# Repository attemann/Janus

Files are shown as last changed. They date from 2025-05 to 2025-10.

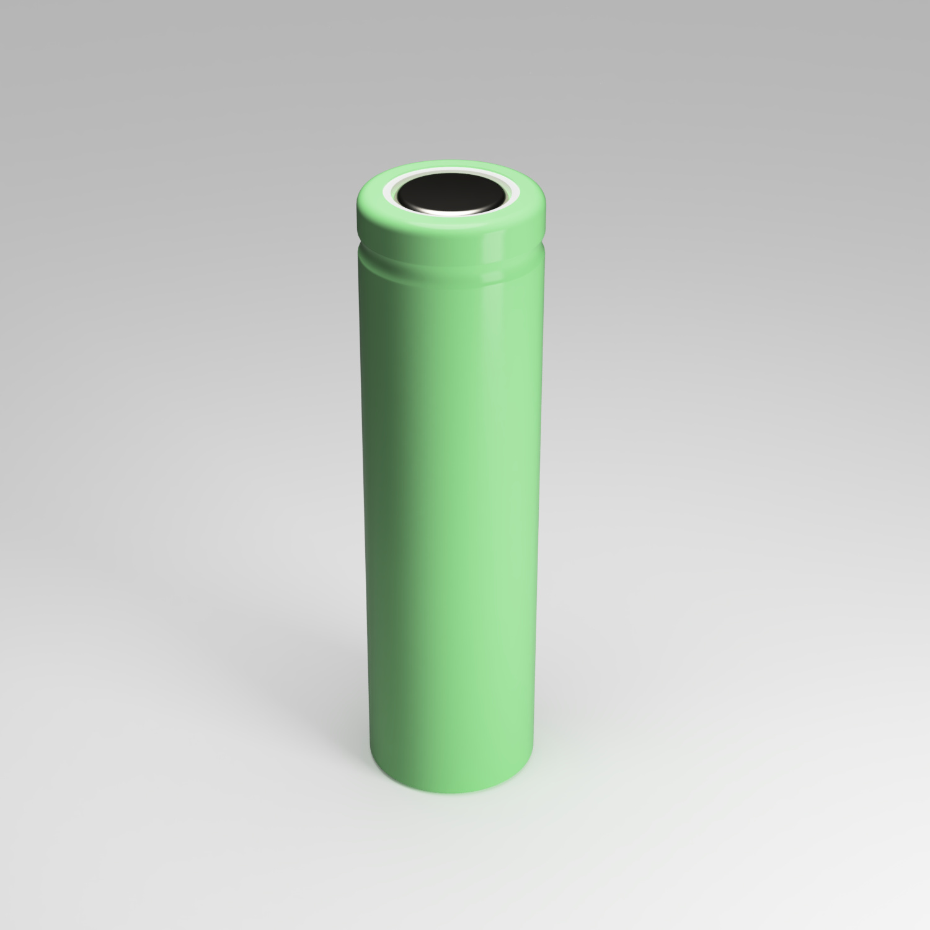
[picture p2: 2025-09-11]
Hardware/18650/Li Ion 18650 cell.jpg

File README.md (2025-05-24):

# RTKF3F – RTK-Based F3F Glider Training System

**Author:** Jan Olav Endrerud  
**Email:** joe2817@gmail.com  
**Version:** 15 May 2025

---

## Overview

RTKF3F is a high-precision, low-latency training system for F3F radio-controlled gliders using RTK GNSS technology. It detects base crossings automatically and provides real-time feedback without needing manned base stations.

---

## Features

- **RTK precision (≤10 cm)** for consistent flight detection
- **<20 ms latency** between event and audio feedback
- Fully **offline system** (no internet needed)
- Detailed **post-flight analysis** from logged events
- Compact airborne unit with GNSS and 868 MHz radio
- LCD and button interface on base station
- Designed for use on slopes with configurable A/B base orientation

---

## System Components

### Base Station (BS)

- UM980 RTK GNSS (base mode)
- ESP32-S3 microcontroller
- 2× RFM69HCW radios (TX: RTCM, RX: events)
- 2-line I2C LCD display
- Beeper for feedback
- 4-button user interface
- USB or battery powered (10+ hrs)

### Glider Unit (GU)

- UM980 RTK GNSS (rover mode)
- Seeed Studio XIAO ESP32-C6
- RFM69HCW radio (868 MHz)
- Beeper for status indication
- Max size: 40 × 20 mm (excluding antennas)
- Powered from RC battery

---

## Flight Operation

1. **Setup**
   - Place BS and perform GNSS survey-in
   - Select slope angle and A-base side
   - Set pilot location (PLOC)

2. **Flight**
   - Glider launches and crosses into task zone
   - GU detects base crossings and sends event to BS
   - BS triggers beeps and logs events

3. **Post-flight**
   - Use logs for analysis and performance improvement

---

## GU ↔ BS Communication

| Direction | Message | Description |
|---:|---|---|
| BS → GU | `MSG_FLIGHTSETTINGS` | Pilot offset, base side, slope angle |
| BS → GU | `MSG_RTCM` | RTCM3 corrections (1 Hz) |
| GU → BS | `EVT_*` Events | A/B base and safety line crossings |
| GU → BS | `EVT_ACK` | Acknowledgement of received settings |

**Event Codes:**
- `EVT_CROSS_A_IN`, `EVT_CROSS_B_OUT`, `EVT_AIRBORNE`, `EVT_LANDED`, etc.

---

## Wiring Overview

### Glider Unit (ESP32-C6)

| Pin | Function |
|---:|---|
| GPIO17  | UART TX → GNSS RX |
| GPIO18  | UART RX ← GNSS TX |
| GPIO10–12 | SPI (SCK, MOSI, MISO) |
| GPIO9 | SPI CS |
| GPIO8 | RFM69 DIO0 (IRQ) |

### Base Station (ESP32-S3)

| Pin | Function |
|---:|---|
| GPIO4/5 | UART to GNSS |
| GPIO6–9 | SPI & DIO0 for RFM RX/TX |
| GPIO18/19 | I2C LCD |
| GPIO20–23 | Buttons |

---

## Configuration Summary

### UM980 (Base)
```text
CFG-RTK-MODE = BASE
CFG-SURVEYIN-ENABLE = TRUE
CFG-SURVEYIN-MIN-DURATION = 120
CFG-SURVEYIN-POS-ACCURACY = 2.0
CFG-MSG UART2 RTCM3 1005/1074/1084/1094/1124 = 1Hz
```

### UM980 (Rover)
```text
CFG-RTK-MODE = ROVER
CFG-PORT UART2 = RTCM_INPUT
CFG-RATE = 25
CFG-MSG UART1 NAV-RELPOSNED = 25Hz
CFG-DYNMODEL = AIRBORNE 2g
```

---

## Development Roadmap

- [ ] Support for Jeti Ex-bus / F3FTool
- [ ] Safety line definition and events
- [ ] Optional voice/audio module

---

## License

MIT License

Copyright (c) 2025 Jan Olav Endrerud

Permission is hereby granted, free of charge, to any person obtaining a copy
of this software and associated documentation files (the “Software”), to deal
in the Software without restriction, including without limitation the rights
to use, copy, modify, merge, publish, distribute, sublicense, and/or sell
copies of the Software, and to permit persons to whom the Software is
furnished to do so, subject to the following conditions:

The above copyright notice and this permission notice shall be included in all
copies or substantial portions of the Software.

THE SOFTWARE IS PROVIDED “AS IS”, WITHOUT WARRANTY OF ANY KIND, EXPRESS OR
IMPLIED, INCLUDING BUT NOT LIMITED TO THE WARRANTIES OF MERCHANTABILITY,
FITNESS FOR A PARTICULAR PURPOSE AND NONINFRINGEMENT. IN NO EVENT SHALL THE
AUTHORS OR COPYRIGHT HOLDERS BE LIABLE FOR ANY CLAIM, DAMAGES OR OTHER
LIABILITY, WHETHER IN AN ACTION OF CONTRACT, TORT OR OTHERWISE, ARISING FROM,
OUT OF OR IN CONNECTION WITH THE SOFTWARE OR THE USE OR OTHER DEALINGS IN THE
SOFTWARE.
---

## Contact

Feel free to reach out with ideas or improvements:  
📧 joe2817@gmail.com

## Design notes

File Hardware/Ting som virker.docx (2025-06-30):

Slå av melding

UNLOG COM1 GPGGA

Slå på melding

gpgga COM1 1

Sette i RTK base modus

MODE BASE TIME 60

→ Mål i 60 sekunder, og bruk snittet av posisjonene som baseposisjon.

Du kan endre 60 til opp til 3600 sekunder for høyere nøyaktighet.

(Se også MODE BASE TIME 60 5 for å legge til et posisjonstoleransekrav.)

ESP32-S3-Devkit1-C sender

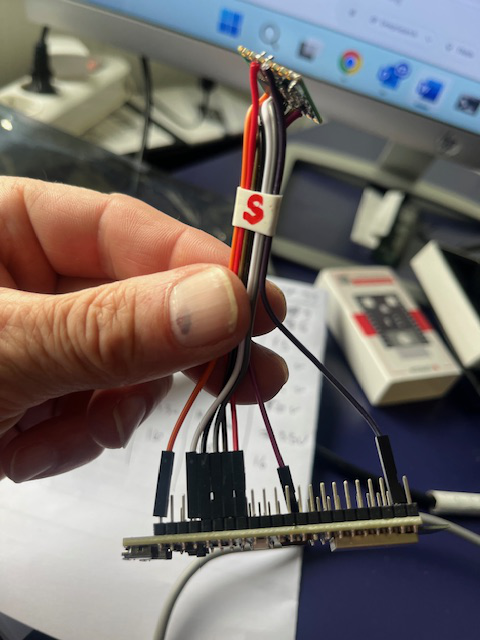
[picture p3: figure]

ESP32-S3-Devkit1-C mottager

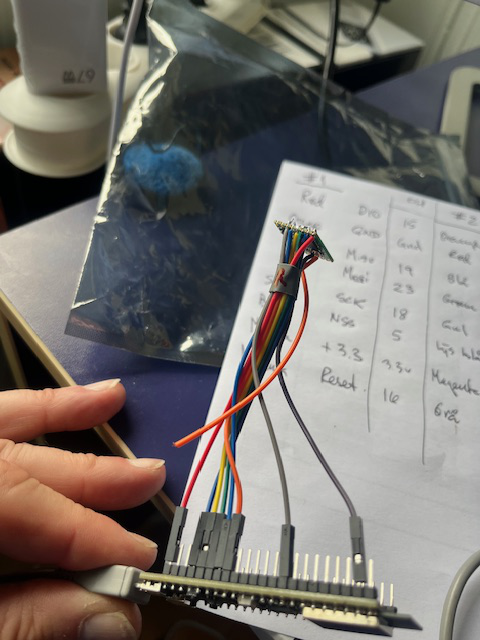
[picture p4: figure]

#include <RFM69.h>

#include <SPI.h>

#define NODE_ID 2 // This is the Gateway ID (receiver)

#define NETWORK_ID 100

#define FREQUENCY RF69_868MHZ

#define RFM69_CS 10

#define RFM69_IRQ 9

#define RFM69_RST -1

RFM69 radio(RFM69_CS, RFM69_IRQ, true);

void

setup() {

Serial.begin(115200);

delay(10);

SPI.begin(12, 13, 11, 10); // Explicit SPI pins, matching sender

if (RFM69_RST != -1) {

pinMode(RFM69_RST, OUTPUT);

digitalWrite(RFM69_RST, LOW);

delay(10);

digitalWrite(RFM69_RST, HIGH);

delay(10);

}

Serial.println("Starting RFM69 receiver...");

if (!radio.initialize(FREQUENCY, NODE_ID, NETWORK_ID)) {

Serial.println("Radio initialization failed!");

while (1);

}

radio.setHighPower();

radio.encrypt(NULL); // No encryption, matching sender

Serial.println("RFM69 initialized");

}

void loop() {

if (radio.receiveDone()) { // Check if data is received

if (radio.DATALEN > 0) {

Serial.print("Received from Node ");

Serial.print(radio.SENDERID);

Serial.print(": [");

for (byte i = 0; i < radio.DATALEN; i++) {

Serial.print((char)radio.DATA[i]);

}

Serial.print("], RSSI: ");

Serial.println(radio.RSSI);

// Acknowledge receipt (optional, but useful for reliability)

if (radio.ACKRequested()) {

radio.sendACK();

Serial.println("ACK sent");

}

// Blink LED to indicate reception

digitalWrite(RGB_BUILTIN, HIGH);

delay(200);

digitalWrite(RGB_BUILTIN, LOW);

}

}

}

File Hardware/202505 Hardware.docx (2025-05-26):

## 20×40 mm target with minimal BOM and full support for:

- Native USB
- RFM69HCW (SPI)
- UM980 GNSS (UART)
- Optional buzzer
- Power from USB or 5–8V

## ESP32-C6FH4 Hardware Design Overview

📌 Core Specs (C6FH4)

- QFN-48, 5×5 mm
- Native USB-CDC (no external USB-UART needed)
- 4 MB flash integrated
- Runs at 3.3
- No shielding required if Wi-Fi/BLE is unused
- 12 MHz crystal recommended

## Required Components and Connections

1. Power Supply

You want to support:

- USB (5V)
- External 5–8V

Recommended:

- MP2338 buck converter (efficient, 5–24 V → 3.3 V)
- OR AP2112K or XC6220 (LDO, 5–6 V → 3.3 V)

🔌 Connect 3.3 V output to:

- VDD3P3_CPU
- VDD3P3_RTC
- Decouple with 10 µF + 0.1 µF caps

2. USB Interface (native USB-CDC)

Pins:

- GPIO19 → USB D−
- GPIO20 → USB D+

Passives:

- 22 Ω series resistors on D+ and D− (optional if short traces)
- Optional ESD protection (e.g., USBLC6-2SC6)

Connector:

- USB-C (with CC resistors) or micro-USB

3. Crystal

- 12 MHz crystal (e.g., ECS-120-20-4X)
- Load caps: 2 × 18–22 pF
- Use close layout with ground guard

4. RFM69HCW

Interface: SPI

Pins (example):

- MOSI → GPIO6
- MISO → GPIO5
- SCK → GPIO4
- NSS → GPIO7
- DIO0 → GPIO8 (interrupt)

Use 0.1 µF decoupling cap close to VCC pin.

5. UM980 GNSS Module

Interface: UART

Pins (example):

- TXD → GPIO1
- RXD → GPIO2

Baud rate: 115200 (typical)

Level shifting not needed — both run at 3.3 V

6. Miniature Beeper

Use GPIO + NPN transistor to drive buzzer:

- GPIO10 → 1kΩ → base of 2N3904
- Emitter → GND
- Collector → Negative side of buzzer

Positive side → 3.3V

Buzzer: 5×5×1.8 mm passive piezo (e.g., CPT-5018C)

7. Boot/Reset Logic (Optional)

- GPIO9 → BOOT (pull LOW to enter flash mode)
- EN → reset (pull LOW to reset chip)

You can use RTS/DTR from USB-to-PC to control these via a transistor auto-reset circuit (or omit if using USB-native flashing only).

8. Programming

No USB-to-UART chip needed. Flash directly using:

esptool.py --chip esp32c6 --port COMx write_flash 0x0 firmware.bin

🧠 Flash Memory for Settings

Use ESP32 NVS (Non-Volatile Storage) API:

- Stores key-value data in internal flash
- Reliable across reboots and power loss
- Available in Arduino and ESP-IDF

✅ Pin Usage Summary (example)

Purpose ESP32-C6 Pin

USB D− GPIO19

USB D+ GPIO20

RFM69 NSS GPIO7

RFM69 DIO0 GPIO8

SPI MOSI GPIO6

SPI MISO GPIO5

SPI SCK GPIO4

UM980 RX GPIO1

UM980 TX GPIO2

Buzzer GPIO10

BOOT (option) GPIO9

EN (reset) EN pin

🧩 1. USB-C Connection Diagram (Native USB for ESP32-C6)

✅ Objective:

- Use USB-C connector to connect ESP32-C6FH4’s native USB-CDC interface
- Add CC pull-down resistors so hosts detect it as a USB device
- Add optional ESD protection

📌 USB-C Pinout (for USB 2.0 only)

You only need USB 2.0 D+/D−, GND, and VBUS:

USB-C Receptacle (Front View, PCB side)

┌───────────────┐

| A1 ─ GND | B1 ─ GND

| A2 ─ TX1+ | B2 ─ TX2+

| A3 ─ TX1− | B3 ─ TX2−

| A4 ─ VBUS | B4 ─ VBUS

| A5 ─ CC1 * | B5 ─ CC2 *

| A6 ─ D+ →───┐| B6 ─ D+ →──┐

| A7 ─ D− →───┘| B7 ─ D− →──┘

| A8 ─ SBU1 | B8 ─ SBU2

| A9 ─ VBUS | B9 ─ VBUS

| A10─ RX2− | B10─ RX1−

| A11─ RX2+ | B11─ RX1+

| A12─ GND | B12─ GND

└───────────────┘

🔧 Schematic Snippet

VBUS ──────> 5V input to MP2338

D+ (A6, B6) ──────> GPIO20 (ESP32-C6)

D− (A7, B7) ──────> GPIO19 (ESP32-C6)

CC1 ───┬── 5.1kΩ ──> GND

└── Optional ESD diode (e.g., USBLC6)

CC2 ───┬── 5.1kΩ ──> GND

└── (same)

GND ───────────────> GND

⚠️ Notes:

- Use one 5.1 kΩ pull-down on each CC pin (CC1, CC2) to signal to the host that your device is a USB peripheral.
- Do not connect TX/RX or SBU — those are for USB 3.0 or alternate modes.
- Add 22 Ω resistors in series on D+ and D− (optional, if trace is <1" and well-matched).
- Optional: Add TVS diode array (e.g. ESD protection: USBLC6-2SC6 or PESD5V0S1UL).

⚡ 2. Power Tree with MP2338 (5–8 V input)

✅ Requirements:

- Input: 5–8 V from USB or external
- Output: 3.3 V to power ESP32-C6, RFM69, UM980, and buzzer

📌 MP2338 Setup (Simplified)

Pin | Connect to
VIN | 5–8 V input (VBUS or ext)
EN | Tie to VIN (via 10k pull-up or direct)
SW | 3.3V output node (to inductor)
FB | Feedback from VOUT (voltage divider)
GND | Ground plane
BST | Bootstrap cap (0.1 µF) between SW and BST

🔧 Schematic Snippet

plaintext

CopyEdit

VIN (USB or ext) ─────┐

[CIN] 10µF

VIN (MP2338)

EN ← VIN

+--------+

| MP2338 |

+--------+

SW ────┬───→ Inductor 2.2 µH →────┐

[D1] Schottky diode |

| [COUT] 10µF

GND |

VOUT (3.3 V)

↓

┌───────────────────────────────┐

│ Powers: ESP32, RFM69, UM980 │

└───────────────────────────────┘

FB → voltage divider: 3.3V = VREF × (1 + R1/R2)

Use: R1 = 100k, R2 = 100k (to get ~3.3V)

CIN: 10–22 µF
COUT: 10–22 µF
Inductor: 2.2–4.7 µH
D1: 1A Schottky (e.g., SS14)

🧠 Optional Enhancements

- Add reverse-polarity protection on VIN (Schottky or PFET)
- Add a simple PTC fuse on VBUS
- Use a buck-boost if needing 3.3 V from <5 V sources occasionally

✅ Combined Summary

- USB-C with 5.1 k CC resistors and D+/D− → ESP32-C6
- MP2338 drops 5–8 V input to clean 3.3 V for all components
- Minimal parts, <20×40 mm layout achievable
- Fully USB flashable with no buttons, no UART chi

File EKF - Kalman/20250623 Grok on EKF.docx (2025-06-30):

In F3F RC model aircraft gliding, turn A and B must be detected with high precision. Distance between A and B base is 100 meters. RTK base will be positioned > 100 meters from pilot and bases. Gliders are performing high-G turns at each base (15-20G), flying in 100-200 km/h. I want to use RTK in RELPOSNED mode, rover unit in glider, fixed RTK base close to pilot. Using UM980 RTK GPSes. Goal is at least decimenter precision, best centimeter level. Turn detection will be position relative to RTK base. MIcrocontroller in glider will be ESP32. 868 MHz radio will report turn detection back to pilot.

- I want an overview ofsuitable algorithms to integrate 6 axis IMU with GNSS data to improve precision
- suitable IMUs

To achieve high-precision turn detection (decimeter to centimeter level) for F3F RC model aircraft gliding with high-G turns (15-20G) at speeds of 100-200 km/h, integrating a 6-axis IMU with GNSS data (specifically using the UM980 RTK GPS in RELPOSNED mode) and an ESP32 microcontroller is a feasible approach. The goal is to detect turns at bases A and B, 100 meters apart, with the RTK base stationed >100 meters from the pilot and bases, and report detections via an 868 MHz radio. Below is an overview of suitable algorithms for IMU-GNSS integration and recommended IMUs for high-G environments.

1. Algorithms for Integrating 6-Axis IMU with GNSS Data

To achieve decimeter to centimeter-level precision for turn detection, you need robust sensor fusion algorithms that combine high-rate IMU data (accelerometers and gyroscopes) with GNSS position data from the UM980 RTK GPS. The high-G turns and high speeds demand algorithms that can handle dynamic motion, mitigate IMU drift, and leverage RTK’s centimeter-level accuracy. Below are suitable algorithms, focusing on their applicability to your F3F gliding scenario:

a. Extended Kalman Filter (EKF) - Tightly Coupled Integration

Description: The EKF is widely used for IMU-GNSS integration, particularly in tightly coupled systems where raw GNSS measurements (pseudoranges, carrier phases) are fused with IMU data to estimate position, velocity, and attitude. It accounts for non-linear dynamics and sensor noise, making it suitable for high-G, high-speed environments like F3F gliding.

Advantages:

- Provides centimeter-level accuracy when RTK corrections are available, leveraging the UM980’s multi-constellation (GPS, GLONASS, Galileo, BeiDou) and dual-frequency (L1/L2) capabilities.
- Mitigates IMU drift by continuously updating with GNSS data, critical for sustained high-G maneuvers.
- Handles GNSS outages (e.g., brief signal loss during turns) by relying on IMU dead-reckoning.
- Supports RELPOSNED mode by incorporating relative positioning data directly into the state estimation.

Implementation:

- State vector typically includes position, velocity, orientation (quaternion), and sensor biases (accelerometer and gyroscope).
- IMU data (sampled at 100-1000 Hz) predicts the state, while GNSS data (1-20 Hz from UM980) corrects it.
- Use a 42+ state EKF (as in high-end INS systems) to model complex error sources like IMU biases, scale factors, and GNSS multipath.
- The ESP32’s processing power (dual-core, up to 240 MHz) can handle a simplified EKF for real-time computation, though optimization (e.g., fixed-point arithmetic) may be needed.

Challenges:

- Computational complexity may strain the ESP32, requiring efficient code or precomputed matrices.
- Requires precise time synchronization between IMU (high-rate) and GNSS (lower-rate, up to 20 Hz for UM980) to avoid latency errors.

Suitability: Ideal for F3F due to its robustness in dynamic environments and ability to leverage RTK’s high precision. Use open-source libraries like RTKLIB for RTK processing and fuse with IMU data via custom EKF code.

b. Loosely Coupled Kalman Filter

Description: In a loosely coupled approach, the GNSS receiver (UM980) computes a position solution independently, which is then fused with IMU data using a Kalman filter to refine position and velocity estimates.

Advantages:

- Simpler to implement on the ESP32 due to lower computational demands.
- Works well when RTK corrections are consistently available, providing centimeter-level accuracy.
- Easier to integrate with the UM980’s NMEA output (e.g., GGA, RMC messages).

Challenges:

- Less robust during GNSS outages or multipath errors (common in dynamic turns near terrain).
- Does not fully exploit raw GNSS measurements, potentially██

Implementation:

- Use UM980’s RELPOSNED output (relative position in NED frame) to provide high-precision position data.
- IMU data corrects short-term GNSS errors and smooths position estimates during high-G turns.
- Suitable for real-time turn detection by comparing position against known base coordinates (A and B).

Challenges (continued):

- May struggle with high-G dynamics if GNSS signal quality degrades, as it relies on processed GNSS solutions rather than raw measurements.

Suitability: Viable for F3F if RTK corrections are reliable, but less robust than tightly coupled EKF in challenging GNSS conditions. Simpler to implement on resource-constrained platforms like the ESP32.

c. Attitude-Estimation-Free GNSS/IMU Integration

Description: A novel approach that avoids explicit attitude estimation, using constraints based on accelerometer magnitude and gyroscope angular changes to fuse IMU and GNSS data.

Advantages:

- Reduces computational load by eliminating 3D attitude from the state vector, suitable for the ESP32’s limited processing power.
- Robust to IMU mounting misalignments, which is beneficial for RC gliders where precise IMU alignment may be challenging.
- Improves accuracy in GNSS-challenged environments (e.g., multipath during low-altitude turns) by relying on IMU constraints.

Implementation:

- Uses accelerometer data to constrain position updates based on acceleration magnitude.
- Gyroscope data constrains velocity vector angles, aiding turn detection.
- Can be implemented with a simpler filter (e.g., modified EKF or particle filter) to reduce ESP32 computational load.
- Integrates UM980’s RELPOSNED output for relative positioning to bases A and B.

Challenges:

- Less mature than EKF, with fewer off-the-shelf implementations.
- May require custom tuning for high-G environments to ensure stability.
- Suitability: Promising for F3F due to its computational efficiency and robustness to GNSS errors, but requires custom algorithm development and validation for high-G dynamics.

d. Deep Learning-Based Sensor Fusion

Description: Uses neural networks (e.g., LSTM, ConvNet) to learn complex relationships between raw IMU measurements and GNSS data, reducing drift and improving position estimates.

Advantages:

- Can implicitly correct IMU errors (bias, noise) without explicit modeling, improving accuracy in high-G turns.
- Adapts to complex motion patterns in F3F gliding through training on relevant datasets.

Challenges:

- Requires significant computational resources, likely infeasible for real-time processing on the ESP32.
- Needs extensive training data (e.g., high-precision IMU or GNSS ground truth), which may be hard to collect for F3F-specific maneuvers.
- Not yet widely validated for high-G, high-speed scenarios like F3F.

Suitability: Less practical for real-time use on the ESP32 due to computational constraints, but could be used offline for post-processing or training a simpler model for deployment.

Recommended Algorithm

Tightly Coupled EKF: This is the most suitable for F3F gliding due to its ability to leverage the UM980’s raw RTK measurements (centimeter-level accuracy) and handle high-G dynamics with IMU dead-reckoning. It balances precision and robustness, though it requires careful implementation to fit within the ESP32’s capabilities. Use RTKLIB for RTK processing and a custom EKF for fusion, with time synchronization ensured via GPS clock signals.

Implementation Notes:

- Sample IMU at 100-1000 Hz to capture high-G turn dynamics (15-20G, rapid angular changes).
- Use UM980’s 20 Hz output for frequent corrections.
- Implement turn detection by comparing RELPOSNED coordinates against known base positions (A and B, 100 m apart) with a threshold (e.g., 10 cm radius around base).
- Transmit turn detection events via 868 MHz radio using a lightweight protocol (e.g., simple binary messages).

2. Suitable IMUs for High-G Turns

For F3F gliding, the IMU must withstand high-G forces (15-20G), provide high sampling rates (100-1000 Hz) for dynamic motion, and have low noise and drift to minimize errors during short GNSS outages. It should also be lightweight, compact, and compatible with the ESP32’s interfaces (e.g., SPI, I2C). Below are recommended 6-axis IMUs (3-axis accelerometer + 3-axis gyroscope) suitable for this application:

a. Bosch BMI160

Specifications:

- Accelerometer Range: ±16g (sufficient for 15-20G turns).
- Gyroscope Range: ±2000°/s (handles high angular rates in turns).
- Sampling Rate: Up to 1600 Hz, suitable for capturing rapid dynamics.
- Noise Density: ~0.004 m/s²/√Hz (accelerometer), ~0.007°/s/√Hz (gyroscope).
- Interface: I2C/SPI, compatible with ESP32.
- Size/Weight: 3x3x0.83 mm, ~0.5g, ideal for lightweight RC gliders.
- Power: Low power (~0.9 mA in high-performance mode).

Advantages:

- Cost-effective and widely available.
- Robust for high-G environments, used in UAVs and automotive applications.
- Small size and low power suit RC glider constraints.

Challenges:

- Tactical-grade performance but may exhibit drift over long periods without GNSS correction.
- Requires calibration for bias and scale factor errors.

Suitability: Excellent for F3F due to its high-G tolerance, compact size, and ESP32 compatibility. Pair with EKF for drift correction.

b. Inertial Sense μINS

Specifications:

- Accelerometer Range: ±16g (extendable to ±40g in some configurations).
- Gyroscope Range: ±2000°/s.
- Sampling Rate: Up to 1000 Hz.
- Noise Density: Tactical-grade, comparable to high-end MEMS (specific values depend on model)
- Interface: UART/SPI, ESP32-compatible.
- Size/Weight: ~17x17x7 mm, ~2g, slightly heavier but compact.

Power: ~50 mA (higher than BMI160 but manageable).

Advantages:

- Tactical-grade performance with low noise and drift, ideal for high-G turns.
- Integrated GNSS option (can be used as backup or for testing).
- Proven in UAV and robotics applications.

Challenges:

- Higher cost than BMI160 (~$100-$200 vs. ~$10).
- Slightly larger and heavier, though still suitable for RC gliders.
- Suitability: High-performance choice for F3F, especially if budget allows, due to its robustness and precision in dynamic environments.

c. Analog Devices ADIS16488A

Specifications:

- Accelerometer Range: ±18g (suitable for 15-20G).
- Gyroscope Range: ±450°/s (may need configuration for extreme turn rates).
- Sampling Rate: Up to 2460 Hz, excellent for high-G dynamics.
- Noise Density: ~0.0045 m/s²/√Hz (accelerometer), ~0.005°/s/√Hz (gyroscope).
- Interface: SPI, compatible with ESP32.
- Size/Weight: ~47x47x14 mm, ~16g, heavier and larger than others.
- Power: ~200 mA, higher consumption.

Advantages:

- High precision and low noise, designed for aerospace applications.
- Robust in high-vibration, high-G environments.

Challenges:

- Significantly more expensive (~$1000+).
- Larger size and weight may be less ideal for small RC gliders.
- Higher power draw requires careful power management.

Suitability: Overkill for most F3F applications due to cost and size, but viable if maximum precision is needed and budget/space allow.

Recommended IMU

Bosch BMI160: Best balance of performance, cost, size, and power for F3F gliding. Its ±16g accelerometer and ±2000°/s gyroscope handle high-G turns, and its low cost (~$10) and small size (3x3 mm) make it ideal for RC gliders. The high sampling rate (up to 1600 Hz) ensures accurate capture of turn dynamics, and I2C/SPI interfaces integrate easily with the ESP32. Use with a tightly coupled EKF to achieve centimeter-level turn detection accuracy.

Additional Considerations

- Time Synchronization: Ensure precise synchronization between IMU and UM980 GNSS data using the GPS clock (PPS signal) to align high-rate IMU (100-1000 Hz) with GNSS (20 Hz). The ESP32 can use GPIO pins to capture PPS for sub-millisecond accuracy. Turn Detection Logic: Implement a simple algorithm on the ESP32 to detect when the glider’s RELPOSNED position (from UM980) falls within a predefined radius (e.g., 10 cm) of base A or B coordinates. Trigger an 868 MHz radio message (e.g., “TURN_A” or “TURN_B”) upon detection.
- Power Management: Use a lightweight LiPo battery (e.g., 3.7V, 500mAh) to power the ESP32, BMI160, UM980, and 868 MHz radio. Optimize firmware to minimize power draw (e.g., low-power modes for ESP32 when not processing).
- Calibration: Pre-flight calibration of IMU biases and scale factors is critical to minimize drift during high-G turns. Use ground-based GNSS data for initial alignment.
- RTK Corrections: Ensure the RTK base (>100 m from pilot and bases) provides reliable corrections via 868 MHz radio or another link. UM980’s multi-constellation support enhances robustness in dynamic environments.
- Software: Use RTKLIB for RTK processing (run on a ground station or precompute corrections) and program the ESP32 in C/C++ (e.g., Arduino or ESP-IDF framework) for EKF and turn detection logic. Libraries like TinyEKF can simplify EKF implementation.

Summary

- Algorithm: A tightly coupled EKF is recommended for integrating 6-axis IMU and UM980 RTK GNSS data, offering centimeter-level precision and robustness for high-G turns. It leverages raw GNSS measurements and corrects IMU drift effectively
- IMU: The Bosch BMI160 is the best choice due to its high-G tolerance (±16g), high sampling rate (up to 1600 Hz), low cost, and compact size, making it ideal for RC gliders and ESP32 integration.

System Overview:

- UM980 rover in the glider provides RELPOSNED data (centimeter-level) at 20 Hz.
- BMI160 samples at 100-1000 Hz, feeding high-rate motion data to the EKF.
- ESP32 runs the EKF, detects turns by comparing position to base coordinates, and transmits results via 868 MHz radio.
- RTK base provides corrections, ensuring high precision even at >100 m distance.

This setup achieves the desired decimeter to centimeter-level precision for turn detection in F3F gliding, handling the challenges of high-G turns and high speeds effectively. For implementation, start with the BMI160 and RTKLIB, and prototype the EKF on the ESP32 using open-source libraries, ensuring thorough testing in simulated high-G conditions.

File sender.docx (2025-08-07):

BASE_SURVEYING: Survey complete. Enabling RTCM...

GPS: Sending command: unlog

$command,unlog,response: OK*21

GPS: Sending command: rtcm1033 com2 10.0

$command,rtcm1033 com2 10.0,response: OK*1B

Sending �+�?

GPS: Sending command: rtcm1006 com2 10.0

$command,rtcm1006 com2 10.0,response: OK*1D

Sending �+�?

GPS: Sending command: rtcm1074 com2 1.0

$command,rtcm1074 com2 1.0,response: OK*28

Sending �+�?

GPS: Sending command: rtcm1124 com2 1.0

$command,rtcm1124 com2 1.0,response: OK*2C

Sending �+�?

GPS: Sending command: rtcm1084 com2 1.0

�>��$x��X���

�6^�Q��rC X�� ��� _բ���'�'��1$A�#n�� ��x��0��ɺ�"��G��

��x<�����w�b��?�'��|dc������݅�Q#R�#P��,��@Q��F@X�A H0 �EWN��©�%�$'�%�ě�Ku�m<�)���[GwP�y;>qT�����wx�q-��AH~׵~އ�Fj����{����Xv�A�?�g"��x9��W�a����N�8?��������0�uUWUU7UUU@<�Q���>���RH������$command,rtcm1084 com2 1.0,response: OK*27

Sending �+�?

GPS: Sending command: rtcm1094 com2 1.0

$command,rtcm1094 com2 1.0,response: OK*26

Sending �+�?

# Name | Freq | State | Sent | Description

1: rtcm1033 | 10.00 Hz | ENABLED | 0 | Antenna + Firmware

2: rtcm1006 | 10.00 Hz | ENABLED | 0 | Stat. Ref (with height)

3: rtcm1074 | 1.00 Hz | ENABLED | 0 | GPS MSM4

4: rtcm1124 | 1.00 Hz | ENABLED | 0 | BeiDou MSM4

5: rtcm1084 | 1.00 Hz | ENABLED | 0 | GLONASS MSM4

6: rtcm1094 | 1.00 Hz | ENABLED | 0 | Galileo MSM4

GPS: Sending command: saveconfig

$command,saveconfig,response: OK*55

BASE_SURVEYING: RTCM config done, entering OPERATING mode.

111 bytes RTCM1074

Sending fragmented RTCM message

RTCM_Fragmenter: Sending 111 bytes in fragments

RTCM_Fragmenter: Total fragments = 2

RTCM_Fragmenter: Sending fragment 1 of 2

0A 00 02 D3 00 69 43 20 00 58 E9 2B 62 00 20 20

A2 02 80 80 00 00 00 20 20 00 00 5F D6 8A 8E 92

98 9E A0 96 60 C4 D0 55 07 93 C4 61 8E A7 CC 3F

F9 05 85 E2 8C 3E DE 6B C0 DF CA 81 68

RTCM_Fragmenter: Sending fragment 2 of 2

0A 01 02 0D 77 1B 18 BD 4F 45 F0 FF 7F C3 FD 80

5E 3F 01 79 4F F7 98 23 DE 6F 0F CA 5B C2 CF C3

F5 DB DF D7 7A DB B9 BB BB BB BB 00 13 C8 CC AD

48 D4 32 D2 B8 06 1A C6

74 bytes RTCM1084

Sending fragmented RTCM message

RTCM_Fragmenter: Sending 74 bytes in fragments

RTCM_Fragmenter: Total fragments = 2

RTCM_Fragmenter: Sending fragment 1 of 2

0A 00 02 D3 00 44 43 C0 00 89 15 80 22 00 20 01

02 05 00 00 00 00 00 20 80 00 00 7D 22 24 A5 A1

A9 D2 CE 47 BC E1 99 C0 37 A9 2F 56 20 83 5F BF

1E 19 A4 C0 00 01 EA 4C 2F A9 32 A0 83

RTCM_Fragmenter: Sending fragment 2 of 2

0A 01 02 7F 7F 7D 9F 61 77 76 04 8C CA E4 70 80

F2 E4 49

129 bytes RTCM1094

Sending fragmented RTCM message

RTCM_Fragmenter: Sending 129 bytes in fragments

RTCM_Fragmenter: Total fragments = 3

RTCM_Fragmenter: Sending fragment 1 of 3

0A 00 03 D3 00 7B 44 60 00 58 E9 2B 62 00 20 0E

40 04 00 28 00 00 00 20 01 00 00 7F FE B6 A6 AE

AA B8 9A AB 00 45 E4 26 30 0E DF 10 3E AF 5D 54

A1 7F C2 FC EF 86 DE 31 F9 D3 EE BF 7C

RTCM_Fragmenter: Sending fragment 2 of 3

0A 01 03 EE EE E5 29 0A 04 FF F8 FF 61 EA F3 8F

AB CF 60 5F CC C0 00 01 EF 81 67 BE 12 3F E7 5E

FF 9B 1B F7 CD D7 DF 25 41 4A 29 85 2A 23 FF F6

97 FF E1 F7 76 17 57 75 57 57 40 00 42

RTCM_Fragmenter: Sending fragment 3 of 3

0A 02 03 DC 2B 46 E4 B0 40 D4 D1 48 F8 9A B9 30

187 bytes RTCM1124

Sending fragmented RTCM message

RTCM_Fragmenter: Sending 187 bytes in fragments

RTCM_Fragmenter: Total fragments = 4

RTCM_Fragmenter: Sending fragment 1 of 4

0A 00 04 D3 00 B5 46 40 00 58 E8 50 A0 00 20 00

96 04 08 48 30 00 00 20 82 00 01 45 57 4E C4 EE

C2 A9 C1 25 AA 24 27 AB 25 A6 C4 BB 24 AA 4A F6

1C 65 12 3C F2 29 1E 40 2E 9A 9D 08 B0

RTCM_Fragmenter: Sending fragment 2 of 4

0A 01 04 48 E0 6A 3D 94 75 F8 E9 70 39 20 5A 81

FE 43 9E 87 4A EE 79 A2 33 40 A8 9D 41 4F A2 29

0A 7C 94 82 28 9D E3 FE FC 00 00 10 00 00 78 23

D3 E0 94 20 7B 36 61 EC DC 07 B2 60 03

RTCM_Fragmenter: Sending fragment 3 of 4

0A 02 04 97 80 0E 40 40 7F A8 01 FF 98 07 FE 77

DC D5 9E 88 92 7A 23 38 09 D4 08 27 56 60 9D 76

85 3C E8 14 F9 78 53 DD B6 01 75 75 77 57 55 37

57 55 75 40 00 00 3C D3 51 B6 FB B2 3E

RTCM_Fragmenter: Sending fragment 4 of 4

0A 03 04 FD 0E D4 FC 52 48 E4 F1 B7 10 54 70 A4

27 bytes RTCM1006

Sending full RTCM message

D3 00 15 3E E0 00 03 87 24 78 C1 10 81 58 F1 BC

AE 0C E8 36 5E 9E 00 00 51 00 C1

74 bytes RTCM1033

Sending fragmented RTCM message

RTCM_Fragmenter: Sending 74 bytes in fragments

RTCM_Fragmenter: Total fragments = 2

RTCM_Fragmenter: Sending fragment 1 of 2

0A 00 02 D3 00 44 40 90 00 0E 41 44 56 4E 55 4C

4C 41 4E 54 45 4E 4E 41 FF 05 61 30 30 30 31 0D

55 4E 49 43 4F 52 45 20 55 4D 39 38 30 0B 31 33

35 30 34 2D 32 38 30 35 31 10 66 66 33

RTCM_Fragmenter: Sending fragment 2 of 2

0A 01 02 62 34 38 39 39 33 30 34 35 37 65 63 65

62 94 E3

120 bytes RTCM1074

Sending fragmented RTCM message

RTCM_Fragmenter: Sending 120 bytes in fragments

RTCM_Fragmenter: Total fragments = 3

RTCM_Fragmenter: Sending fragment 1 of 3

0A 00 03 D3 00 72 43 20 00 58 E9 3B 02 00 20 60

A2 02 80 80 00 00 00 20 20 00 00 57 F5 A4 22 A3

A4 A6 27 A8 25 E6 26 04 4F 06 50 59 34 46 18 65

82 23 FE 31 F8 74 86 87 6D 1D A6 12 CC

RTCM_Fragmenter: Sending fragment 2 of 3

0A 01 03 A7 7D 9D 07 FF 97 97 34 9C 00 00 01 1F

D6 83 1F BA 0C 7E 47 A1 E3 1E 87 B8 86 11 4E 18

4C 6F F6 61 00 3F C6 79 79 1B E5 E9 80 65 CD DD

DD DE 58 00 39 3C 6C CA D4 6C BF 25 0B

RTCM_Fragmenter: Sending fragment 3 of 3

0A 02 03 80 4A 12 56

74 bytes RTCM1084

Sending fragmented RTCM message

RTCM_Fragmenter: Sending 74 bytes in fragments

RTCM_Fragmenter: Total fragments = 2

RTCM_Fragmenter: Sending fragment 1 of 2

0A 00 02 D3 00 44 43 C0 00 89 15 8F C2 00 20 01

02 05 00 00 00 00 00 20 80 00 00 7D 22 24 A5 A1

A9 92 C6 4D BB EA C3 D2 86 44 00 8B D6 7E 32 04

5E AC 34 C0 00 00 11 01 B0 44 0B 1E 7E

RTCM_Fragmenter: Sending fragment 2 of 2

0A 01 02 72 84 07 FB 61 77 76 04 8C C8 E4 50 80

45 C1 25

120 bytes RTCM1074

Sending fragmented RTCM message

RTCM_Fragmenter: Sending 120 bytes in fragments

RTCM_Fragmenter: Total fragments = 3

RTCM_Fragmenter: Sending fragment 1 of 3

0A 00 03 D3 00 72 43 20 00 58 E9 4A A2 00 20 60

A2 02 80 80 00 00 00 20 20 00 00 57 F5 A4 22 A3

A4 A6 27 A8 25 E5 E6 04 53 06 D0 59 2C 46 17 F3

D5 F3 0F DC 0F C7 F8 52 A0 B4 20 5A 01

RTCM_Fragmenter: Sending fragment 2 of 3

0A 01 03 34 81 EF E3 0D 80 63 06 5C 00 00 1F 98

58 FD C0 DF F7 02 78 14 B6 00 53 0A 00 58 54 01

68 80 07 AA 5F 18 21 F8 05 A5 E0 1B 50 65 CD DD

DD DE 58 00 39 3C 8B CA CC 6D 41 25 0B

RTCM_Fragmenter: Sending fragment 3 of 3

0A 02 03 80 BB 06 1F

74 bytes RTCM1084

Sending fragmented RTCM message

RTCM_Fragmenter: Sending 74 bytes in fragments

RTCM_Fragmenter: Total fragments = 2

RTCM_Fragmenter: Sending fragment 1 of 2

0A 00 02 D3 00 44 43 C0 00 89 15 9F 62 00 20 01

02 05 00 00 00 00 00 20 80 00 00 7D 22 24 A5 A1

A9 52 C6 51 BB 73 F4 E4 E7 DE FB C1 D8 79 2C 4A

1F 3F 3E 40 00 01 F7 C1 0F DF 04 A0 79

RTCM_Fragmenter: Sending fragment 2 of 2

0A 01 02 8B F8 93 83 61 77 76 04 8C C8 E4 51 00

92 EA EA

129 bytes RTCM1094

Sending fragmented RTCM message

RTCM_Fragmenter: Sending 129 bytes in fragments

RTCM_Fragmenter: Total fragments = 3

RTCM_Fragmenter: Sending fragment 1 of 3

0A 00 03 D3 00 7B 44 60 00 58 E9 4A A2 00 20 0E

40 04 00 28 00 00 00 20 01 00 00 7F FE B6 A6 AE

AA B8 9A AB 01 45 64 2E 2E 0D 5F 10 51 79 02 E8

25 E8 0B C5 F8 3B EF 96 5A 30 AF 70 CF

RTCM_Fragmenter: Sending fragment 2 of 3

0A 01 03 01 93 05 02 C9 B7 08 AA 10 CE 17 8E C0

5E 3A C1 79 F4 40 00 01 F8 35 5F E0 E3 01 68 D0

05 A0 E6 0C F2 30 33 B3 81 40 78 05 03 5A 08 AB

C8 22 B6 77 76 17 57 77 57 57 40 00 42

RTCM_Fragmenter: Sending fragment 3 of 3

0A 02 03 D4 2B C6 EC B0 3E D4 D1 48 F8 EF 22 E0

187 bytes RTCM1124

Sending fragmented RTCM message

RTCM_Fragmenter: Sending 187 bytes in fragments

RTCM_Fragmenter: Total fragments = 4

RTCM_Fragmenter: Sending fragment 1 of 4

0A 00 04 D3 00 B5 46 40 00 58 E8 6F E0 00 20 00

96 04 08 48 30 00 00 20 82 00 01 45 57 4E C4 EE

C2 A9 C1 25 AA 24 27 AB 25 A6 C4 DB 44 AC 4A 76

9C 5D 0A 3B F2 49 39 9D 50 5B 80 94 02

RTCM_Fragmenter: Sending fragment 2 of 4

0A 01 04 38 84 4B C2 61 7F 86 FC 9F 9A DF 1D 7D

10 39 C3 F3 93 0A 46 64 40 C4 DE 6E CC F3 B9 70

F4 EF E9 61 D2 58 19 D1 94 00 00 10 00 00 01 1C

84 04 76 5F 84 C4 DE 13 21 78 4B 59 F9

RTCM_Fragmenter: Sending fragment 3 of 4

0A 02 04 B3 37 E6 AE 7F 44 26 FD 11 B7 F4 46 68

14 75 61 90 F4 06 44 BD E6 F2 A7 9B CA FE 6F 60

FA 75 3D E9 DB 67 A7 62 96 01 75 75 77 57 57 57

77 57 75 60 00 00 3C C3 71 B8 FB 92 3C

RTCM_Fragmenter: Sending fragment 4 of 4

0A 03 04 F5 0E D4 FC 32 48 E4 F1 37 08 C8 BD 23

120 bytes RTCM1074

Sending fragmented RTCM message

RTCM_Fragmenter: Sending 120 bytes in fragments

RTCM_Fragmenter: Total fragments = 3

RTCM_Fragmenter: Sending fragment 1 of 3

0A 00 03 D3 00 72 43 20 00 58 E9 5A 42 00 20 60

A2 02 80 80 00 00 00 20 20 00 00 57 F5 A4 22 A3

A4 A6 27 A8 25 E5 A6 04 57 07 D0 59 24 44 16 82

EB C2 29 86 33 1B A6 1E 3C 4B 3A A2 F5

RTCM_Fragmenter: Sending fragment 2 of 3

0A 01 03 C5 86 48 3E 28 69 44 D8 3C 00 00 1E 11

27 F8 63 73 E1 8E 6F 87 9E 3E 1E A4 7A A1 3F EA

8A E0 19 0E C1 F0 F7 86 93 D2 1A 53 80 65 D5 DD

DD DE 58 00 39 3C 6C C8 D4 6C C1 25 0B

RTCM_Fragmenter: Sending fragment 3 of 3

0A 02 03 00 12 8D 50

74 bytes RTCM1084

Sending fragmented RTCM message

RTCM_Fragmenter: Sending 74 bytes in fragments

RTCM_Fragmenter: Total fragments = 2

RTCM_Fragmenter: Sending fragment 1 of 2

0A 00 02 D3 00 44 43 C0 00 89 15 AF 02 00 20 01

02 05 00 00 00 00 00 20 80 00 00 7D 22 24 A5 A1

A9 12 BE 57 BA 7D 2D F7 58 7A 1C F8 3E 74 4E 90

5F D2 BF C0 00 00 1E 8A 28 7A 29 DE 74

RTCM_Fragmenter: Sending fragment 2 of 2

0A 01 02 C8 FD 20 39 61 77 76 04 8C C8 E4 51 00

39 00 2B

129 bytes RTCM1094

Sending fragmented RTCM message

RTCM_Fragmenter: Sending 129 bytes in fragments

RTCM_Fragmenter: Total fragments = 3

RTCM_Fragmenter: Sending fragment 1 of 3

0A 00 03 D3 00 7B 44 60 00 58 E9 5A 42 00 20 0E

40 04 00 28 00 00 00 20 01 00 00 7F FE B6 A6 AE

AA B8 9A AB 02 45 44 2E 2E 0C DF 10 66 DE 3D B2

B8 1D 30 35 1C 9E 38 58 0A 80 10 17 78

RTCM_Fragmenter: Sending fragment 2 of 3

0A 01 03 7E E6 04 F1 09 93 6D 06 D9 8D ED E2 67

B7 8B BE 07 42 F8 1D 44 1C 97 70 72 6B 40 2A 13

80 A5 FB F7 8A EF DE 17 A1 3B F8 84 F1 51 ED 09

37 B4 2B 57 76 F7 57 77 57 77 40 00 42

RTCM_Fragmenter: Sending fragment 3 of 3

0A 02 03 DC 2B C6 EC B0 3E CC D1 48 F8 A9 FB 32

187 bytes RTCM1124

Sending fragmented RTCM message

RTCM_Fragmenter: Sending 187 bytes in fragments

RTCM_Fragmenter: Total fragments = 4

RTCM_Fragmenter: Sending fragment 1 of 4

0A 00 04 D3 00 B5 46 40 00 58 E8 7F 80 00 20 00

96 04 08 48 30 00 00 20 82 00 01 45 57 4E C4 EE

C2 A9 C1 25 AA 24 27 AB 25 A6 C4 FB 54 AE 49 F6

DC 55 06 3B F2 49 41 4B E1 3A 02 55 3B

RTCM_Fragmenter: Sending fragment 2 of 4

0A 01 04 31 76 3B C4 DB 84 77 06 7F 4B FE 7F 82

9A C4 D9 09 BF 18 3D C5 6F 87 47 58 0E C6 FD 16

CA 2B 13 D7 27 3E 14 BB 34 00 00 10 00 00 7D 99

03 F6 69 0F 89 B3 3E 26 D1 F8 9A 1D F4

RTCM_Fragmenter: Sending fragment 3 of 4

0A 02 04 C5 7F D2 F9 40 A6 DB 02 9C 64 0A 71 A8

30 5B 9F 15 B4 7C 57 CD F5 8B 87 D6 2F FF 58 EA

05 12 AC 14 50 68 51 3A 56 01 75 75 77 57 57 57

77 57 75 60 00 00 3C C3 71 B9 03 92 3C

RTCM_Fragmenter: Sending fragment 4 of 4

0A 03 04 F5 0E D4 FC 52 48 E4 F1 35 10 6D 85 71

120 bytes RTCM1074

Sending fragmented RTCM message

RTCM_Fragmenter: Sending 120 bytes in fragments

RTCM_Fragmenter: Total fragments = 3

RTCM_Fragmenter: Sending fragment 1 of 3

0A 00 03 D3 00 72 43 20 00 58 E9 69 E2 00 20 60

A2 02 80 80 00 00 00 20 20 00 00 57 F5 A4 22 A3

A4 A6 27 A8 25 E5 65 FC 59 08 50 39 1C 44 16 11

B0 11 4C 30 6C 6F 7F EA 1F E3 04 ED 8A

RTCM_Fragmenter: Sending fragment 2 of 3

0A 01 03 59 8A A6 19 54 52 40 AA 3C 00 00 00 8A

46 83 07 36 0C 1D 47 FA 97 FF EA 7F 04 EB D6 13

B5 E8 2A 8A E0 CA 47 05 23 82 14 92 B0 65 D5 DD

DD DE 58 00 37 3C 6C C8 D4 6B C1 25 0B

RTCM_Fragmenter: Sending fragment 3 of 3

0A 02 03 00 D2 47 DF

74 bytes RTCM1084

Sending fragmented RTCM message

RTCM_Fragmenter: Sending 74 bytes in fragments

RTCM_Fragmenter: Total fragments = 2

RTCM_Fragmenter: Sending fragment 1 of 2

0A 00 02 D3 00 44 43 C0 00 89 15 BE A2 00 20 01

02 05 00 00 00 00 00 20 80 00 00 7D 22 24 A5 A1

A8 D2 BE 5B B9 06 6D 09 D8 15 60 2E E8 6F 90 D7

40 66 B6 40 00 00 05 5C D8 15 75 C0 70

RTCM_Fragmenter: Sending fragment 2 of 2

0A 01 02 32 81 AE 39 61 77 76 04 8C 48 E4 71 00

45 5C C2

129 bytes RTCM1094

Sending fragmented RTCM message

RTCM_Fragmenter: Sending 129 bytes in fragments

RTCM_Fragmenter: Total fragments = 3

RTCM_Fragmenter: Sending fragment 1 of 3

0A 00 03 D3 00 7B 44 60 00 58 E9 69 E2 00 20 0E

40 04 00 28 00 00 00 20 01 00 00 7F FE B6 A6 AE

AA B8 9A AB 02 C5 04 36 2E 0C 5F 10 68 43 A0 7D

BA 52 F4 A1 81 06 01 27 BA EB 70 D6 22

RTCM_Fragmenter: Sending fragment 2 of 3

0A 01 03 3C 39 84 E0 09 71 11 64 22 4C 04 39 E0

10 E8 1E 94 B6 FA 53 1C 00 FE 90 04 05 3E EB A9

7B AC 4D E2 27 57 88 89 C1 37 B4 04 E0 42 11 68

A8 45 A9 37 76 F7 57 77 57 77 60 00 42

RTCM_Fragmenter: Sending fragment 3 of 3

0A 02 03 DC 2B C6 EC B0 3E CC D1 48 F8 EC D2 57

187 bytes RTCM1124

Sending fragmented RTCM message

RTCM_Fragmenter: Sending 187 bytes in fragments

RTCM_Fragmenter: Total fragments = 4

RTCM_Fragmenter: Sending fragment 1 of 4

0A 00 04 D3 00 B5 46 40 00 58 E8 8F 20 00 20 00

96 04 08 48 30 00 00 20 82 00 01 45 57 4E C4 EE

C2 A9 C1 25 AA 24 27 AB 25 A6 C5 1B 64 B0 49 77

1C 55 02 3B 72 49 50 FA 82 1C 64 0D 74

RTCM_Fragmenter: Sending fragment 2 of 4

0A 01 04 29 E8 2D C7 5F 89 7B 10 86 FD 4D E2 38

26 EF F1 DF EF 26 3A 26 B0 49 D0 41 A0 9A C0 BE

BF 69 7E 50 FC 2E 0F A4 D4 00 00 10 00 00 7A 15

97 E8 5B 2F 8E B5 1E 3A E0 78 EA 4F EF

RTCM_Fragmenter: Sending fragment 3 of 4

0A 02 04 DB A7 BF 4F 3E 09 DE 78 28 77 E0 A1 C8

4C 54 40 9A CC 02 6C 30 04 2A A8 10 A8 A0 42 DD

7F B1 01 FE CA C7 FB 1F D6 01 75 75 77 77 57 57

77 57 75 60 00 00 3C C3 71 B9 03 92 3C

RTCM_Fragmenter: Sending fragment 4 of 4

0A 03 04 F5 0E D2 FC 52 48 E4 F1 37 08 D5 6C 1E

120 bytes RTCM1074

Sending fragmented RTCM message

RTCM_Fragmenter: Sending 120 bytes in fragments

RTCM_Fragmenter: Total fragments = 3

RTCM_Fragmenter: Sending fragment 1 of 3

0A 00 03 D3 00 72 43 20 00 58 E9 79 82 00 20 60

A2 02 80 80 00 00 00 20 20 00 00 57 F5 A4 22 A3

A4 A6 27 A8 25 E5 45 FC 5D 08 D0 39 14 44 15 E0

CC E0 79 DA BF C3 79 B6 33 7B 7F 3A 3E

RTCM_Fragmenter: Sending fragment 2 of 3

0A 01 03 F2 8F 0B F4 90 3B 54 7C 64 00 00 1F 03

B5 FD AC 5D F6 B1 10 6D A4 01 B6 BA 7F 38 3D FC

E8 B8 3C 1E 5F A4 15 83 B4 B4 0E D8 38 65 D5 DD

DD DE 58 00 37 3C 6D 48 D4 6C C1 25 0B

RTCM_Fragmenter: Sending fragment 3 of 3

0A 02 03 00 CC B4 65

74 bytes RTCM1084

Sending fragmented RTCM message

RTCM_Fragmenter: Sending 74 bytes in fragments

RTCM_Fragmenter: Total fragments = 2

RTCM_Fragmenter: Sending fragment 1 of 2

0A 00 02 D3 00 44 43 C0 00 89 15 CE 42 00 20 01

02 05 00 00 00 00 00 20 80 00 00 7D 22 24 A5 A1

A8 92 BE 61 B8 0F B4 1C 6B B0 D3 65 DE 6B 03 1E

C0 FB 21 40 00 01 EC 39 A7 B0 E4 DE 6B

RTCM_Fragmenter: Sending fragment 2 of 2

0A 01 02 C7 06 3D 67 81 97 96 04 8C 48 E4 71 00

D1 27 7B

129 bytes RTCM1094

Sending fragmented RTCM message

RTCM_Fragmenter: Sending 129 bytes in fragments

RTCM_Fragmenter: Total fragments = 3

RTCM_Fragmenter: Sending fragment 1 of 3

0A 00 03 D3 00 7B 44 60 00 58 E9 79 82 00 20 0E

40 04 00 28 00 00 00 20 01 00 00 7F FE B6 A6 AE

AA B8 9A AB 03 44 C4 3E 2C 0B 5F 10 79 A9 63 49

1C 89 39 11 65 73 CA 00 6B 64 D1 C8 CC

RTCM_Fragmenter: Sending fragment 2 of 3

0A 01 03 11 8D 64 D0 09 51 75 C4 EB 10 1A 95 40

6A 55 BF 22 56 7C 89 79 E5 6B 27 95 B7 41 AD 98

06 B4 06 0C C7 68 33 0C 61 33 A8 04 D0 09 F5 C9

EF D7 2E 17 77 17 57 77 57 77 60 00 42

RTCM_Fragmenter: Sending fragment 3 of 3

0A 02 03 DC 2B 46 EC B0 3E D4 D1 48 F8 AF FE 74

129 bytes RTCM1094

Sending fragmented RTCM message

RTCM_Fragmenter: Sending 129 bytes in fragments

RTCM_Fragmenter: Total fragments = 3

RTCM_Fragmenter: Sending fragment 1 of 3

0A 00 03 D3 00 7B 44 60 00 58 E9 89 22 00 20 0E

40 04 00 28 00 00 00 20 01 00 00 7F FE B6 A6 AE

AA B8 9A AB 04 44 84 3E 2C 0A DF 10 87 0F 5E 15

1E BF FD 81 89 E6 12 E4 1B F8 32 F7 76

RTCM_Fragmenter: Sending fragment 2 of 3

0A 01 03 3E E1 C4 C1 09 32 9A 26 33 DB F0 F4 C7

C3 D4 BF B0 1A FE C0 B4 09 DC F8 27 80 20 6F E2

01 BD 21 F7 6B 9F DD 9E 61 2F D6 04 C0 C6 1A 2D

18 68 BB 37 77 17 77 77 57 77 60 00 42

RTCM_Fragmenter: Sending fragment 3 of 3

0A 02 03 DC 2B 46 EC B0 3E D4 D1 48 F8 F3 83 41

187 bytes RTCM1124

Sending fragmented RTCM message

RTCM_Fragmenter: Sending 187 bytes in fragments

RTCM_Fragmenter: Total fragments = 4

RTCM_Fragmenter: Sending fragment 1 of 4

0A 00 04 D3 00 B5 46 40 00 58 E8 AE 60 00 20 00

96 04 08 48 30 00 00 20 82 00 01 45 57 4E C4 EE

C2 A9 C1 25 AA 24 27 AB 25 A6 C5 5B 84 B2 48 77

9C 44 FC 3A F2 69 68 57 B3 E4 67 9A C6

RTCM_Fragmenter: Sending fragment 2 of 4

0A 01 04 1B 8C 10 CC 8D 93 C3 25 2E 60 9C A8 A3

42 06 29 0C 5E C2 49 E9 83 CF 86 16 2C 45 38 13

09 E9 93 4E 26 22 05 78 2C 00 00 01 E6 5B 83 0E

CC 0C 3F B7 99 01 BE 64 08 79 8F 11 E6

RTCM_Fragmenter: Sending fragment 3 of 4

0A 02 04 10 77 98 25 00 D0 CA 83 44 3A 0D 10 87

84 6F 9F A6 1D 7E 99 7D E1 7B BF 85 F0 DE 17 ED

84 F0 42 13 C7 38 4F 14 56 0F 75 77 77 77 77 57

77 57 75 60 00 00 3C C3 71 B9 03 92 3C

RTCM_Fragmenter: Sending fragment 4 of 4

0A 03 04 F5 0E D4 FC 51 C8 E4 F1 B5 08 01 E3 28

120 bytes RTCM1074

Sending fragmented RTCM message

RTCM_Fragmenter: Sending 120 bytes in fragments

RTCM_Fragmenter: Total fragments = 3

RTCM_Fragmenter: Sending fragment 1 of 3

0A 00 03 D3 00 72 43 20 00 58 E9 98 C2 00 20 60

A2 02 80 80 00 00 00 20 20 00 00 57 F5 A4 22 A3

A4 A6 27 A8 25 E4 C5 F4 63 0A 50 19 04 42 14 FF

27 FE F0 2F 98 6C C9 4F 42 AE 83 D8 88

RTCM_Fragmenter: Sending fragment 2 of 3

0A 01 03 2F 17 E7 2B 32 0D C8 1F 9C 00 00 1F F7

79 82 FA 50 0B E9 00 53 F2 C1 4F F2 03 D6 6C 0F

61 08 5F 8C E1 59 11 80 DB A1 00 00 00 66 56 5E

5E 66 00 00 37 3C 6C C8 CC 6C C1 25 2B

RTCM_Fragmenter: Sending fragment 3 of 3

0A 02 03 00 B9 A6 40

74 bytes RTCM1084

Sending fragmented RTCM message

RTCM_Fragmenter: Sending 74 bytes in fragments

RTCM_Fragmenter: Total fragments = 2

RTCM_Fragmenter: Sending fragment 1 of 2

0A 00 02 D3 00 44 43 C0 00 89 15 ED 82 00 20 01

02 05 00 00 00 00 00 20 80 00 00 7D 22 24 A5 A1

A8 32 B6 6B B6 E2 59 C1 BB E8 27 D4 96 62 6F AF

DE 25 61 40 00 01 FA 0F 5F E8 3F 1E 63

RTCM_Fragmenter: Sending fragment 2 of 2

0A 01 02 55 7F 5F 79 81 97 98 04 8C 48 E4 71 00

8E FC 3B

129 bytes RTCM1094

Sending fragmented RTCM message

RTCM_Fragmenter: Sending 129 bytes in fragments

RTCM_Fragmenter: Total fragments = 3

RTCM_Fragmenter: Sending fragment 1 of 3

0A 00 03 D3 00 7B 44 60 00 58 E9 98 C2 00 20 0E

40 04 00 28 00 00 00 20 01 00 00 7F FE B6 A6 AE

AA B8 9A AB 04 C4 44 46 2C 0A 5F 10 90 75 80 E1

60 F7 81 F6 6E 5E DB D1 CC A3 94 3E 20

RTCM_Fragmenter: Sending fragment 2 of 3

0A 01 03 9C 36 C4 B2 C9 15 FE 89 FC A4 07 58 08

1D 61 C0 3E 09 80 F8 05 EE 53 47 B9 5B BF 32 7A

FC C7 9F E2 13 57 88 3D 61 2C 3C 04 B2 49 FE 91

E7 FA 4F 97 77 17 77 77 57 77 60 00 42

RTCM_Fragmenter: Sending fragment 3 of 3

0A 02 03 DC 2B 46 EC B0 3E D4 D1 48 F8 78 64 DB

187 bytes RTCM1124

Sending fragmented RTCM message

RTCM_Fragmenter: Sending 187 bytes in fragments

RTCM_Fragmenter: Total fragments = 4

RTCM_Fragmenter: Sending fragment 1 of 4

0A 00 04 D3 00 B5 46 40 00 58 E8 BE 00 00 20 00

96 04 08 48 30 00 00 20 82 00 01 45 57 4E C4 EE

C2 A9 C1 25 AA 24 27 AB 25 A6 C5 7B 9C B4 47 F7

DC 44 F8 3A 72 69 78 06 4C C2 39 5C 7F

RTCM_Fragmenter: Sending fragment 2 of 4

0A 01 04 14 FE 00 CF 33 99 0B 2F BE 12 8C 0C 38

D1 F1 48 E2 9D D0 5C 4B 10 92 9F 01 0E 1B 7B BF

BF 2C 7D D1 FB 26 00 62 34 00 00 1E 57 6B FF 8B

5D FE 32 4F 9E 48 DE 79 2C 79 E3 8F E1

RTCM_Fragmenter: Sending fragment 3 of 4

0A 02 04 2F 37 84 9E 7E 34 B2 F8 D3 C1 E3 4F 0F

A0 91 41 2C 4D 04 B2 41 F0 2D AF C0 B4 3F 03 0C

7F 91 0B FE 4A B7 F9 21 D6 0F 75 77 77 77 77 57

77 57 75 60 00 00 3C C3 91 B9 03 92 BC

RTCM_Fragmenter: Sending fragment 4 of 4

0A 03 04 F5 0E D4 FC 51 C8 E4 F1 B5 08 DB F6 76

114 bytes RTCM1074

Sending fragmented RTCM message

RTCM_Fragmenter: Sending 114 bytes in fragments

RTCM_Fragmenter: Total fragments = 2

RTCM_Fragmenter: Sending fragment 1 of 2

0A 00 02 D3 00 6C 43 20 00 58 E9 A8 62 00 20 60

A2 02 80 80 00 00 00 20 20 00 00 57 F5 24 22 A3

A4 A6 27 A8 25 E4 85 F4 67 0B 50 18 FC 42 14 0E

38 CE 3B DA 27 C1 F7 1C 3E 48 FE 2A 7C

RTCM_Fragmenter: Sending fragment 2 of 2

0A 01 02 D2 1C 5E 06 9B F7 2A 00 00 0F 38 E6 7E

D1 94 FB 46 0B E3 9A 9F 8E 7F FF 14 10 FC 53 80

38 B3 50 1A 22 BF B8 AE 0C CA CB CB CC C0 00 DC

F1 B3 23 31 B5 04 94 80 56 01 84

74 bytes RTCM1084

Sending fragmented RTCM message

RTCM_Fragmenter: Sending 74 bytes in fragments

RTCM_Fragmenter: Total fragments = 2

RTCM_Fragmenter: Sending fragment 1 of 2

0A 00 02 D3 00 44 43 C0 00 89 15 FD 22 00 20 01

02 05 00 00 00 00 00 20 80 00 00 7D 22 24 A5 A1

A7 F2 B6 6F B5 EB B8 D4 79 84 0B 0C 50 5E 51 F9

5E BB 31 40 00 01 E1 08 B7 84 24 00 5F

RTCM_Fragmenter: Sending fragment 2 of 2

0A 01 02 54 83 F2 5F 81 97 98 04 8C 48 E4 71 00

10 67 15

129 bytes RTCM1094

Sending fragmented RTCM message

RTCM_Fragmenter: Sending 129 bytes in fragments

RTCM_Fragmenter: Total fragments = 3

RTCM_Fragmenter: Sending fragment 1 of 3

0A 00 03 D3 00 7B 44 60 00 58 E9 A8 62 00 20 0E

40 04 00 28 00 00 00 20 01 00 00 7F FE B6 A6 AE

AA B8 9A AB 05 44 04 46 2A 09 5F 10 A1 DB F3 AE

23 2F 86 6E 12 DC 24 C8 7D 60 F5 B8 CB

RTCM_Fragmenter: Sending fragment 2 of 3

0A 01 03 31 8C 44 A5 88 FA E2 EF C5 72 1D BF 00

76 F9 E0 CC 14 83 30 A2 12 CF 38 4B 49 41 F5 6E

07 D3 4A 0C BF 10 32 EA 21 28 D6 84 A4 DB E2 F8

7F 8B E8 97 77 17 77 77 57 77 60 00 42

RTCM_Fragmenter: Sending fragment 3 of 3

0A 02 03 DC 2B C8 EC B0 3E D4 D1 48 F8 93 6B ED

187 bytes RTCM1124

Sending fragmented RTCM message

RTCM_Fragmenter: Sending 187 bytes in fragments

RTCM_Fragmenter: Total fragments = 4

RTCM_Fragmenter: Sending fragment 1 of 4

0A 00 04 D3 00 B5 46 40 00 58 E8 CD A0 00 20 00

96 04 08 48 30 00 00 20 82 00 01 45 57 4E C4 EE

C2 A9 C1 25 AA 24 27 AB 25 A6 C5 9B AC B6 47 77

FC 3C F4 3A 72 69 8F B4 ED A4 FB 24 B8

RTCM_Fragmenter: Sending fragment 2 of 4

0A 01 04 0D EF F1 D1 E5 9E 67 3A 81 C4 B3 70 5E

62 BC 6A 78 E0 DE 75 AC B3 55 E7 EC 4F F2 7F 6D

F4 70 68 57 D0 31 FB 4C 6C 00 00 1E C8 91 7C 08

0F F0 24 FF A3 A9 3E 8E AE FA 39 9C 1C

RTCM_Fragmenter: Sending fragment 3 of 4

0A 02 04 51 78 71 26 9F 98 E5 FE 64 9D F9 92 47

BC C4 BE B2 D9 7A CC 59 FE E5 8F FB 95 7F EE 8C

FA 32 D7 E8 D1 47 A3 3C 36 11 75 77 77 77 77 57

77 57 75 60 00 00 3A C3 71 B8 FB 92 3C

RTCM_Fragmenter: Sending fragment 4 of 4

0A 03 04 F5 0E D2 FC 51 C8 E4 F1 35 08 5B 3F 25

120 bytes RTCM1074

Sending fragmented RTCM message

RTCM_Fragmenter: Sending 120 bytes in fragments

RTCM_Fragmenter: Total fragments = 3

RTCM_Fragmenter: Sending fragment 1 of 3

0A 00 03 D3 00 72 43 20 00 58 E9 B8 02 00 20 60

A2 02 80 80 00 00 00 20 20 00 00 57 F5 A4 22 A3

A4 A6 27 A8 25 E4 45 EC 6B 0B D0 18 FC 42 13 9D

3F 1D 8F 84 CB 17 40 E9 71 E3 78 7E 31

RTCM_Fragmenter: Sending fragment 2 of 3

0A 01 03 78 E0 DA E2 11 E0 A3 C6 50 75 07 00 EC

6D F8 4D 39 E1 34 30 3A 8A 40 EA 55 F8 7B 9B E1

F4 EF 83 56 FF 0F F1 7E 08 9D 00 00 03 E6 56 5E

5E 66 00 00 37 3C 8D 48 CC 6C C1 25 2B

RTCM_Fragmenter: Sending fragment 3 of 3

0A 02 03 00 43 FE CD

74 bytes RTCM1084

Sending fragmented RTCM message

RTCM_Fragmenter: Sending 74 bytes in fragments

RTCM_Fragmenter: Total fragments = 2

RTCM_Fragmenter: Sending fragment 1 of 2

0A 00 02 D3 00 44 43 C0 00 89 16 0C C2 00 20 01

02 05 00 00 00 00 00 20 80 00 00 7D 22 24 A5 A1

A7 B2 AE 75 B5 75 1D E7 44 20 10 44 5E 5A 7C 43

5F 51 74 40 00 00 08 0B 50 20 2E 5E 5B

RTCM_Fragmenter: Sending fragment 2 of 2

0A 01 02 7C 78 86 8F 81 99 98 04 8C 48 E4 71 00

CA 6D F7

136 bytes RTCM1094

Sending fragmented RTCM message

RTCM_Fragmenter: Sending 136 bytes in fragments

RTCM_Fragmenter: Total fragments = 3

RTCM_Fragmenter: Sending fragment 1 of 3

0A 00 03 D3 00 82 44 60 00 58 E9 B8 02 00 20 0E

40 04 00 28 00 00 00 20 01 01 00 6D BE D9 6D 4D

5D 55 71 35 56 0C 87 88 9C 54 11 BE 21 5E 85 5C

F7 0A D0 15 C4 EE BD DB 94 5C 68 AE C1

RTCM_Fragmenter: Sending fragment 2 of 3

0A 01 03 7B DD D8 7B 89 12 64 23 86 1D 5C 39 17

D0 A8 7F 42 9E 85 69 30 15 A5 E7 DD 40 DF 75 37

02 E2 EC 0B 82 6C 00 00 1F 76 EC FD DA 7A 12 5A

E8 49 81 80 76 0E 01 D8 99 77 73 77 76

RTCM_Fragmenter: Sending fragment 3 of 3

0A 02 03 17 57 77 60 00 21 6E 15 E3 76 58 16 7D

A9 A2 91 F0 3C D1 10

187 bytes RTCM1124

Sending fragmented RTCM message

RTCM_Fragmenter: Sending 187 bytes in fragments

RTCM_Fragmenter: Total fragments = 4

RTCM_Fragmenter: Sending fragment 1 of 4

0A 00 04 D3 00 B5 46 40 00 58 E8 DD 40 00 20 00

96 04 08 48 30 00 00 20 82 00 01 45 57 4E C4 EE

C2 A9 C1 25 AA 24 27 AB 25 A6 C5 BB BC B8 46 F8

3C 34 F0 39 F2 69 97 63 7E 8B 3C E6 31

RTCM_Fragmenter: Sending fragment 2 of 4

0A 01 04 07 61 E4 D4 A1 A3 DF 45 71 77 02 D4 C3

F4 47 8E 0F 29 EC 96 0E 6C 19 50 D7 E1 CA 43 1D

89 B5 92 E1 25 41 F6 35 FC 00 00 1F 39 D8 78 84

DD E2 17 FF A9 20 9E A4 88 7A 91 0C 17

RTCM_Fragmenter: Sending fragment 3 of 4

0A 02 04 76 20 5D BB C0 FD 63 83 F6 A2 0F DA 3F

D9 05 40 39 C1 00 E7 F2 0D A3 C0 36 90 40 DA 6E

04 D5 5E 13 5B 60 4D 64 B6 11 75 77 77 77 77 57

77 57 75 60 00 00 3A BB 91 B9 03 92 3C

RTCM_Fragmenter: Sending fragment 4 of 4

0A 03 04 F5 0E D2 F4 51 C6 DC F1 35 08 27 54 AE

120 bytes RTCM1074

Sending fragmented RTCM message

RTCM_Fragmenter: Sending 120 bytes in fragments

RTCM_Fragmenter: Total fragments = 3

RTCM_Fragmenter: Sending fragment 1 of 3

0A 00 03 D3 00 72 43 20 00 58 E9 C7 A2 00 20 60

A2 02 80 80 00 00 00 20 20 00 00 57 F5 A4 22 A3

A4 A6 27 A8 25 E4 25 EC 6D 0C CF F8 F4 40 13 6C

32 EC EC 2F 78 6C 7E B6 FD 7E 82 D3 46

RTCM_Fragmenter: Sending fragment 2 of 3

0A 01 03 22 E5 5D 3D 95 CA 2F 9D 67 B1 2B BF 67

56 82 F8 7E 0B E2 47 AD EF 7E B7 EA 82 D0 CA 0B

4A FF 95 60 01 EC 0F FC A1 31 00 00 03 E6 56 5E

5E 66 00 00 37 3C 6B 48 D4 6D 41 25 2B

RTCM_Fragmenter: Sending fragment 3 of 3

0A 02 03 80 B7 C9 84

74 bytes RTCM1084

Sending fragmented RTCM message

RTCM_Fragmenter: Sending 74 bytes in fragments

RTCM_Fragmenter: Total fragments = 2

RTCM_Fragmenter: Sending fragment 1 of 2

0A 00 02 D3 00 44 43 C0 00 89 16 1C 62 00 20 01

02 05 00 00 00 00 00 20 80 00 00 7D 22 24 A5 A1

A7 72 AE 79 B4 7E 89 FA 1F BC 3B 7C B0 56 BE 8D

DF E8 29 C0 00 01 EF 16 BF BC 5D A0 57

RTCM_Fragmenter: Sending fragment 2 of 2

0A 01 02 BF FD 1B AD 81 99 98 04 8C C8 E4 71 00

9F 02 2D

136 bytes RTCM1094

Sending fragmented RTCM message

RTCM_Fragmenter: Sending 136 bytes in fragments

RTCM_Fragmenter: Total fragments = 3

RTCM_Fragmenter: Sending fragment 1 of 3

0A 00 03 D3 00 82 44 60 00 58 E9 C7 A2 00 20 0E

40 04 00 28 00 00 00 20 01 01 00 6D BE D9 6D 4D

5D 55 71 35 56 0D 87 08 9C 54 10 BE 21 71 53 02

92 4F 42 9E A7 37 CA 6D AF BE 37 72 5E

RTCM_Fragmenter: Sending fragment 2 of 3

0A 01 03 F1 78 84 B0 E2 12 35 23 29 AF 07 5C 68

2A 60 20 A9 82 07 A2 8A 1E 8A 58 6F 58 21 BD 91

FD F1 53 F7 BC 1C 00 00 1E 22 1D 78 87 6C 12 2B

58 48 C5 BE BC AF FA F3 31 97 73 77 76

RTCM_Fragmenter: Sending fragment 3 of 3

0A 02 03 17 57 77 60 00 21 6E 15 E4 76 58 17 7D

A9 A2 91 F0 51 6B 5A

187 bytes RTCM1124

Sending fragmented RTCM message

RTCM_Fragmenter: Sending 187 bytes in fragments

RTCM_Fragmenter: Total fragments = 4

RTCM_Fragmenter: Sending fragment 1 of 4

0A 00 04 D3 00 B5 46 40 00 58 E8 EC E0 00 20 00

96 04 08 48 30 00 00 20 82 00 01 45 57 4E C4 EE

C2 A9 C1 25 AA 24 27 AB 25 A6 C5 DB CC B8 46 78

7C 34 EC 39 72 69 A7 12 0F 6F 7E B1 4A

RTCM_Fragmenter: Sending fragment 2 of 4

0A 01 04 00 13 D6 D7 69 A9 67 50 89 29 82 39 99

87 B2 B4 E5 75 FA C0 70 3C DC E9 C3 F3 A2 C6 CE

FE FC FD 6F FA 59 F1 20 3C 00 00 10 00 00 05 01

8C 14 0B 67 AE AC 1E BA B2 7A E9 BE 12

RTCM_Fragmenter: Sending fragment 3 of 4

0A 02 04 9E 10 4A 59 7E 62 2A F9 89 AB E6 26 B7

F5 55 01 C0 FD 87 04 E6 1C 67 F0 71 9E E1 C6 B0

7F 78 AB FD E8 E7 F7 9B 16 01 75 77 77 77 77 57

77 57 75 60 00 00 3C BB 91 B8 FB 92 BC

RTCM_Fragmenter: Sending fragment 4 of 4

0A 03 04 F5 0E D2 F4 51 C6 DC F1 37 08 E0 29 B2

27 bytes RTCM1006

Sending full RTCM message

D3 00 15 3E E0 00 03 87 24 78 C1 10 81 58 F1 BC

AE 0C E8 36 5E 9E 00 00 51 00 C1

74 bytes RTCM1033

Sending fragmented RTCM message

RTCM_Fragmenter: Sending 74 bytes in fragments

RTCM_Fragmenter: Total fragments = 2

RTCM_Fragmenter: Sending fragment 1 of 2

0A 00 02 D3 00 44 40 90 00 0E 41 44 56 4E 55 4C

4C 41 4E 54 45 4E 4E 41 FF 05 61 30 30 30 31 0D

55 4E 49 43 4F 52 45 20 55 4D 39 38 30 0B 31 33

35 30 34 2D 32 38 30 35 31 10 66 66 33

RTCM_Fragmenter: Sending fragment 2 of 2

0A 01 02 62 34 38 39 39 33 30 34 35 37 65 63 65

62 94 E3

120 bytes RTCM1074

Sending fragmented RTCM message

RTCM_Fragmenter: Sending 120 bytes in fragments

RTCM_Fragmenter: Total fragments = 3

RTCM_Fragmenter: Sending fragment 1 of 3

0A 00 03 D3 00 72 43 20 00 58 E9 D7 42 00 20 60

A2 02 80 80 00 00 00 20 20 00 00 57 F5 A4 22 A3

A4 A6 27 A8 25 E3 E5 E4 71 0D 4F F8 EC 40 12 FB

16 3C 55 DA 43 C2 18 84 B1 19 FD 2A 7A

RTCM_Fragmenter: Sending fragment 2 of 3

0A 01 03 D1 69 E5 19 29 B3 D7 6E 97 ED 5B 01 E2

8E FD A5 01 F6 93 88 21 65 40 85 C4 7D 27 AF F4

A6 3F A7 81 80 C8 A8 FB 3B 5D 00 00 04 66 56 5E

5E 66 00 00 37 3C 6B 48 CC 6C C1 25 2B

RTCM_Fragmenter: Sending fragment 3 of 3

0A 02 03 00 FA 15 00

74 bytes RTCM1084

Sending fragmented RTCM message

RTCM_Fragmenter: Sending 74 bytes in fragments

RTCM_Fragmenter: Total fragments = 2

RTCM_Fragmenter: Sending fragment 1 of 2

0A 00 02 D3 00 44 43 C0 00 89 16 2C 02 00 20 01

02 05 00 00 00 00 00 20 80 00 00 7D 22 24 A5 A1

A7 32 A6 7F B3 07 FC 0D 04 58 88 B5 56 53 10 D9

00 7F 56 C0 00 00 16 2B C0 58 B0 5E 54

RTCM_Fragmenter: Sending fragment 2 of 2

0A 01 02 27 81 B2 25 81 99 98 04 8C C8 E4 71 00

5A 5E 04

120 bytes RTCM1074

Sending fragmented RTCM message

RTCM_Fragmenter: Sending 120 bytes in fragments

RTCM_Fragmenter: Total fragments = 3

RTCM_Fragmenter: Sending fragment 1 of 3

0A 00 03 D3 00 72 43 20 00 58 E9 E6 E2 00 20 60

A2 02 80 80 00 00 00 20 20 00 00 57 F5 A4 22 A3

A4 A6 27 A8 25 E3 A5 E4 75 0E 4F D8 E4 40 12 0A

0D 0B C5 85 23 17 E6 52 DC B6 27 83 0F

RTCM_Fragmenter: Sending fragment 2 of 3

0A 01 03 82 EE 73 F4 CD 9D 97 40 D8 29 99 60 5E

16 F8 52 DB E1 4B 8F 94 F0 5E 53 E9 07 80 66 1E

08 FF B9 B8 BF A5 BA 79 D7 47 E7 61 74 66 56 66

5E 66 38 00 3B 44 8C CC D4 8D C5 2D 4D

RTCM_Fragmenter: Sending fragment 3 of 3

0A 02 03 80 8D 2B 87

74 bytes RTCM1084

Sending fragmented RTCM message

RTCM_Fragmenter: Sending 74 bytes in fragments

RTCM_Fragmenter: Total fragments = 2

RTCM_Fragmenter: Sending fragment 1 of 2

0A 00 02 D3 00 44 43 C0 00 89 16 3B A2 00 20 01

02 05 00 00 00 00 00 20 80 00 00 7D 22 24 A5 A1

A6 F2 A6 83 B2 11 77 1F FD F4 FF EE 48 4F A3 24

C1 16 FE C0 00 01 FD 4A 57 F5 2A 00 50

RTCM_Fragmenter: Sending fragment 2 of 2

0A 01 02 BF 86 49 DD 81 99 98 04 8D 4A F4 B1 00

7F AE 62

136 bytes RTCM1094

Sending fragmented RTCM message

RTCM_Fragmenter: Sending 136 bytes in fragments

RTCM_Fragmenter: Total fragments = 3

RTCM_Fragmenter: Sending fragment 1 of 3

0A 00 03 D3 00 82 44 60 00 58 E9 E6 E2 00 20 0E

40 04 00 28 00 00 00 20 01 01 00 6D BE D9 6D 4D

5D 55 71 35 56 10 86 48 BC 50 0D BE 21 AE F0 5D

CC B8 2A F0 72 CA 07 92 18 82 58 FA 92

RTCM_Fragmenter: Sending fragment 2 of 3

0A 01 03 04 DD E0 3B 9B 91 E3 22 81 D2 6B A3 47

DE 05 1F 78 08 7C 16 CF F0 5B CF 93 C4 3E 4F 54

04 12 42 10 3F BC 00 00 1F 79 46 7D E3 EC 11 D7

A8 47 75 9F 4A 4C FD 29 B1 97 93 77 76

RTCM_Fragmenter: Sending fragment 3 of 3

0A 02 03 17 57 77 60 00 21 6E 15 A3 76 57 D6 85

A9 A2 91 F0 2E 6C 1A

187 bytes RTCM1124

Sending fragmented RTCM message

RTCM_Fragmenter: Sending 187 bytes in fragments

RTCM_Fragmenter: Total fragments = 4

RTCM_Fragmenter: Sending fragment 1 of 4

0A 00 04 D3 00 B5 46 40 00 58 E9 0C 20 00 20 00

96 04 08 48 30 00 00 20 82 00 01 45 57 4E C4 EE

C2 A9 C1 25 AA 24 27 AB 25 A6 C6 1B EC BC 45 78

FC 24 E4 38 F2 89 BE 6F 21 35 C2 47 BB

RTCM_Fragmenter: Sending fragment 2 of 4

0A 01 04 F3 77 BB DD 1D B4 BF 67 50 8F 21 04 84

B1 49 08 12 1C 17 2C 34 20 64 B7 9D 2F 56 3E 35

C9 8F 92 93 24 9D E6 F3 34 00 00 10 00 00 7D FB

65 F7 F1 57 BA 0A 9E E8 30 7B 9F C2 08

RTCM_Fragmenter: Sending fragment 3 of 4

0A 02 04 F6 F0 23 C0 81 2C A1 04 B3 86 12 CD E8

2E 23 00 D0 90 83 43 39 FA 02 87 E8 0C 7F A0 5E

04 C1 CE 13 0D C8 4C 2B B6 01 77 77 77 77 77 57

77 77 77 60 00 00 3A E3 B1 39 03 92 3F

RTCM_Fragmenter: Sending fragment 4 of 4

0A 03 04 05 0E D4 EC 51 C8 E4 F1 B7 20 57 64 15

114 bytes RTCM1074

Sending fragmented RTCM message

RTCM_Fragmenter: Sending 114 bytes in fragments

RTCM_Fragmenter: Total fragments = 2

RTCM_Fragmenter: Sending fragment 1 of 2

0A 00 02 D3 00 6C 43 20 00 58 E9 F6 82 00 20 60

A2 02 80 80 00 00 00 20 20 00 00 55 F5 A4 22 A3

A4 A6 27 A8 25 E3 65 E4 77 0E CF D8 DC 40 11 99

05 DB 40 30 10 10 98 29 80 EE C2 1B F9

RTCM_Fragmenter: Sending fragment 2 of 2

0A 01 02 83 E8 3F C3 B7 89 8C 32 F4 AF 6C F5 81

80 ED 01 11 7C 04 4B D0 3B 5B 40 EE 72 F9 81 13

D0 69 AF 0E 8D FC 3A C9 8C CC CC BC CC 70 00 E5

11 D0 B4 8D 45 25 6D 80 17 CC 44

74 bytes RTCM1084

Sending fragmented RTCM message

RTCM_Fragmenter: Sending 74 bytes in fragments

RTCM_Fragmenter: Total fragments = 2

RTCM_Fragmenter: Sending fragment 1 of 2

0A 00 02 D3 00 44 43 C0 00 89 16 4B 42 00 20 01

02 05 00 00 00 00 00 20 80 00 00 7D 22 24 A5 A1

A6 B2 A6 89 B1 9A F8 33 03 91 9F 27 86 4C 4D 71

21 AF 10 C0 00 01 E4 73 07 91 CC 7E 4D

RTCM_Fragmenter: Sending fragment 2 of 2

0A 01 02 75 FA E2 B7 81 99 98 04 AB CC EC D1 80

BA 33 98

142 bytes RTCM1094

Sending fragmented RTCM message

RTCM_Fragmenter: Sending 142 bytes in fragments

RTCM_Fragmenter: Total fragments = 3

RTCM_Fragmenter: Sending fragment 1 of 3

0A 00 03 D3 00 88 44 60 00 58 E9 F6 82 00 20 0E

40 04 00 28 00 00 00 20 01 01 00 6D BE F9 6D 4D

5D 55 71 35 56 11 85 C8 BC 50 0C BE 21 B1 BF 83

6A FC A1 79 5D 13 34 24 6F E4 AF BF 3F

RTCM_Fragmenter: Sending fragment 2 of 3

0A 01 03 88 38 8F 70 FB 11 BE 22 38 47 4C C8 51

8D 80 6F DA 81 BF 5E FC A4 2F F2 91 A0 4C 34 81

31 33 FE 49 93 F9 14 68 00 00 3C 4A 70 F1 27 AC

23 65 D0 8D C3 E0 00 00 0C 8A 34 32 2C

RTCM_Fragmenter: Sending fragment 3 of 3

0A 02 03 6C BC 9B BB B0 BA BB 0B B0 00 08 5D 91

C9 1E 9A 05 E1 6E 78 D6 92 00 B5 16 8D

142 bytes RTCM1094

Sending fragmented RTCM message

RTCM_Fragmenter: Sending 142 bytes in fragments

RTCM_Fragmenter: Total fragments = 3

RTCM_Fragmenter: Sending fragment 1 of 3

0A 00 03 D3 00 88 44 60 00 58 EA 06 22 00 20 0E

40 04 00 28 00 00 00 20 01 01 00 6D BE F9 6D 4D

5D 55 71 35 56 13 85 48 CC 50 0A BE 21 DC 8F 59

0A 81 18 82 49 DC 6B B6 D7 47 36 84 2D

RTCM_Fragmenter: Sending fragment 2 of 3

0A 01 03 16 E3 3F C6 5C 11 9E 21 F6 46 3F EB E7

D4 9F 23 CB 7C 8F 1A 01 1B C4 04 6F 4F 71 0A 3D

C4 98 F4 71 7F D1 B4 18 00 00 01 A2 D0 06 88 B0

23 23 F0 8C BF 20 00 00 FE C2 DF FB 10

RTCM_Fragmenter: Sending fragment 3 of 3

0A 02 03 5C BC 9B BB B0 BA BB 0B B0 00 08 5D 91

C9 1E 9A 05 E2 6E 78 D9 92 00 B8 02 99

187 bytes RTCM1124

Sending fragmented RTCM message

RTCM_Fragmenter: Sending 187 bytes in fragments

RTCM_Fragmenter: Total fragments = 4

RTCM_Fragmenter: Sending fragment 1 of 4

0A 00 04 D3 00 B5 46 40 00 58 E9 2B 60 00 20 00

96 04 08 48 30 00 00 20 82 00 01 45 57 4E C4 EE

C2 A9 C1 25 AA 24 27 AB 25 A6 C6 3C 0C BE 44 79

7C 1C DC 38 72 89 D9 CC 52 FC 05 C9 8D

RTCM_Fragmenter: Sending fragment 2 of 4

0A 01 04 E6 9B 9F E2 FF C0 7B 7E CF F5 6F D1 1F

E0 3F 65 7E D7 34 09 F8 63 ED 29 78 13 0C A5 A3

34 28 E7 C6 CE FE 1C C6 6C 00 00 10 00 00 06 F5

4A 1B D9 8F C5 C7 3F 17 1E FC 5B 59 FF

RTCM_Fragmenter: Sending fragment 3 of 4

0A 02 04 5C DF FD 55 BF F8 45 7F E2 23 FF 88 64

00 00 1F E1 96 7F 87 50 17 B6 88 5E E0 01 7B 9F

FA 0E 61 E8 3F C7 A0 F6 76 01 77 77 77 77 76 17

77 77 77 60 00 00 3B 04 30 3D 0B B3 3F

RTCM_Fragmenter: Sending fragment 4 of 4

0A 03 04 14 EF 54 D4 11 C4 DC F2 37 30 11 16 E9

108 bytes RTCM1074

Sending fragmented RTCM message

RTCM_Fragmenter: Sending 108 bytes in fragments

RTCM_Fragmenter: Total fragments = 2

RTCM_Fragmenter: Sending fragment 1 of 2

0A 00 02 D3 00 66 43 20 00 58 EA 15 C2 00 20 60

A2 02 80 80 00 00 00 20 20 00 00 55 75 A4 22 A3

A4 A6 27 A8 25 E3 05 DC 7F 10 4F B8 CC 3E 10 77

6B FA 53 86 2F DF 69 A6 03 6B 3F 10 02

RTCM_Fragmenter: Sending fragment 2 of 2

0A 01 02 04 96 D9 2E 89 F7 AB 27 F4 A0 FE 18 F4

FE FF C2 1A 55 50 69 71 1F C3 C8 00 FF 62 16 CE

38 5B 4A D3 99 99 99 99 00 03 94 47 44 6B C7 25

6D 80 C8 7F 01

74 bytes RTCM1084

Sending fragmented RTCM message

RTCM_Fragmenter: Sending 74 bytes in fragments

RTCM_Fragmenter: Total fragments = 2

RTCM_Fragmenter: Sending fragment 1 of 2

0A 00 02 D3 00 44 43 C0 00 89 16 6A 82 00 20 01

02 05 00 00 00 00 00 20 80 00 00 7D 22 24 A5 A1

A6 52 9E 93 AF EE 10 D9 3B CB 4B 9A EE 46 12 0B

DE E0 9B 40 00 01 F2 E1 4F CB 87 5E 47

RTCM_Fragmenter: Sending fragment 2 of 2

0A 01 02 62 84 18 23 81 99 98 04 AC 4C EC F2 00

CD 75 E5

142 bytes RTCM1094

Sending fragmented RTCM message

RTCM_Fragmenter: Sending 142 bytes in fragments

RTCM_Fragmenter: Total fragments = 3

RTCM_Fragmenter: Sending fragment 1 of 3

0A 00 03 D3 00 88 44 60 00 58 EA 15 C2 00 20 0E

40 04 00 28 00 00 00 20 01 01 00 6D BE F9 6D 4D

5D 55 71 35 56 14 84 C8 CC 4C 09 BE 21 FF 5F 9E

AB 05 91 0B 3A 25 AC 49 54 A9 D9 49 72

RTCM_Fragmenter: Sending fragment 2 of 3

0A 01 03 A5 9D F1 7B BF 91 81 21 BC 45 17 0F 86

1B DF D7 DD BF 5F 76 05 94 C4 16 53 20 96 0A C2

58 9D 0A 9C 48 2A 5F 68 00 00 3E FB B5 FB EC 94

22 EA 00 8B D5 A0 00 00 F0 FC CB C3 F6

RTCM_Fragmenter: Sending fragment 3 of 3

0A 02 03 FC BC 9B BB B0 BA BB 0B B0 00 08 5D 95

C9 1E 9A 05 A2 6E 79 18 92 00 8D 53 D1

187 bytes RTCM1124

Sending fragmented RTCM message

RTCM_Fragmenter: Sending 187 bytes in fragments

RTCM_Fragmenter: Total fragments = 4

RTCM_Fragmenter: Sending fragment 1 of 4

0A 00 04 D3 00 B5 46 40 00 58 E9 3B 00 00 20 00

96 04 08 48 30 00 00 20 82 00 01 45 57 4E C4 EE

C2 A9 C1 25 AA 24 27 AB 25 A6 C6 5C 1C C0 43 F9

BC 14 DA 37 F2 A9 E1 7B 03 E0 87 8D 06

RTCM_Fragmenter: Sending fragment 2 of 4

0A 01 04 E0 8D 92 E6 03 C6 7B 8A CF A8 EF 38 05

79 4A 97 95 3C C2 8C 5A A4 B1 B6 66 2C E9 39 5C

09 78 12 66 24 3A 17 B1 3C 00 00 01 E3 41 03 72

7C 0D CE 9F CB C9 DF 2F 2A FC BB 8D FA

RTCM_Fragmenter: Sending fragment 3 of 4

0A 02 04 94 57 EA 35 E1 5E 97 85 7B 46 15 ED 34

00 00 01 6A AD 85 AB A3 E6 9A 67 9A 6D 1E 69 D9

04 B6 1C 12 DE 48 4B 71 56 01 77 77 77 77 76 17

77 77 77 60 00 00 3B 04 30 BD 0B B3 3F

RTCM_Fragmenter: Sending fragment 4 of 4

0A 03 04 14 EF 54 CC 31 C2 DC F2 37 30 20 1C A8

108 bytes RTCM1074

Sending fragmented RTCM message

RTCM_Fragmenter: Sending 108 bytes in fragments

RTCM_Fragmenter: Total fragments = 2

RTCM_Fragmenter: Sending fragment 1 of 2

0A 00 02 D3 00 66 43 20 00 58 EA 25 62 00 20 60

A2 02 80 80 00 00 00 20 20 00 00 55 75 A4 22 A3

A4 A6 27 A8 25 E2 C5 DC 81 10 CF B8 C4 3E 0F 86

90 C9 EA 31 58 C7 08 3E 00 9A E0 39 78

RTCM_Fragmenter: Sending fragment 2 of 2

0A 01 02 FC 91 61 23 FA 06 C9 2F 93 D1 60 C5 AF

06 3C F4 03 D4 90 0F 70 80 0E 26 7C 7B 64 11 55

50 45 66 F3 99 99 99 99 00 03 94 47 44 6B 45 25

6D 00 25 67 87

74 bytes RTCM1084

Sending fragmented RTCM message

RTCM_Fragmenter: Sending 74 bytes in fragments

RTCM_Fragmenter: Total fragments = 2

RTCM_Fragmenter: Sending fragment 1 of 2

0A 00 02 D3 00 44 43 C0 00 89 16 7A 22 00 20 01

02 05 00 00 00 00 00 20 80 00 00 7D 22 24 A5 A1

A6 12 96 97 AF 77 A7 EC 6A 68 5C D5 10 43 2C 5A

1F 7A 15 40 00 00 1A 26 A0 68 9B C0 44

RTCM_Fragmenter: Sending fragment 2 of 2

0A 01 02 84 78 B4 B5 81 99 98 04 AC 4C EC F1 80

82 63 D4

142 bytes RTCM1094

Sending fragmented RTCM message

RTCM_Fragmenter: Sending 142 bytes in fragments

RTCM_Fragmenter: Total fragments = 3

RTCM_Fragmenter: Sending fragment 1 of 3

0A 00 03 D3 00 88 44 60 00 58 EA 25 62 00 20 0E

40 04 00 28 00 00 00 20 01 01 00 6D BE F9 6D 4D

5D 55 71 35 56 15 84 48 DC 4C 08 BE 22 02 30 44

4C CA 0B 14 2E EE F9 DB E4 0C B0 0F 20

RTCM_Fragmenter: Sending fragment 2 of 3

0A 01 03 33 D8 A3 F1 25 11 68 21 8A 45 64 33 30

63 30 8C 0C C2 30 23 0A 0E E4 28 3C 3F BB 32 BE

ED 3F 00 C9 A8 03 14 08 00 00 3C 55 18 F1 52 28

22 B7 00 8B 09 60 00 00 03 37 58 0C E1

RTCM_Fragmenter: Sending fragment 3 of 3

0A 02 03 2C BC 9B BB B0 BB BB 0B B0 00 08 5D 95

D9 1F 9E 05 E2 6E 78 D7 92 00 F6 6B EC

142 bytes RTCM1094

Sending fragmented RTCM message

RTCM_Fragmenter: Sending 142 bytes in fragments

RTCM_Fragmenter: Total fragments = 3

RTCM_Fragmenter: Sending fragment 1 of 3

0A 00 03 D3 00 88 44 60 00 58 EA 35 02 00 20 0E

40 04 00 28 00 00 00 20 01 01 00 6D BE F9 6D 4D

5D 55 71 35 56 17 83 C8 DC 4C 06 BE 22 2D 01 79

EF 8E 86 9D 24 38 50 6E 8F 6F BE D5 2D

RTCM_Fragmenter: Sending fragment 2 of 3

0A 01 03 C1 E3 57 46 8C 91 53 21 5E 45 4B 56 F6

AA AF 40 5E FD 01 76 0E 8A 68 3A 2A 80 E0 8A 03

82 A2 F6 F9 FB DB D5 98 00 00 01 AE FD 06 B9 48

22 8B 60 8A 5B 20 00 00 F5 72 F7 D5 CF

RTCM_Fragmenter: Sending fragment 3 of 3

0A 02 03 9C BC AB BB B0 BB BB 0B B0 00 08 5D 95

D9 1E 9E 05 A2 6E 78 D8 92 00 69 13 46

187 bytes RTCM1124

Sending fragmented RTCM message

RTCM_Fragmenter: Sending 187 bytes in fragments

RTCM_Fragmenter: Total fragments = 4

RTCM_Fragmenter: Sending fragment 1 of 4

0A 00 04 D3 00 B5 46 40 00 58 E9 5A 40 00 20 00

96 04 08 48 30 00 00 20 82 00 01 45 57 4E C4 EE

C2 A9 C1 25 AA 24 27 AB 25 A6 C6 9C 44 C4 42 FA

3C 0C D2 37 72 AA 00 D8 4D AB 5B 1A 38

RTCM_Fragmenter: Sending fragment 2 of 4

0A 01 04 D5 71 79 EC 2D D2 C3 A3 67 10 5E 07 20

AF 41 03 82 14 DF 34 1F 78 3B 40 43 80 A4 80 D3

34 1B E7 AE CE CA 0D 85 FC 00 00 1E C7 37 7C 6C

E5 F1 B7 A7 D8 13 7F 60 4F FD 80 31 F1

RTCM_Fragmenter: Sending fragment 3 of 4

0A 02 04 0D 2F C4 17 A0 2C 14 00 B1 2C 02 C5 1C

00 00 00 7D E5 01 F8 92 04 74 60 11 D3 C0 47 7E

7A 07 EB E8 26 4F A0 8F 16 0D 77 77 77 77 76 17

77 77 77 60 00 00 3B 04 30 3D 0B B3 3F

RTCM_Fragmenter: Sending fragment 4 of 4

0A 03 04 14 EF 54 CC 11 C2 D4 F2 39 30 22 CC 24

116 bytes RTCM1074

Sending fragmented RTCM message

RTCM_Fragmenter: Sending 116 bytes in fragments

RTCM_Fragmenter: Total fragments = 2

RTCM_Fragmenter: Sending fragment 1 of 2

0A 00 02 D3 00 6E 43 20 00 58 EA 44 A2 00 20 60

A2 02 90 80 00 00 00 20 20 00 00 55 75 69 08 A8

E9 29 89 EA 09 E9 78 99 75 22 44 93 E6 2D 0F 3C

E0 EE 4E 8E 93 98 7F 49 6C 16 F5 2F D2

RTCM_Fragmenter: Sending fragment 2 of 2

0A 01 02 29 0C 6F 80 CA C0 D0 81 D6 3C A1 FA FA

4D CB C4 03 F0 97 5B C2 DD 2B 0B 77 EC 14 82 00

6F 21 A0 00 00 03 3B 40 0C F6 A9 CC CC CC C0 C9

00 0E 51 25 11 B5 1C 6E 56 D8 65 91 56

74 bytes RTCM1084

Sending fragmented RTCM message

RTCM_Fragmenter: Sending 74 bytes in fragments

RTCM_Fragmenter: Total fragments = 2

RTCM_Fragmenter: Sending fragment 1 of 2

0A 00 02 D3 00 44 43 C0 00 89 16 99 62 00 20 01

02 05 00 00 00 00 00 20 80 00 00 7D 22 24 A5 A1

A5 92 96 A1 AD 0A ED 13 03 A2 F7 4A 50 3D D0 F8

40 AE 82 C0 00 01 E8 CE 7F A3 3B 00 3F

RTCM_Fragmenter: Sending fragment 2 of 2

0A 01 02 4E 01 F1 5D 81 99 98 04 AC CC E4 F1 80

26 B1 54

142 bytes RTCM1094

Sending fragmented RTCM message

RTCM_Fragmenter: Sending 142 bytes in fragments

RTCM_Fragmenter: Total fragments = 3

RTCM_Fragmenter: Sending fragment 1 of 3

0A 00 03 D3 00 88 44 60 00 58 EA 44 A2 00 20 0E

40 04 00 28 00 00 00 20 01 01 00 6D BE F9 6D 4D

5D 55 71 35 56 18 83 88 EC 48 05 BE 22 3F D3 3F

93 33 02 E6 1E 01 B2 01 48 D2 E9 9B 83

RTCM_Fragmenter: Sending fragment 2 of 3

0A 01 03 4C 3E 0C 3B F6 91 41 21 3A 44 EC 7A C0

F2 4F F4 CE 7F D3 1E F3 06 EF CC 1B F0 06 05 C0

18 97 0D 2C F0 34 A1 98 00 00 3F 09 61 FC 23 38

22 66 E0 89 C8 E0 00 00 07 AF AC 1E C1

RTCM_Fragmenter: Sending fragment 3 of 3

0A 02 03 EC BC AB BB B0 BB BB 0B B0 00 08 5D 95

C9 1E 9E 05 A2 6E 78 D8 92 00 16 8C 77

142 bytes RTCM1094

Sending fragmented RTCM message

RTCM_Fragmenter: Sending 142 bytes in fragments

RTCM_Fragmenter: Total fragments = 3

RTCM_Fragmenter: Sending fragment 1 of 3

0A 00 03 D3 00 88 44 60 00 58 EA 54 42 00 20 0E

40 04 00 28 00 00 00 20 01 01 00 6D BE F9 6D 4D

5D 55 71 35 56 19 83 08 FC 48 04 BE 22 52 A5 65

37 F7 80 EF 1A CB 1F 94 1C 36 48 62 30

RTCM_Fragmenter: Sending fragment 2 of 3

0A 01 03 D9 F8 C1 B1 61 91 32 21 1C 44 BF 9E A7

3A 00 A9 60 42 A5 67 F7 84 FF DE 14 5F 2B B1 3C

AF 26 03 62 C0 0D 78 88 00 00 3C 64 3E F1 8E 9C

22 49 D0 89 54 E0 00 00 F9 ED 43 E7 B8

RTCM_Fragmenter: Sending fragment 3 of 3

0A 02 03 4C BC AB BC B0 BB BB 0B B0 00 08 5D 95

D9 1E 9E 05 A2 6E 78 D8 92 00 8C C3 6F

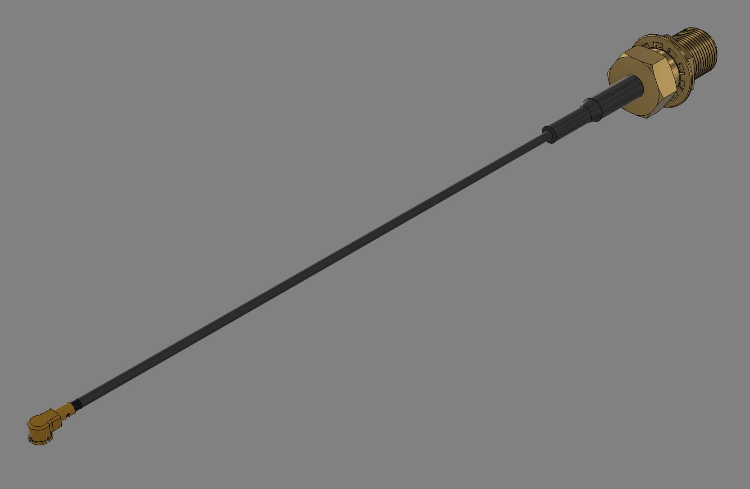
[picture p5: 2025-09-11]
Hardware/sma-to-umcx-cable-1.snapshot.1/SMA to UMCX Cable 1.png

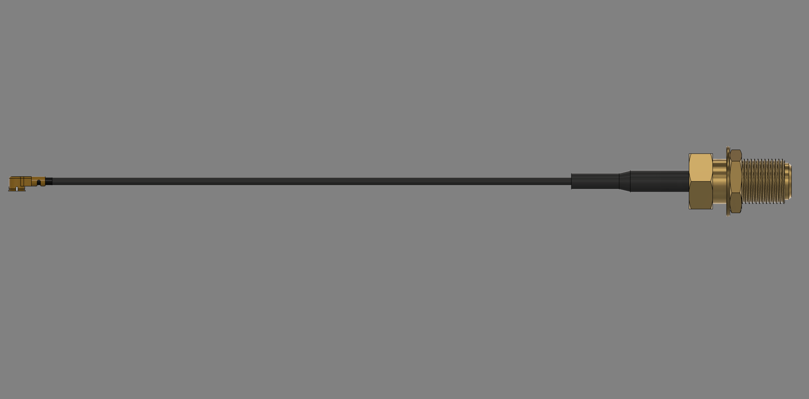
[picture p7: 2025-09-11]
Hardware/sma-to-umcx-cable-1.snapshot.1/SMA to UMCX Cable 2.png

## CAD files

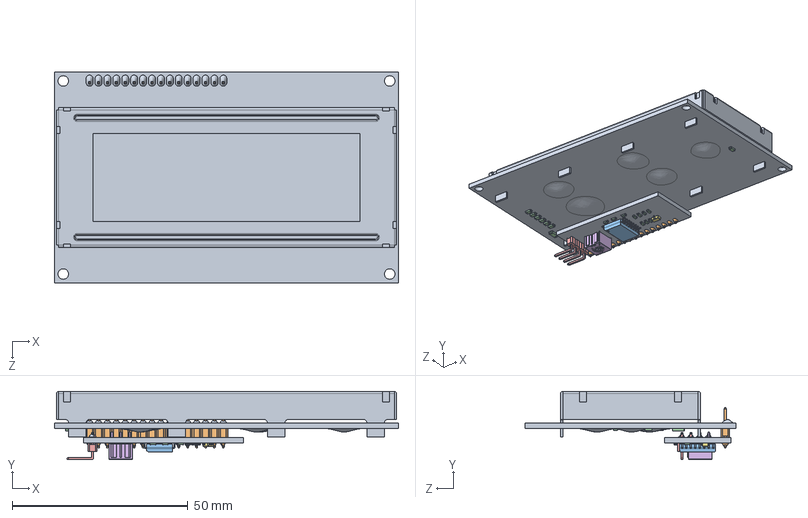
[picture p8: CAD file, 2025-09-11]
Hardware/20x4_LCD_Step/LCD2004 IIC_I2C, 20x4 - Sestava.SLDASM
98.0 x 19.5 x 60.0 mm
LCD2004 IIC_I2C, 20x4
Kolíková lišta přímá krátká - 2,54mm
SO16W
SMD rezistory x 18
Kolíková lišta úhlová R2 krátká - 2,54mm
TRIMR - 10K, BOURNS 3362P-103LF
SOT23-3

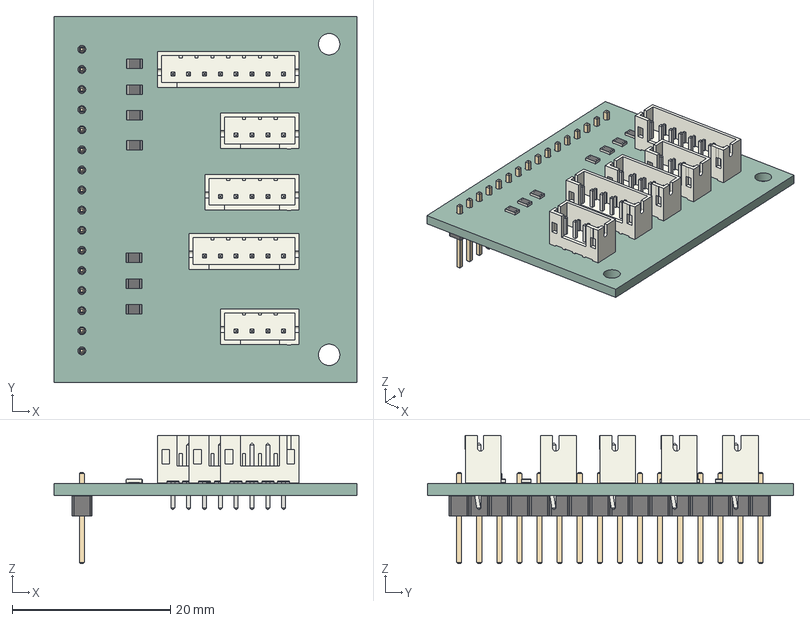
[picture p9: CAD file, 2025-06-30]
BS/Janus HW/Janus IO card/Janus IO card.step
38.2 x 46.2 x 16.2 mm
R_0805_2012Metric x 7
JST_PH_B4B-PH-K_1x04_P2.00mm_Vertical x 2
JST_PH_B6B-PH-K_1x06_P2.00mm_Vertical
JST_PH_B5B-PH-K_1x05_P2.00mm_Vertical
JST_PH_B8B-PH-K_1x08_P2.00mm_Vertical
PinHeader_1x16_P2.54mm_Vertical
Janus IO card_PCB

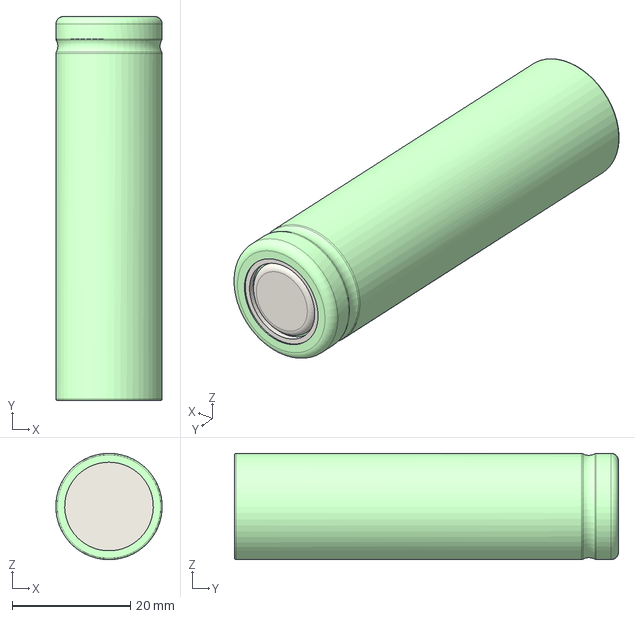
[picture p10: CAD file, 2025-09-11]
Hardware/18650/Generic Li Ion 1850 cell.step
18.0 x 65.0 x 18.0 mm

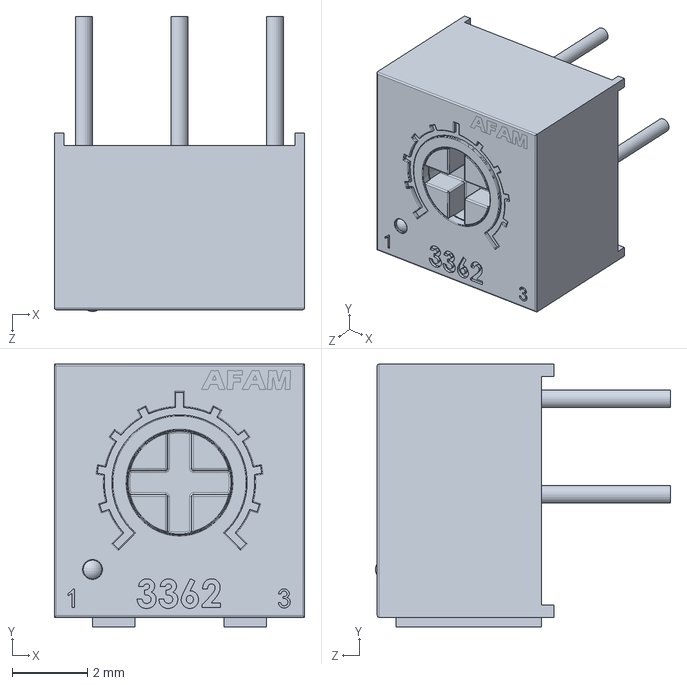
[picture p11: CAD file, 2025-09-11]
Hardware/20x4_LCD_Step/TRIMR - 10K, BOURNS 3362P-103LF.SLDPRT
6.66 x 6.99 x 7.85 mm

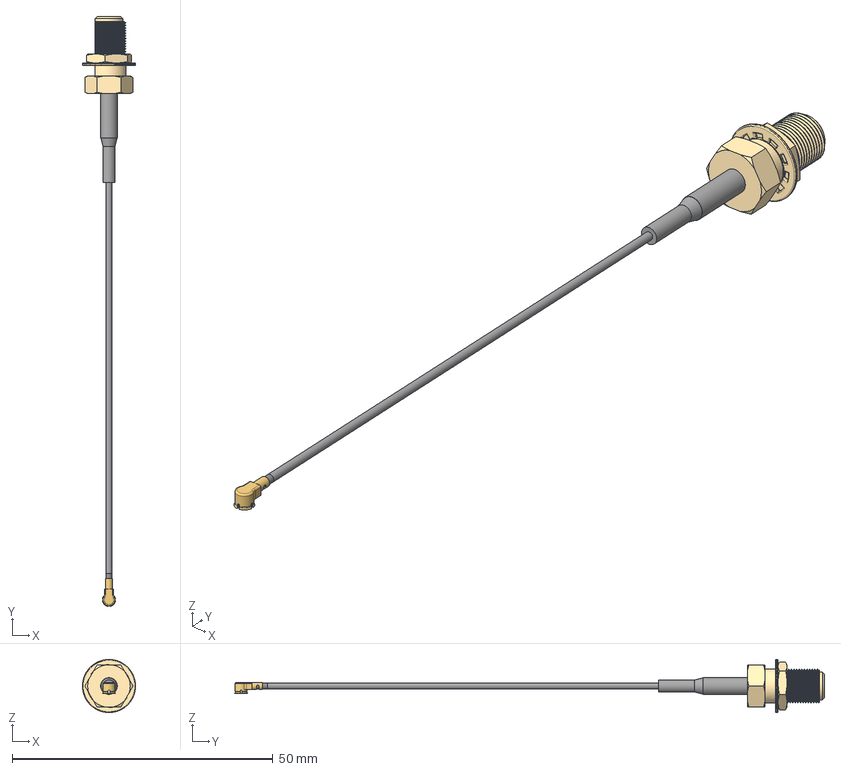
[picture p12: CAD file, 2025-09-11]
Hardware/sma-to-umcx-cable-1.snapshot.1/SMA to UMCX Cable.step
10.2 x 113.2 x 10.2 mm
Connector_2
Washer
Nut
Cable 75 mm

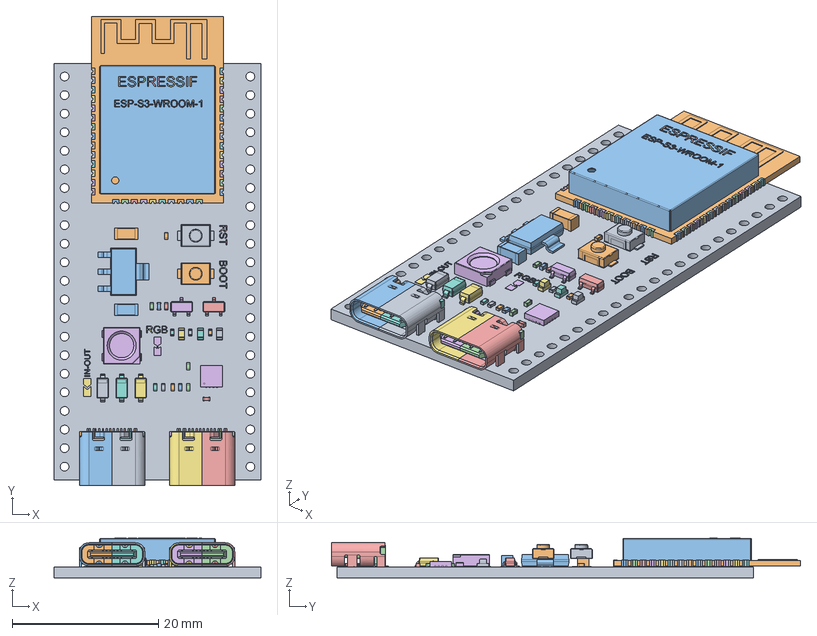
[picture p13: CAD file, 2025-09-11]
Hardware/zsp32-s3-wroom-1-devkit-1.snapshot.9/ESP32-S3-WROOM-1_devkit_2xUSBC.FCStd
28.3 x 64.1 x 5.45 mm
Corps
PCB_mince
Text_ESP32
Text_ESP033
Text_ESP034
Text_ESP035
Text_ESP036
Text_ESP037
Text_ESP038
Text_ESP039
Text_ESP040
Text_ESP041
Text_ESP042
Text_ESP043
Text_ESP044
Text_ESP045
Text_Espressif
Text_Espressif001
Text_Espressif002
Text_Espressif003
Text_Espressif004
Text_Espressif005
Text_Espressif006
Text_Espressif007
Text_Espressif008
pin_002
pin_003
pin_004
pin_005
pin_006
pin_007
pin_008
pin_009
pin_010
pin_011
pin_012
pin_013
pin_014
pin_015
pin_016
pin_017
pin_018
pin_019
pin_020
pin_021
pin_022
pin_023
pin_024
pin_025
pin_026
pin_027
pin_028
pin_029
pin_030
pin_031
pin_032
pin_033
pin_034
pin_035
pin_036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

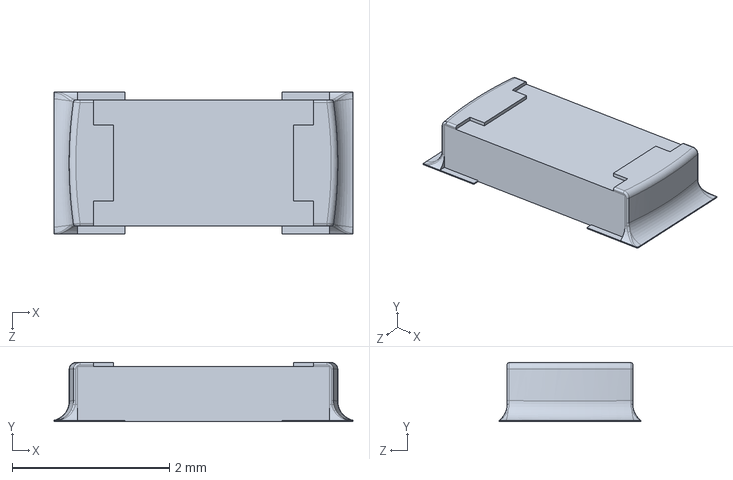
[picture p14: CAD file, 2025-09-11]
Hardware/20x4_LCD_Step/SMD rezistory.SLDPRT
3.80 x 0.75 x 1.80 mm

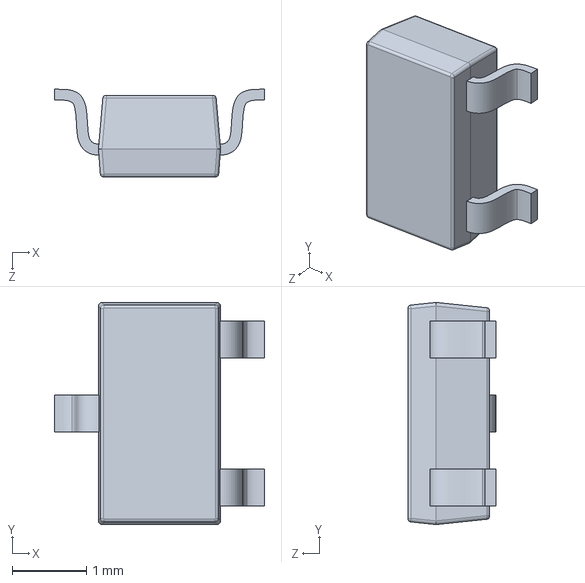
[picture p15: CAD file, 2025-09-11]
Hardware/20x4_LCD_Step/SOT23-3.SLDPRT
2.84 x 3.00 x 1.18 mm

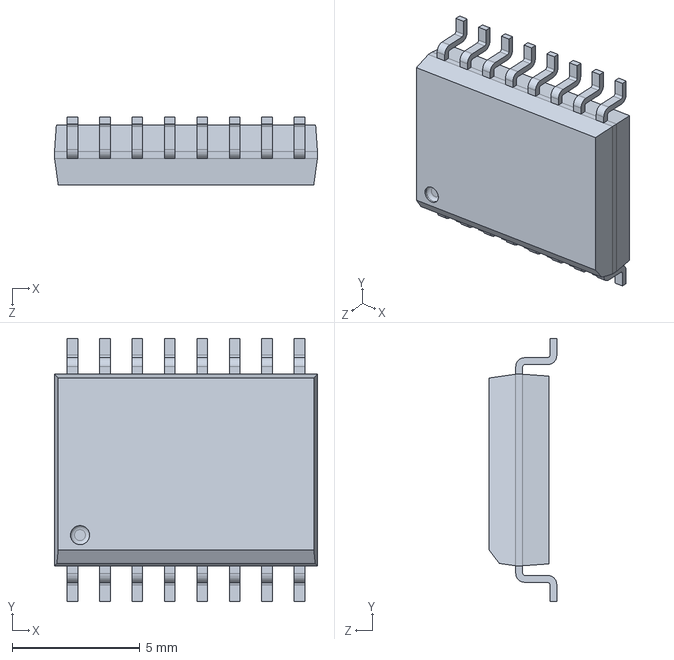
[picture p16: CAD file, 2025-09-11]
Hardware/20x4_LCD_Step/SO16W.SLDPRT
10.3 x 10.3 x 2.65 mm

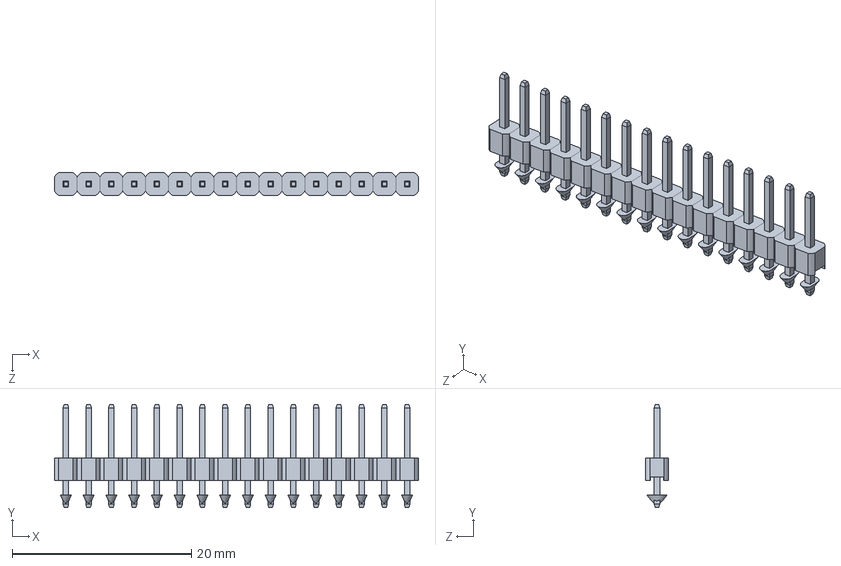
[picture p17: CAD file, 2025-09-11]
Hardware/20x4_LCD_Step/Kolíková lišta přímá krátká - 2,54mm.SLDPRT
40.6 x 11.5 x 2.54 mm

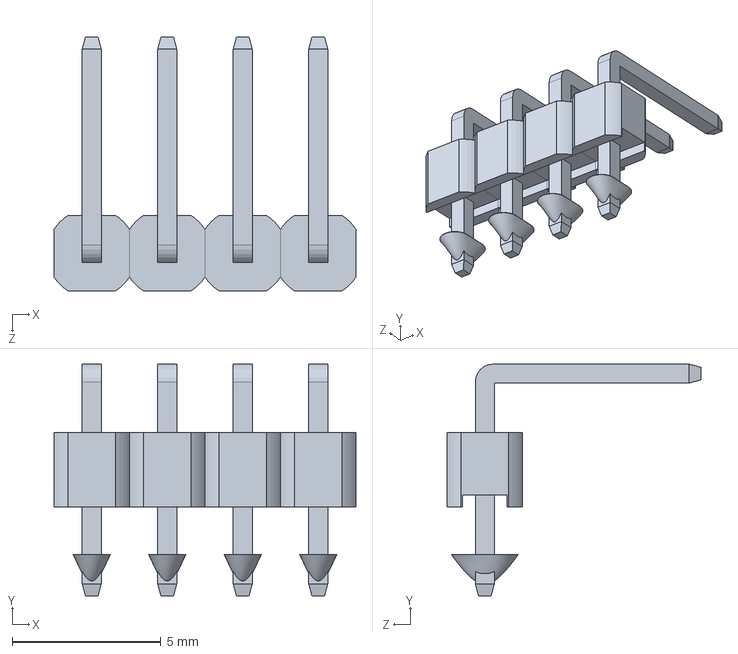
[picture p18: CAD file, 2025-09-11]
Hardware/20x4_LCD_Step/Kolíková lišta úhlová R2 krátká - 2,54mm.SLDPRT
10.2 x 7.80 x 8.54 mm

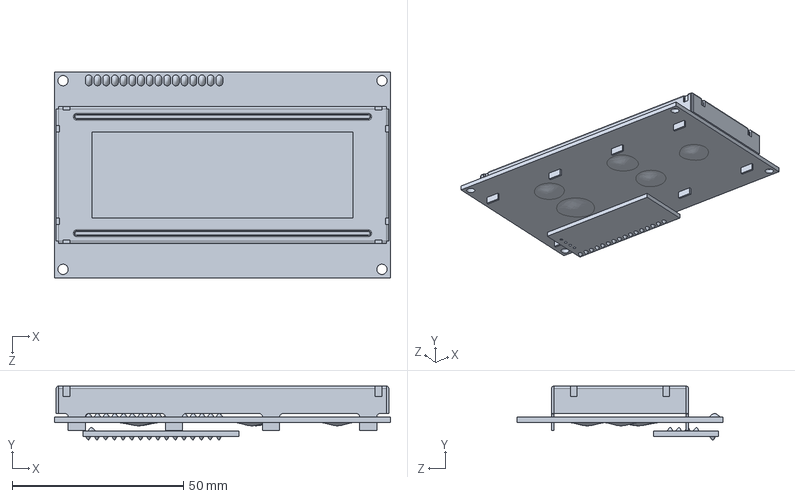
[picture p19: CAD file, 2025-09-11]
Hardware/20x4_LCD_Step/LCD2004 IIC_I2C, 20x4.SLDPRT
98.0 x 15.7 x 60.0 mm

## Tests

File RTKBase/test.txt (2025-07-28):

    Directory: C:\Users\JanOlavEndrerud\Documents\Arduino\Janus\rtkbase

Mode                 LastWriteTime         Length Name                                                                 
----                 -------------         ------ ----                                                                 
d-----        13.07.2025     19:02                src                                                                  
d-----        27.06.2025     21:53                __vm                                                                 
-a----        30.06.2025     12:31            613 LCD.cpp                                                              
-a----        30.06.2025     12:31            278 LCD.h                                                                
-a----        03.07.2025     22:33           1970 RTKBase.h                                                            
-a----        13.07.2025     19:02          12025 RTKBase.ino                                                          
-a----        13.07.2025     18:49         196406 RTKBase.vcxproj                                                      
-a----        03.07.2025     22:35           1657 RTKBase.vcxproj.filters                                              
-a----        13.07.2025     19:04              0 test.txt                                                             
-a----        28.06.2025     11:03           1961 TwoButtonMenu.h                                                      

    Directory: C:\Users\JanOlavEndrerud\Documents\Arduino\Janus\rtkbase\src

Mode                 LastWriteTime         Length Name                                                                 
----                 -------------         ------ ----                                                                 
------        23.05.2025     11:02            858 arduino folders read me.txt                                          
-a----        13.07.2025     19:02           1110 RTCMFwd.cpp                                                          
-a----        13.07.2025     18:56            250 RTCMFwd.h                                                            
-a----        01.07.2025     16:36           1585 SurveyIn.cpp                                                         
-a----        30.06.2025     12:11            237 SurveyIn.h                                                           

    Directory: C:\Users\JanOlavEndrerud\Documents\Arduino\Janus\rtkbase\__vm

Mode                 LastWriteTime         Length Name                                                                 
----                 -------------         ------ ----                                                                 
------        13.07.2025     18:09           1178 .RTKBase.vsarduino.h                                                 
-a----        13.07.2025     19:03          97742 Compile.vmps.xml                                                     
-a----        19.06.2025     20:51          90171 Configuration.Debug.vmps.xml                                         
-a----        13.07.2025     18:47          97742 Upload.vmps.xml

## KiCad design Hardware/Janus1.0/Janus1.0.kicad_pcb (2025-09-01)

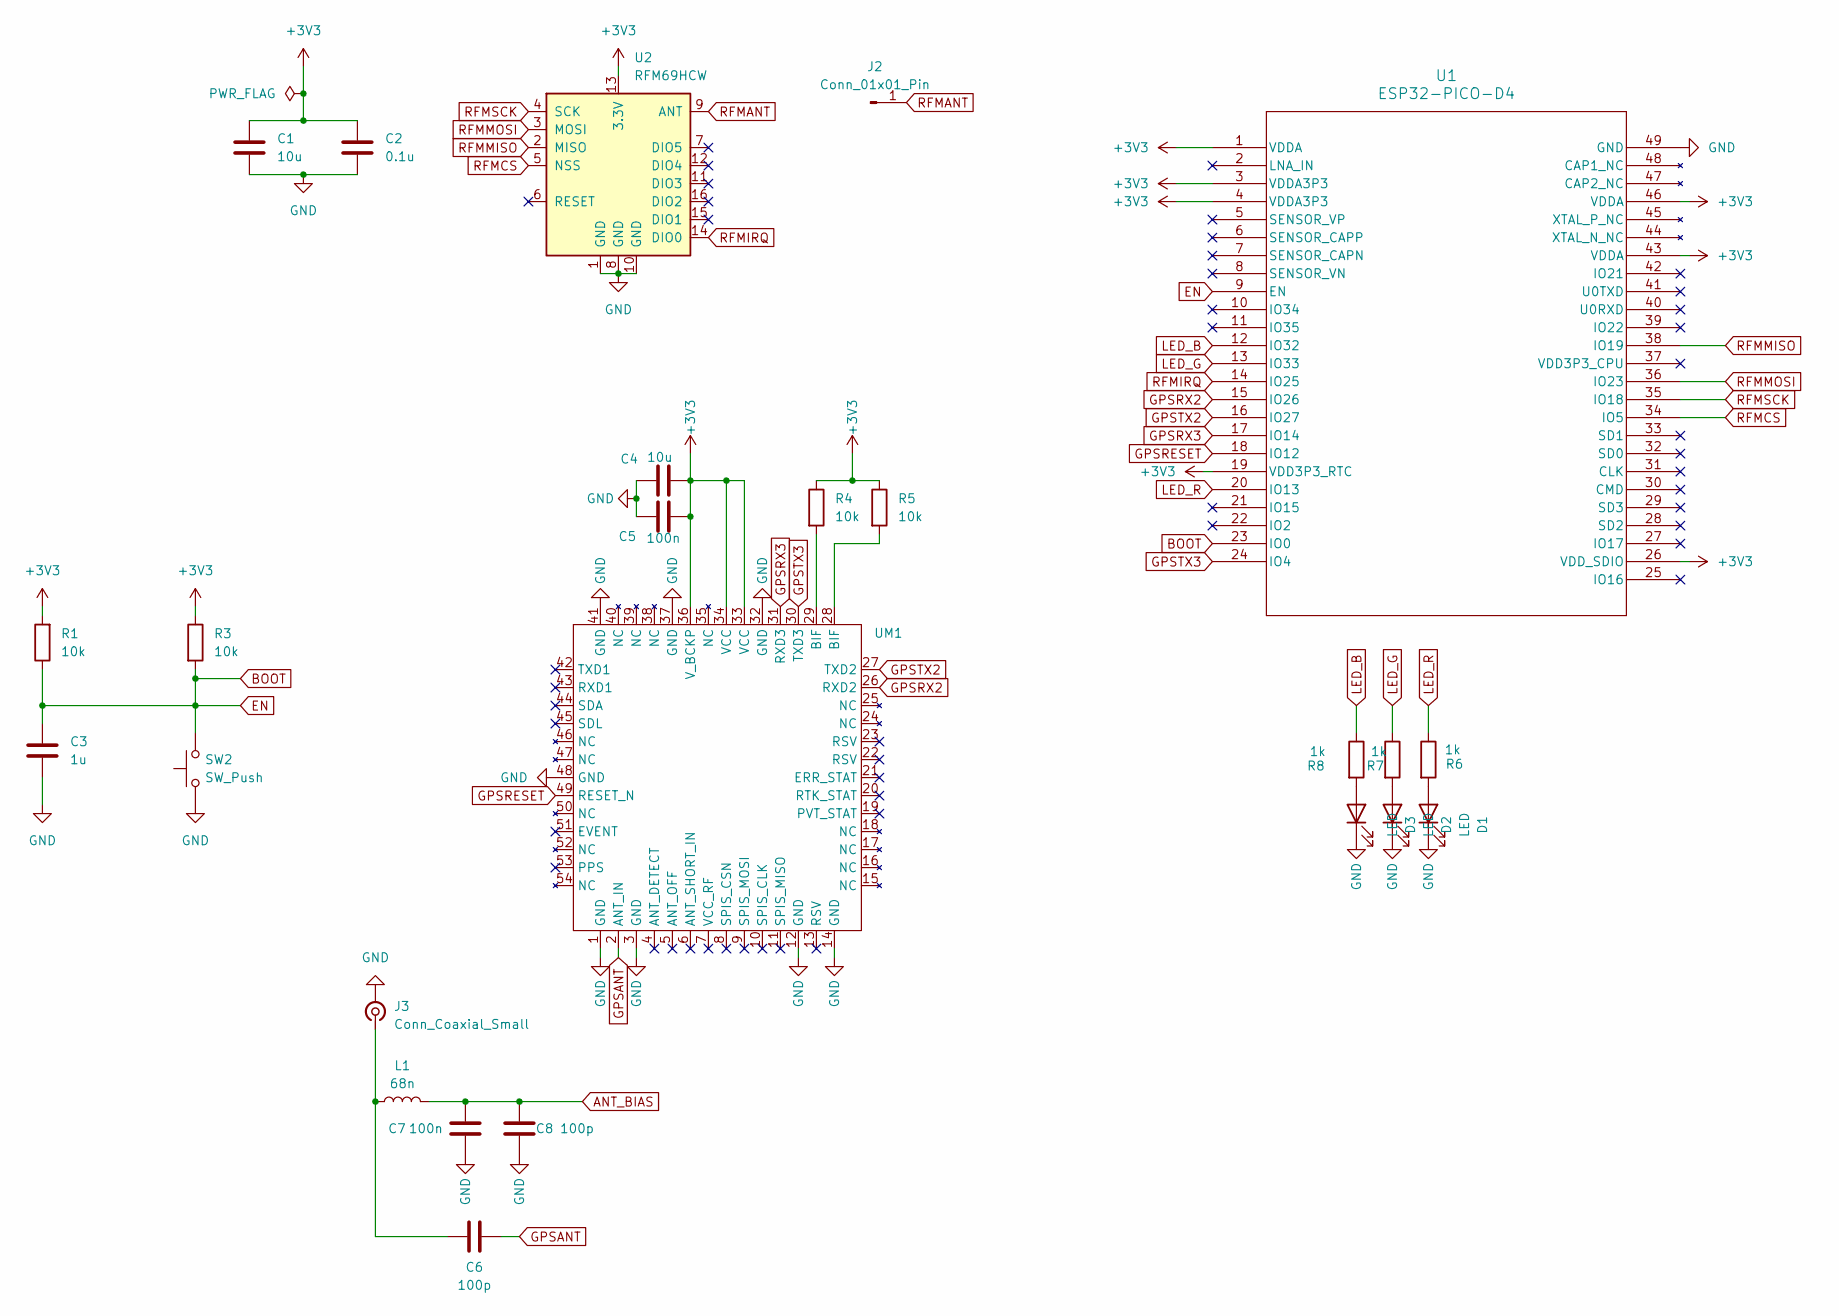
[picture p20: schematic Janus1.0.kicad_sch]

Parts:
C1, C4: 10u; C_0201_0603Metric
C2: 0.1u; C_0201_0603Metric
C3: 1u; C_0201_0603Metric
C5, C7: 100n; C_0201_0603Metric
C6, C8: 100p; C_0201_0603Metric
D1, D2, D3: LED; LED_0603_1608Metric
J2: Conn_01x01_Pin; PinHeader_1x01_P2.54mm_Vertical
J3: Conn_Coaxial_Small; U.FL_Hirose_U.FL-R-SMT-1_Vertical
L1: 68n; L_0201_0603Metric
R1, R3, R4, R5: 10k; R_0201_0603Metric
R6, R7, R8: 1k; R_0201_0603Metric
SW2: SW_Push; SW_Push_1P1T_NO_CK_PTS125Sx43PSMTR
U1: ESP32-PICO-D4; ESP32-PICO-D4_EXP
U2: RFM69HCW; MOD_COM-13909
UM1: UM980

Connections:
+3V3: C1.1, C2.1, C4.1, C5.1, R1.2, R3.1, R4.1, R5.1, U1.1 (VDDA), U1.3 (VDDA3P3), U1.4 (VDDA3P3), U1.19 (VDD3P3_RTC), U1.26 (VDD_SDIO), U1.43 (VDDA), U1.46 (VDDA), U2.13 (3.3V), UM1.33 (VCC), UM1.34 (VCC), UM1.36 (V_BCKP)
ANT_BIAS: C7.2, C8.2, L1.2
BOOT: C3.1, R1.1, R3.2, SW2.2, U1.9 (EN), U1.23 (IO0)
GND: C1.2, C2.2, C3.2, C4.2, C5.2, C7.1, C8.1, D1.1 (K), D2.1 (K), D3.1 (K), J3.2 (Ext), SW2.1, U1.49 (GND), U2.1 (GND), U2.8 (GND), U2.10 (GND), UM1.1 (GND), UM1.3 (GND), UM1.12 (GND), UM1.14 (GND), UM1.32 (GND), UM1.37 (GND), UM1.41 (GND), UM1.48 (GND)
GPSANT: C6.2, UM1.2 (ANT_IN)
GPSRESET: U1.18 (IO12), UM1.49 (RESET_N)
GPSRX2: U1.15 (IO26), UM1.26 (RXD2)
GPSRX3: U1.17 (IO14), UM1.31 (RXD3)
GPSTX2: U1.16 (IO27), UM1.27 (TXD2)
GPSTX3: U1.24 (IO4), UM1.30 (TXD3)
LED_B: R8.1, U1.12 (IO32)
LED_G: R7.1, U1.13 (IO33)
LED_R: R6.1, U1.20 (IO13)
unnamed: D1.2 (A), R6.2
unnamed: D2.2 (A), R7.2
unnamed: D3.2 (A), R8.2
unnamed: C6.1, J3.1 (In), L1.1
unnamed: R4.2, UM1.29 (BIF)
unnamed: R5.2, UM1.28 (BIF)
RFMANT: J2.1, U2.9 (ANT)
RFMCS: U1.34 (IO5), U2.5 (NSS)
RFMIRQ: U1.14 (IO25), U2.14 (DIO0)
RFMMISO: U1.38 (IO19), U2.2 (MISO)
RFMMOSI: U1.36 (IO23), U2.3 (MOSI)
RFMSCK: U1.35 (IO18), U2.4 (SCK)

Board: 4 copper layers, 25 parts (0 on the bottom side), 25 nets, no tracks yet.

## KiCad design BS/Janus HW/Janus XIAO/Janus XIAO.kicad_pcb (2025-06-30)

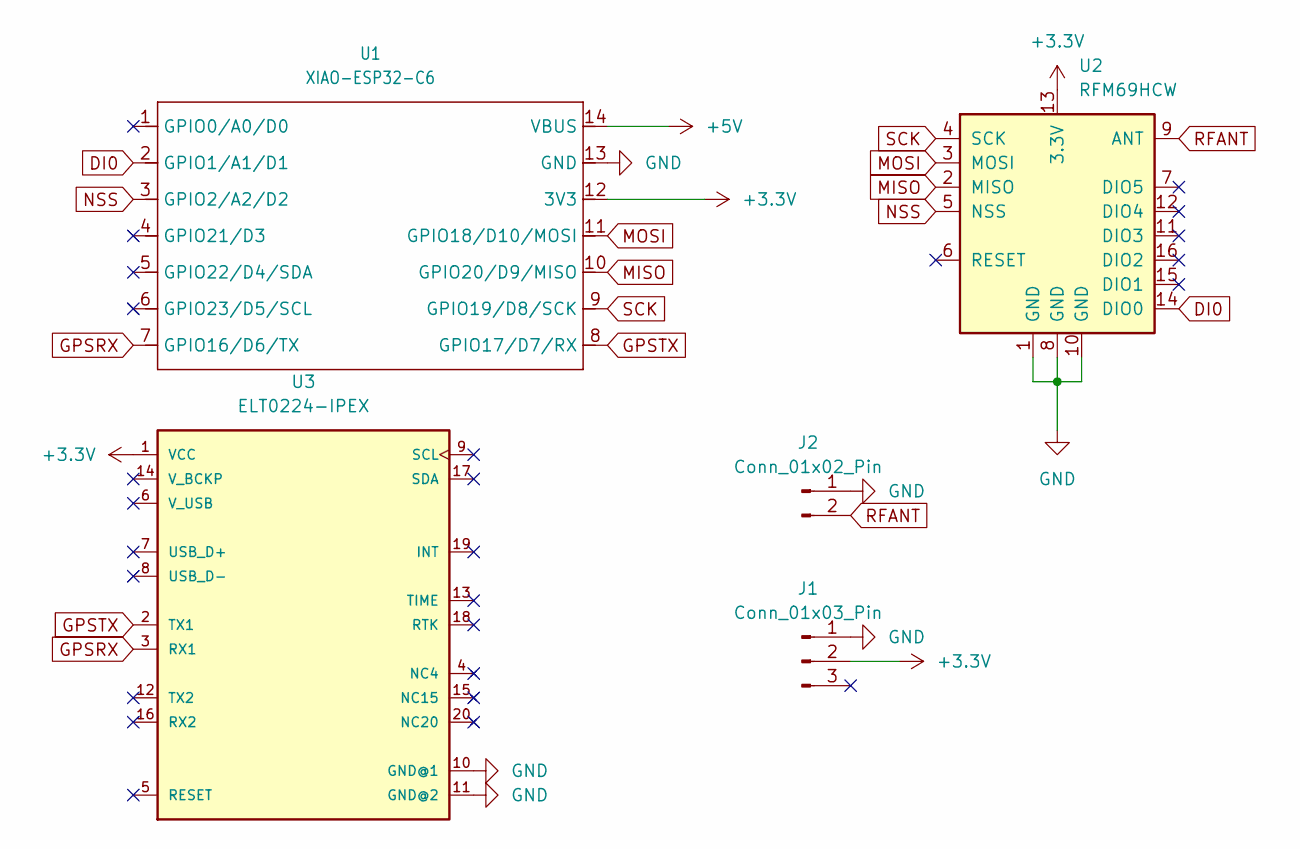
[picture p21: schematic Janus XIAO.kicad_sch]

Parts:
J1: Conn_01x03_Pin; PinHeader_1x03_P2.54mm_Vertical
J2: Conn_01x02_Pin; PinHeader_1x02_P2.54mm_Vertical
U1: XIAO-ESP32-C6; MCU_Seeed_ESP32C6 joe
U2: RFM69HCW; HOPERF_RFM9XW_SMD
U3: ELT0224-IPEX

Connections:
+3.3V: J1.2, U1.12 (3V3), U2.13 (3.3V), U3.1 (VCC)
+5V: U1.14 (VBUS)
DI0: U1.2 (GPIO1/A1/D1), U2.14 (DIO0)
GND: J1.1, J2.1, U1.13 (GND), U2.1 (GND), U2.8 (GND), U2.10 (GND), U3.10 (GND@1), U3.11 (GND@2)
GPSRX: U1.7 (GPIO16/D6/TX), U3.3 (RX1)
GPSTX: U1.8 (GPIO17/D7/RX), U3.2 (TX1)
MISO: U1.10 (GPIO20/D9/MISO), U2.2 (MISO)
MOSI: U1.11 (GPIO18/D10/MOSI), U2.3 (MOSI)
NSS: U1.3 (GPIO2/A2/D2), U2.5 (NSS)
RFANT: J2.2, U2.9 (ANT)
SCK: U1.9 (GPIO19/D8/SCK), U2.4 (SCK)

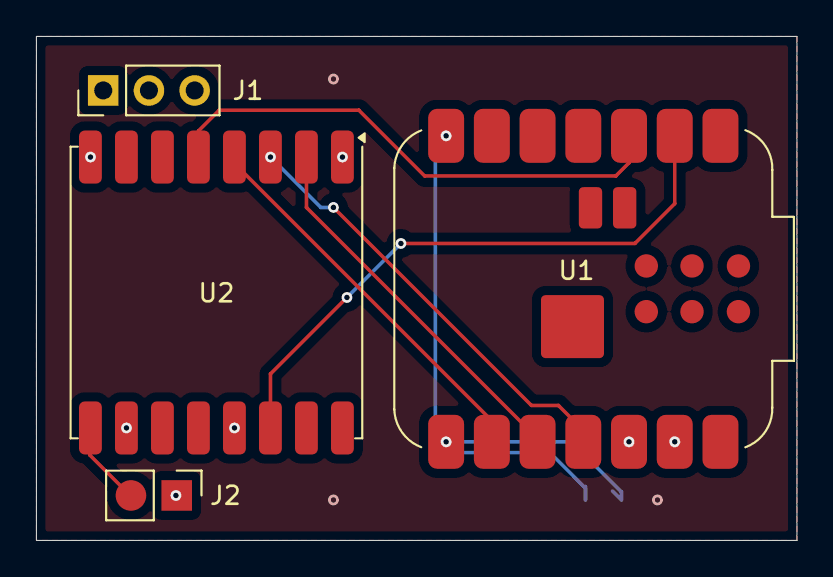
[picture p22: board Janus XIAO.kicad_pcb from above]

Board: 4 copper layers, 42.2 x 28.0 mm, 5 parts (1 on the bottom side), 10 nets.

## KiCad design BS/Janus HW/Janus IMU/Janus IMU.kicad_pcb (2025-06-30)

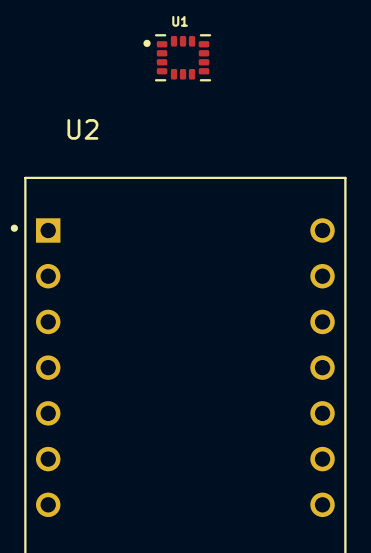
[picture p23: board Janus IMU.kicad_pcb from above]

Board: 2 copper layers, 3 parts (1 on the bottom side), 3 nets, no tracks yet.

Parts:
U1: ICM-42688-P; PQFN50P300X250X97-14N
U2: XIAO ESP32-C6; MODULE_113991054
U4: RFM69HCW; HOPERF_RFM9XW_SMD

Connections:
+3.3V: U1.8 (VDD), U2.12 (VCC_3V3), U4.13 (3.3V)
GND: U1.6 (GND), U2.13 (GND), U4.1 (GND), U4.8 (GND), U4.10 (GND)
SCK: U4.2 (MISO), U4.3 (MOSI), U4.4 (SCK), U4.5 (NSS), U4.14 (DIO0)

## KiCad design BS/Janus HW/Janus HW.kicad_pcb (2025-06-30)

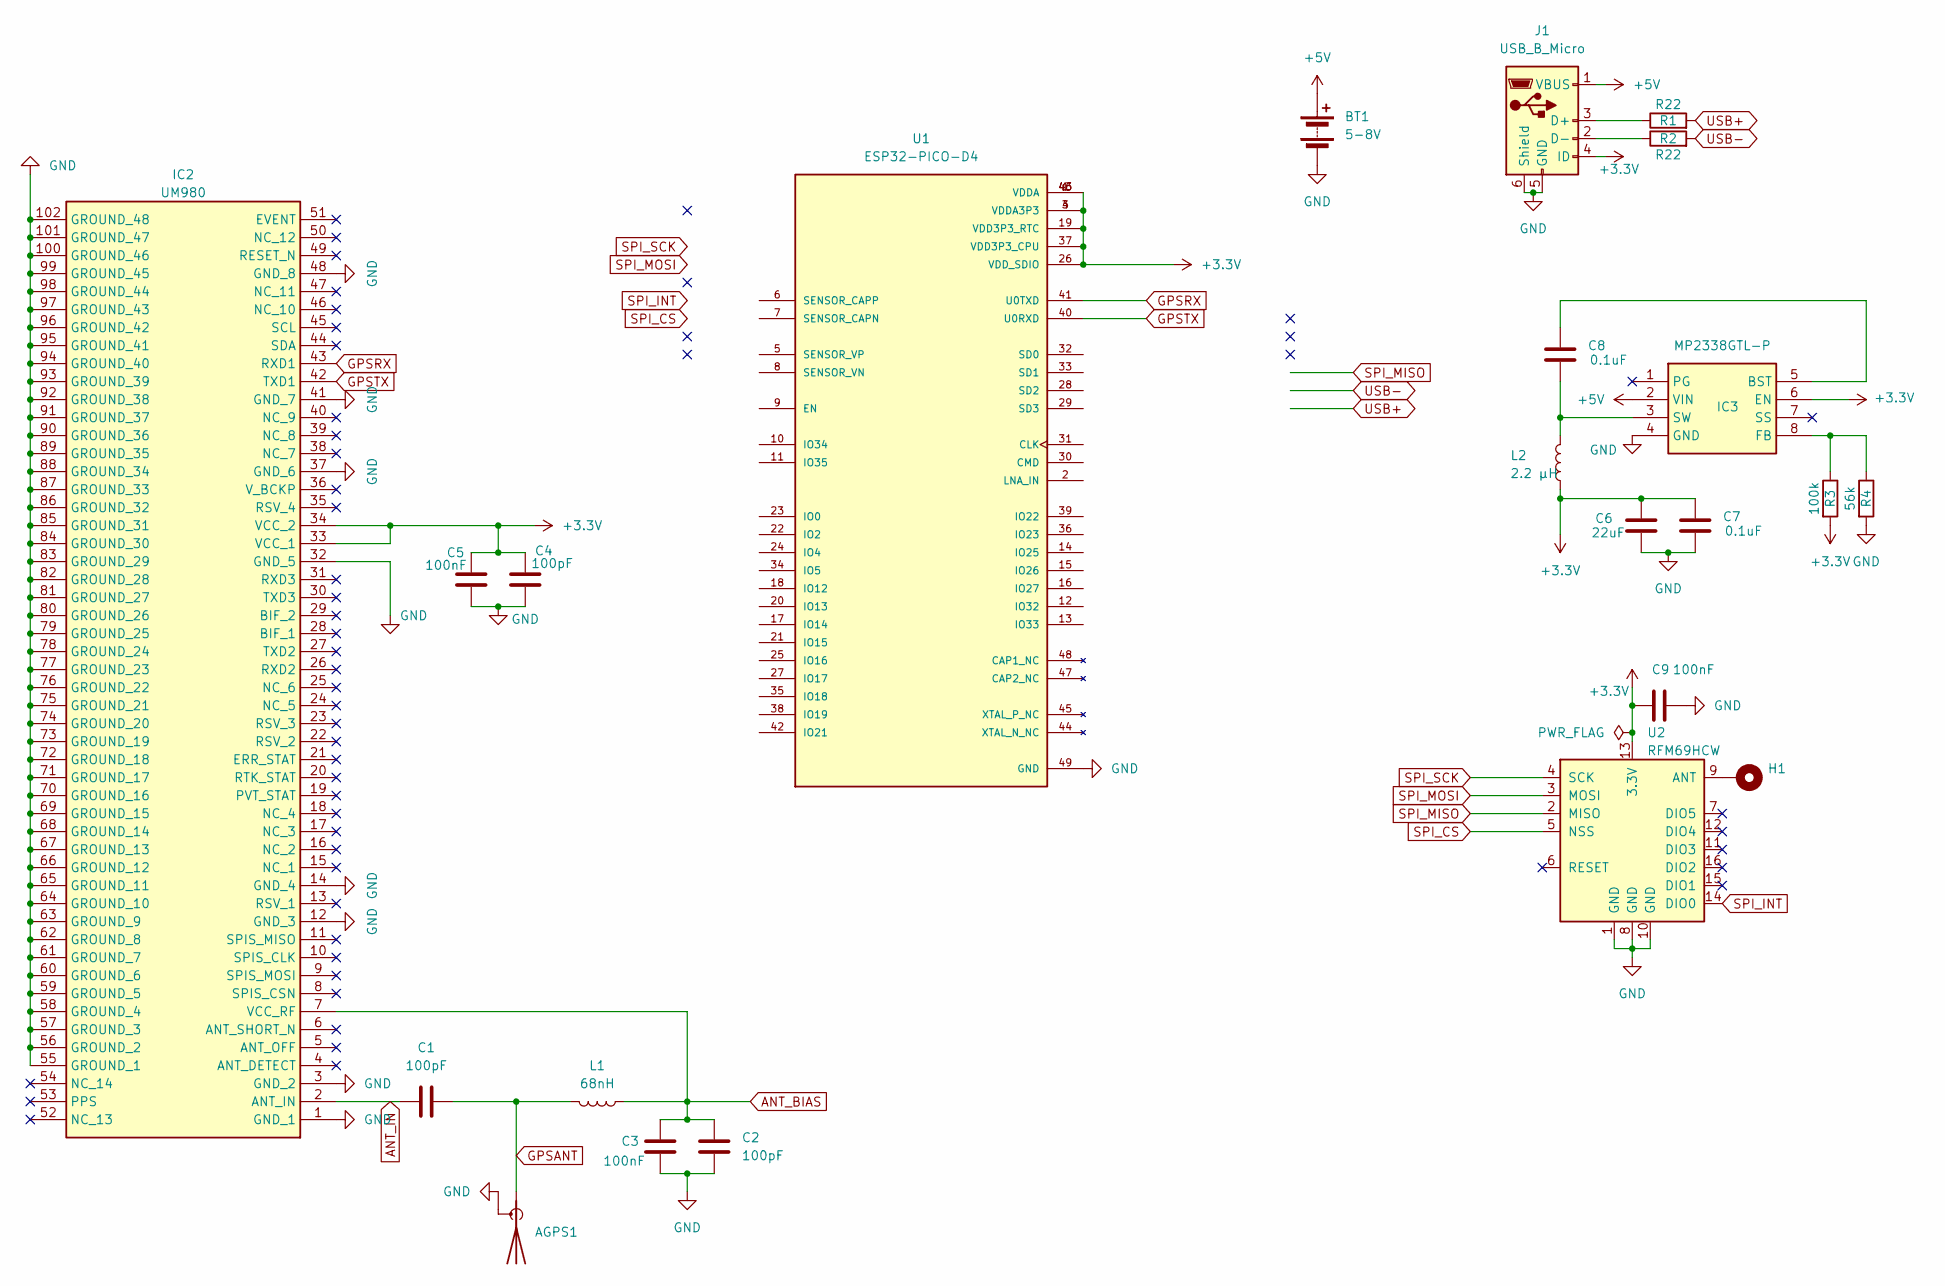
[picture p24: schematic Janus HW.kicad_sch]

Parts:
AGPS1: Antenna_Shield; U.FL_Molex_MCRF_73412-0110_Vertical
BT1: 5-8V
C1, C2, C4: 100pF; C_0201_0603Metric_Pad0.64x0.40mm_HandSolder
C3, C5, C9: 100nF; C_0201_0603Metric_Pad0.64x0.40mm_HandSolder
C6: 22uF; C_0201_0603Metric_Pad0.64x0.40mm_HandSolder
C7, C8: 0.1uF; C_0201_0603Metric_Pad0.64x0.40mm_HandSolder
H1: MountingHole_Pad; PinHeader_1x01_P1.27mm_Vertical
IC2: UM980; Manufacturer_Part_Number UM980
IC3: MP2338GTL-P; SOTFL50P160X60-8N; Manufacturer_Part_Number MP2338GTL-P; Mouser Part Number 946-MP2338GTL-P
J1: USB_B_Micro; USB_Micro-B_Amphenol_10118194-0001LF_Horizontal
L1: 68nH; L_0201_0603Metric
L2: 2.2 µH; L_0805_2012Metric
R1, R2: R22; R_0201_0603Metric_Pad0.64x0.40mm_HandSolder
R3: 100k; R_0201_0603Metric_Pad0.64x0.40mm_HandSolder
R4: 56k; R_0201_0603Metric_Pad0.64x0.40mm_HandSolder
U1: ESP32-PICO-D4; QFN-48-1EP_6x6mm_P0.4mm_EP4.3x4.3mm_ThermalVias; PARTREV v1.9; DigiKey_Part_Number 1904-1029-2-ND
U2: RFM69HCW; HOPERF_RFM9XW_THT_ikke_through

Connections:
+3.3V: C4.2, C5.2, C6.2, C7.2, C9.2, IC2.33 (VCC_1), IC2.34 (VCC_2), IC3.6 (EN), J1.4 (ID), L2.1, R3.2, U1.1 (VDDA), U1.3 (VDDA3P3), U1.4 (VDDA3P3), U1.19 (VDD3P3_RTC), U1.26 (VDD_SDIO), U1.37 (VDD3P3_CPU), U1.43 (VDDA), U1.46 (VDDA), U2.13 (3.3V)
+5V: BT1.1 (+), IC3.2 (VIN), J1.1 (VBUS)
ANT_BIAS: C2.2, C3.2, IC2.7 (VCC_RF), L1.1
ANT_IN: C1.1, IC2.2 (ANT_IN)
GND: AGPS1.2 (Shield), BT1.2 (-), C2.1, C3.1, C4.1, C5.1, C6.1, C7.1, C9.1, IC2.1 (GND_1), IC2.3 (GND_2), IC2.12 (GND_3), IC2.14 (GND_4), IC2.32 (GND_5), IC2.37 (GND_6), IC2.41 (GND_7), IC2.48 (GND_8), IC2.55 (GROUND_1), IC2.56 (GROUND_2), IC2.57 (GROUND_3), IC2.58 (GROUND_4), IC2.59 (GROUND_5), IC2.60 (GROUND_6), IC2.61 (GROUND_7), IC2.62 (GROUND_8), IC2.63 (GROUND_9), IC2.64 (GROUND_10), IC2.65 (GROUND_11), IC2.66 (GROUND_12), IC2.67 (GROUND_13), IC2.68 (GROUND_14), IC2.69 (GROUND_15), IC2.70 (GROUND_16), IC2.71 (GROUND_17), IC2.72 (GROUND_18), IC2.73 (GROUND_19), IC2.74 (GROUND_20), IC2.75 (GROUND_21), IC2.76 (GROUND_22), IC2.77 (GROUND_23), IC2.78 (GROUND_24), IC2.79 (GROUND_25), IC2.80 (GROUND_26), IC2.81 (GROUND_27), IC2.82 (GROUND_28), IC2.83 (GROUND_29), IC2.84 (GROUND_30), IC2.85 (GROUND_31), IC2.86 (GROUND_32), IC2.87 (GROUND_33), IC2.88 (GROUND_34), IC2.89 (GROUND_35), IC2.90 (GROUND_36), IC2.91 (GROUND_37), IC2.92 (GROUND_38), IC2.93 (GROUND_39), IC2.94 (GROUND_40), IC2.95 (GROUND_41), IC2.96 (GROUND_42), IC2.97 (GROUND_43), IC2.98 (GROUND_44), IC2.99 (GROUND_45), IC2.100 (GROUND_46), IC2.101 (GROUND_47), IC2.102 (GROUND_48), IC3.4 (GND), J1.5 (GND), J1.6 (Shield), R4.2, U1.49 (GND), U2.1 (GND), U2.8 (GND), U2.10 (GND)
GPSANT: AGPS1.1 (A), C1.2, L1.2
GPSRX: IC2.43 (RXD1), U1.41 (U0TXD)
GPSTX: IC2.42 (TXD1), U1.40 (U0RXD)
unnamed: C8.2, IC3.5 (BST)
unnamed: IC3.8 (FB), R3.1, R4.1
unnamed: C8.1, IC3.3 (SW), L2.2
unnamed: J1.3 (D+), R1.1
unnamed: J1.2 (D-), R2.1
unnamed: H1.1, U2.9 (ANT)
SPI_CS: U2.5 (NSS)
SPI_INT: U2.14 (DIO0)
SPI_MISO: U2.2 (MISO)
SPI_MOSI: U2.3 (MOSI)
SPI_SCK: U2.4 (SCK)
USB+: R1.2
USB-: R2.2

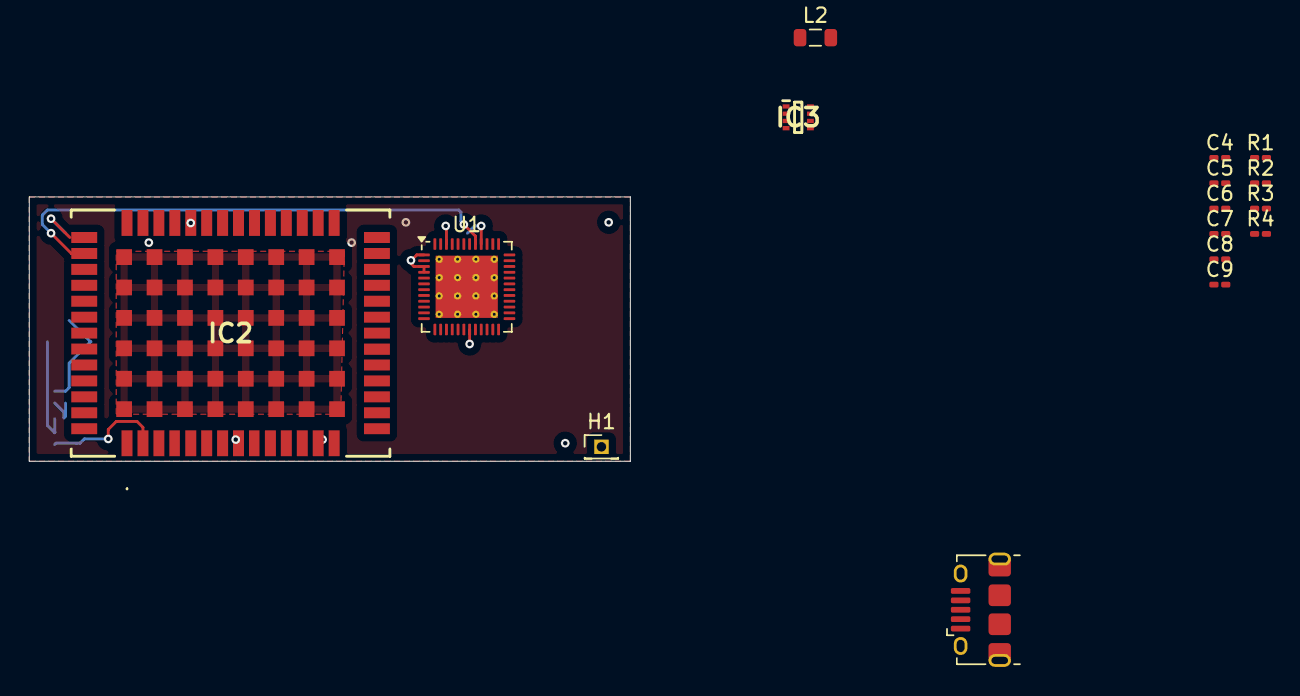
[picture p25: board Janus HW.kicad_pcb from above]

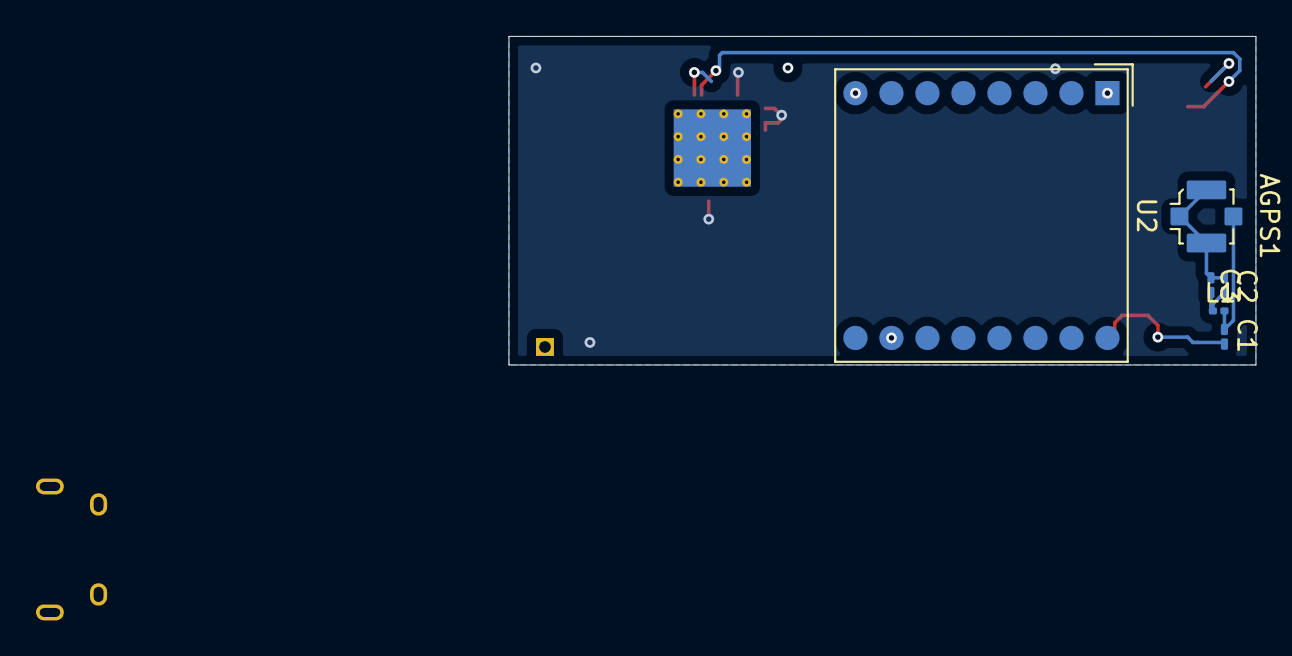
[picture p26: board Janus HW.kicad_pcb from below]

Board: 4 copper layers, 41.5 x 18.2 mm, 22 parts (6 on the bottom side), 14 nets.

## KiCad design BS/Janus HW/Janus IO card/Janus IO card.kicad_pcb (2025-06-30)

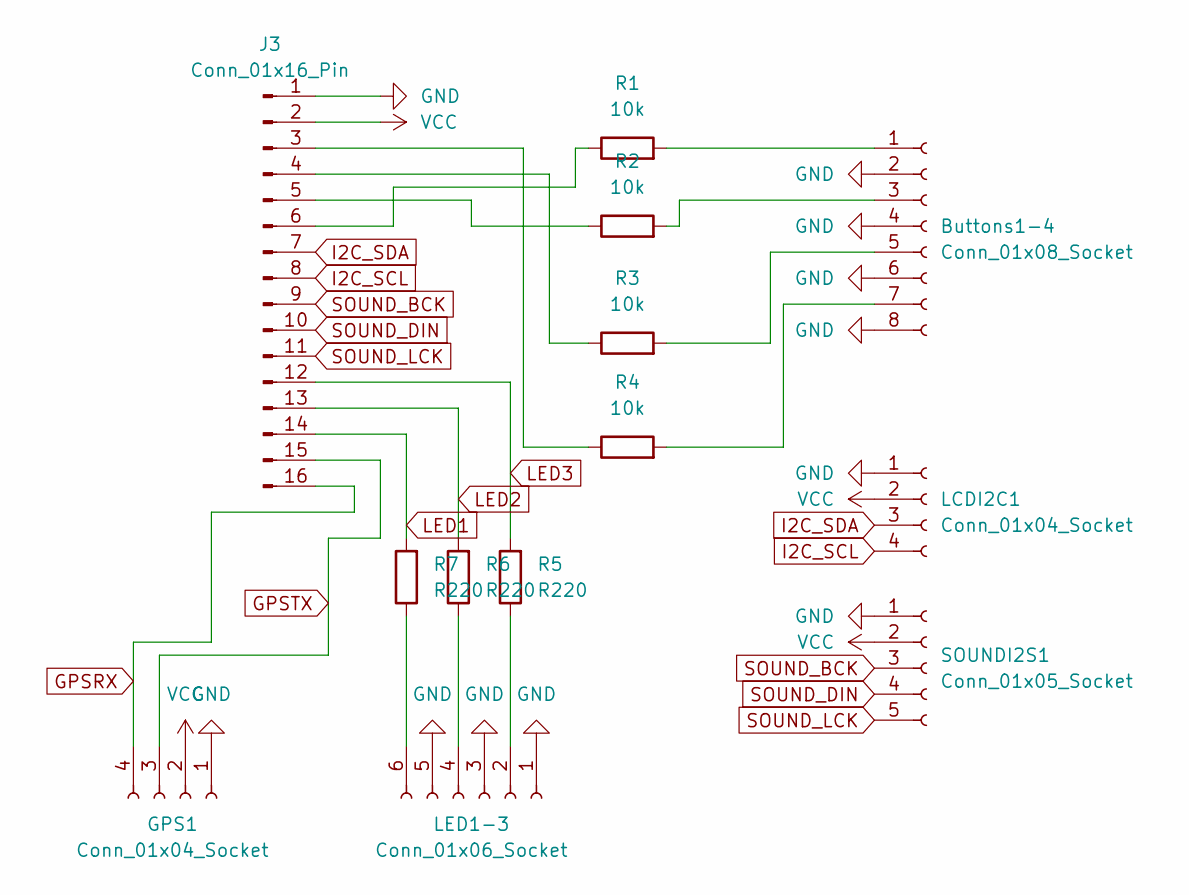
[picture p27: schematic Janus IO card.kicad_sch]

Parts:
Buttons1-4: Conn_01x08_Socket; JST_ZH_B8B-ZR_1x08_P1.50mm_Vertical
GPS1: Conn_01x04_Socket; JST_ZH_B4B-ZR_1x04_P1.50mm_Vertical
J3: Conn_01x16_Pin; TE_1-84952-6_1x16-1MP_P1.0mm_Horizontal
LCDI2C1: Conn_01x04_Socket; JST_ZH_B4B-ZR_1x04_P1.50mm_Vertical
LED1-3: Conn_01x06_Socket; JST_ZH_B6B-ZR_1x06_P1.50mm_Vertical
R1, R2, R3, R4: 10k; R_0805_2012Metric
R5, R6, R7: R220; R_0805_2012Metric
SOUNDI2S1: Conn_01x05_Socket; JST_ZH_B5B-ZR_1x05_P1.50mm_Vertical

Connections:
GND: Buttons1-4.2, Buttons1-4.4, Buttons1-4.6, Buttons1-4.8, GPS1.1, J3.1, LCDI2C1.1, LED1-3.1, LED1-3.3, LED1-3.5, SOUNDI2S1.1
GPSRX: GPS1.4, J3.16
GPSTX: GPS1.3, J3.15
I2C_SCL: J3.8, LCDI2C1.4
I2C_SDA: J3.7, LCDI2C1.3
LED1: J3.14, R7.2
LED2: J3.13, R6.2
LED3: J3.12, R5.2
unnamed: Buttons1-4.1, R1.2
unnamed: Buttons1-4.3, R2.2
unnamed: Buttons1-4.5, R3.2
unnamed: Buttons1-4.7, R4.2
unnamed: J3.3, R4.1
unnamed: J3.4, R3.1
unnamed: J3.5, R2.1
unnamed: J3.6, R1.1
unnamed: LED1-3.2, R5.1
unnamed: LED1-3.4, R6.1
unnamed: LED1-3.6, R7.1
SOUND_BCK: J3.9, SOUNDI2S1.3
SOUND_DIN: J3.10, SOUNDI2S1.4
SOUND_LCK: J3.11, SOUNDI2S1.5
VCC: GPS1.2, J3.2, LCDI2C1.2, SOUNDI2S1.2

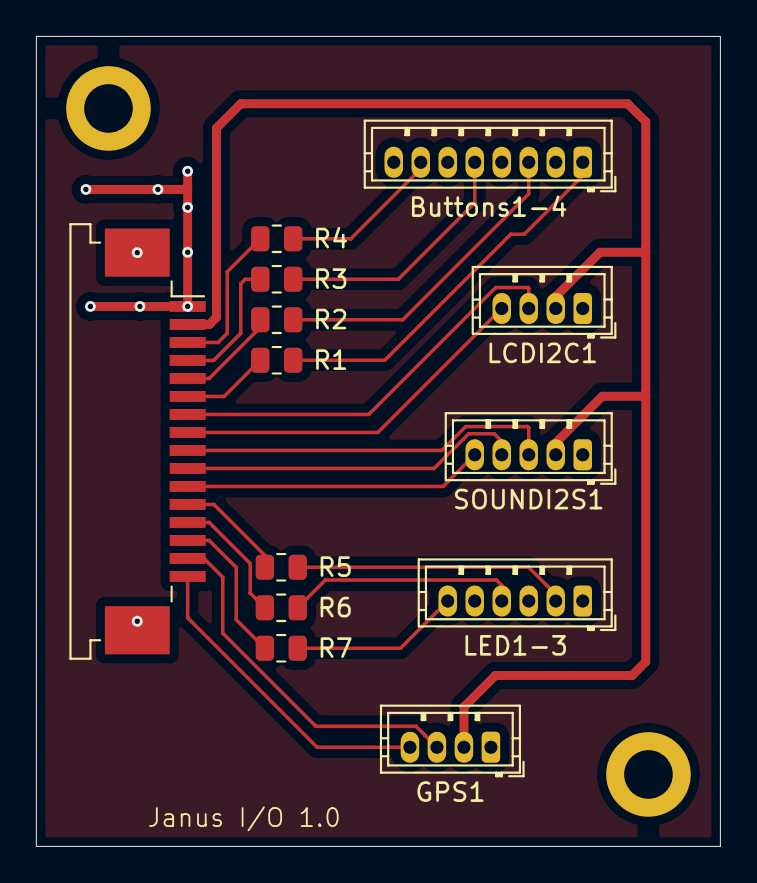
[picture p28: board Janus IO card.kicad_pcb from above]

Board: 2 copper layers, 38.0 x 45.0 mm, 13 parts (0 on the bottom side), 23 nets.

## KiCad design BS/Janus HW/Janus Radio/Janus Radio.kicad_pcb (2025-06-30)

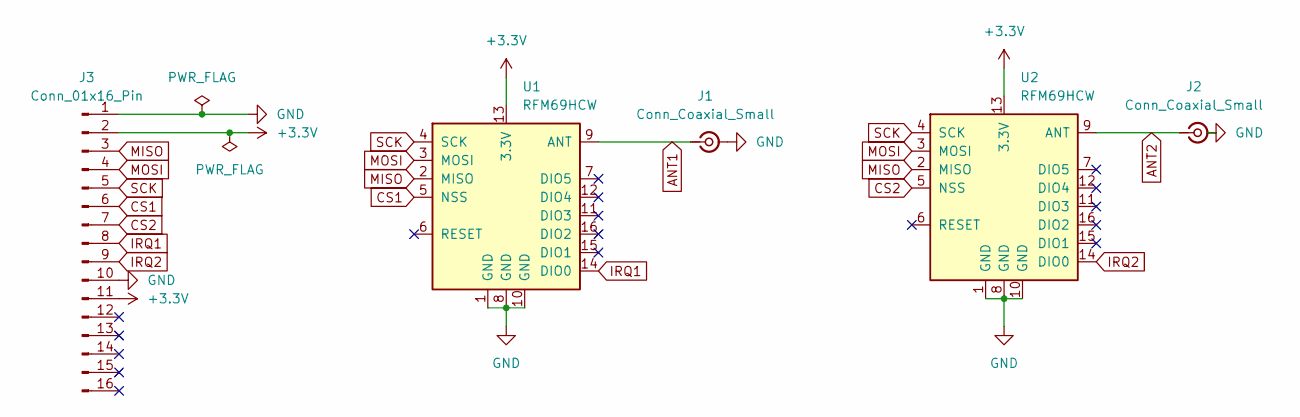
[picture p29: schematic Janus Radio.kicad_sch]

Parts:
J1, J2: Conn_Coaxial_Small; U.FL_Hirose_U.FL-R-SMT-1_Vertical
J3: Conn_01x16_Pin; TE_1-84952-6_1x16-1MP_P1.0mm_Horizontal
U1, U2: RFM69HCW; HOPERF_RFM9XW_SMD

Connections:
+3.3V: J3.2, J3.11, U1.13 (3.3V), U2.13 (3.3V)
ANT1: J1.1 (In), U1.9 (ANT)
ANT2: J2.1 (In), U2.9 (ANT)
CS1: J3.6, U1.5 (NSS)
CS2: J3.7, U2.5 (NSS)
GND: J1.2 (Ext), J2.2 (Ext), J3.1, J3.10, U1.1 (GND), U1.8 (GND), U1.10 (GND), U2.1 (GND), U2.8 (GND), U2.10 (GND)
IRQ1: J3.8, U1.14 (DIO0)
IRQ2: J3.9, U2.14 (DIO0)
MISO: J3.3, U1.2 (MISO), U2.2 (MISO)
MOSI: J3.4, U1.3 (MOSI), U2.3 (MOSI)
SCK: J3.5, U1.4 (SCK), U2.4 (SCK)

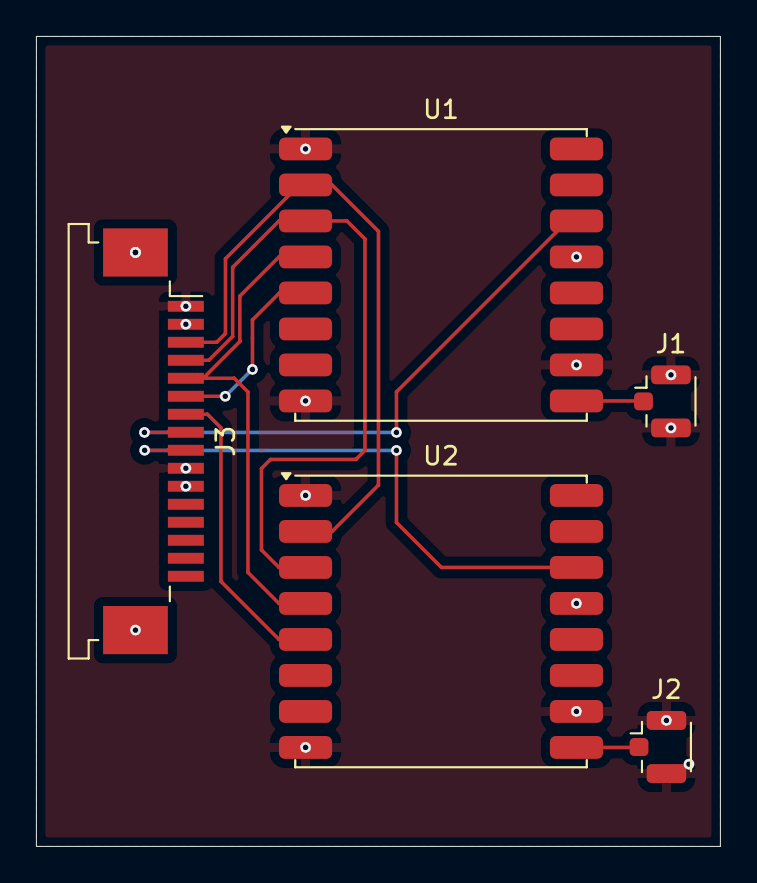
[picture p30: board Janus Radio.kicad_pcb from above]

Board: 4 copper layers, 38.0 x 45.0 mm, 5 parts (0 on the bottom side), 11 nets.

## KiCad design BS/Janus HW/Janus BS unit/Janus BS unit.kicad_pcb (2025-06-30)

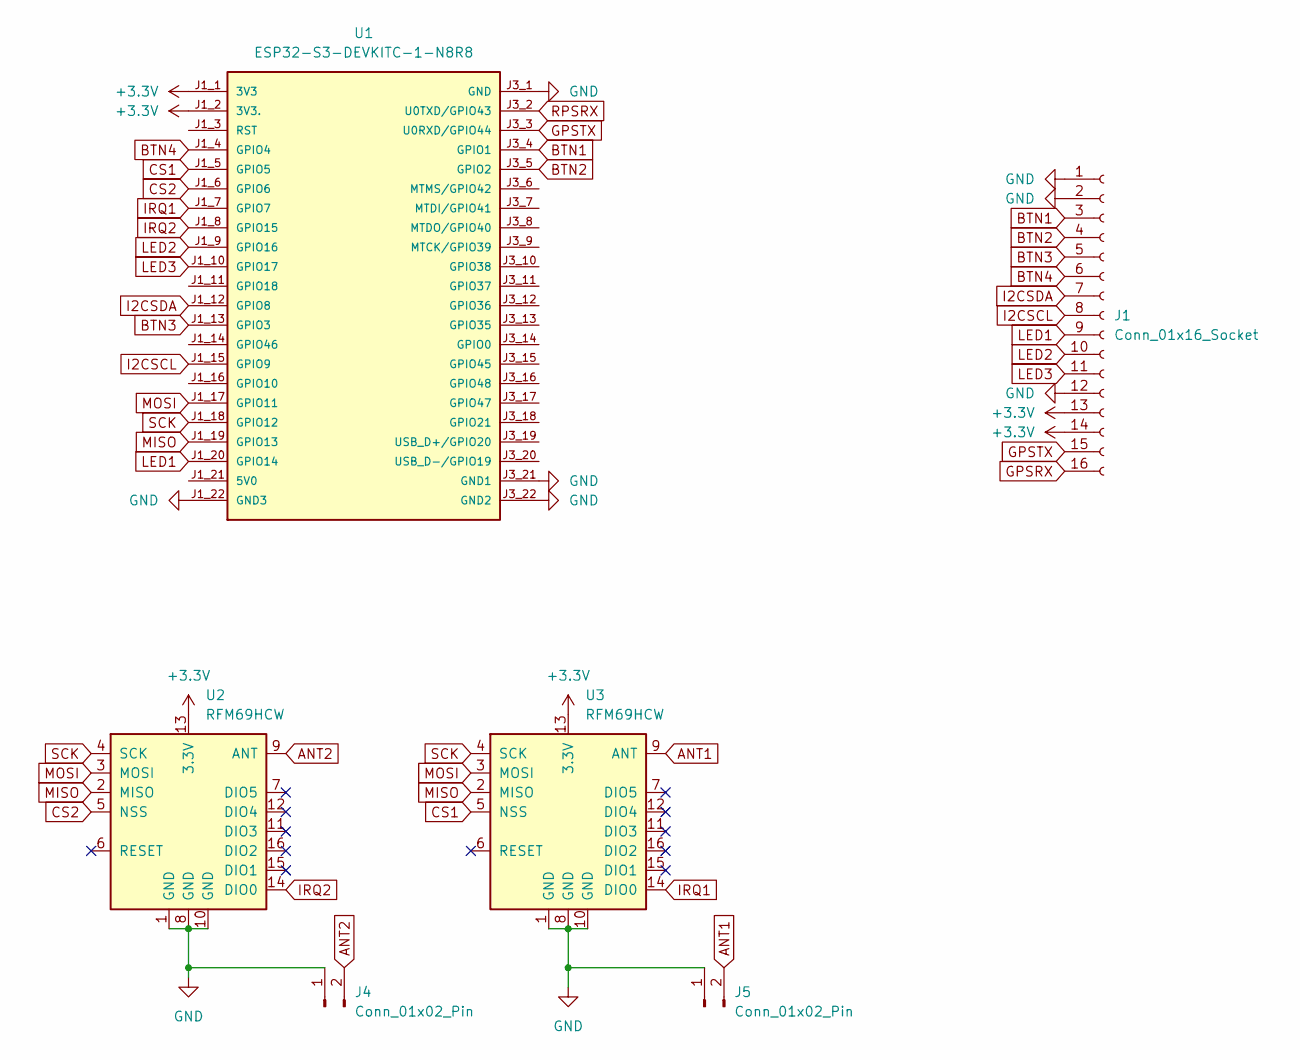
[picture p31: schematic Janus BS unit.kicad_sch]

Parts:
J1: Conn_01x16_Socket; PinSocket_1x16_P2.54mm_Vertical
J4, J5: Conn_01x02_Pin; PinHeader_1x02_P2.54mm_Vertical
U1: ESP32-S3-DEVKITC-1-N8R8
U2, U3: RFM69HCW; HOPERF_RFM9XW_SMD

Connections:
+3.3V: J1.13, J1.14, U1.J1_1 (3V3), U1.J1_2 (3V3.), U2.13 (3.3V), U3.13 (3.3V)
ANT1: J5.2, U3.9 (ANT)
ANT2: J4.2, U2.9 (ANT)
BTN1: J1.3, U1.J3_4 (GPIO1)
BTN2: J1.4, U1.J3_5 (GPIO2)
BTN3: J1.5, U1.J1_13 (GPIO3)
BTN4: J1.6, U1.J1_4 (GPIO4)
CS1: U1.J1_5 (GPIO5), U3.5 (NSS)
CS2: U1.J1_6 (GPIO6), U2.5 (NSS)
GND: J1.1, J1.2, J1.12, J4.1, J5.1, U1.J1_22 (GND3), U1.J3_1 (GND), U1.J3_21 (GND1), U1.J3_22 (GND2), U2.1 (GND), U2.8 (GND), U2.10 (GND), U3.1 (GND), U3.8 (GND), U3.10 (GND)
GPSTX: J1.15, U1.J3_3 (U0RXD/GPIO44)
I2CSCL: J1.8, U1.J1_15 (GPIO9)
I2CSDA: J1.7, U1.J1_12 (GPIO8)
IRQ1: U1.J1_7 (GPIO7), U3.14 (DIO0)
IRQ2: U1.J1_8 (GPIO15), U2.14 (DIO0)
LED1: J1.9, U1.J1_20 (GPIO14)
LED2: J1.10, U1.J1_9 (GPIO16)
LED3: J1.11, U1.J1_10 (GPIO17)
MISO: U1.J1_19 (GPIO13), U2.2 (MISO), U3.2 (MISO)
MOSI: U1.J1_17 (GPIO11), U2.3 (MOSI), U3.3 (MOSI)
SCK: U1.J1_18 (GPIO12), U2.4 (SCK), U3.4 (SCK)

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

Board: 4 copper layers, 94.2 x 105.2 mm, 6 parts (0 on the bottom side), 22 nets.

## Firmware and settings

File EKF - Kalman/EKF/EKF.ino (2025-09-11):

#include <Arduino.h>
#include <Wire.h>
#include "ESKF.h"   // uses global Vec3/Quat/make3()

// ---------------- GNSS types (yours) ----------------
enum class FIXTYPE : uint8_t { NOFIX=0, SPS=1, DGPS=2, RTKFIX=4, RTKFLOAT=5 };

struct GNSSFix {
  int   hour = 0;
  int   minute = 0;
  float second = 0;

  float lat = 0.0f;   // deg
  float lon = 0.0f;   // deg
  float alt = 0.0f;   // m

  float relNorth = 0.0f, relEast = 0.0f, relDown = 0.0f;
  float adjNorth = 0.0f, adjEast = 0.0f, adjDown = 0.0f;

  int   SIV  = 0;
  int   HDOP = 0;     // *100
  FIXTYPE type = FIXTYPE::NOFIX;
};

// ---------------- Pins / ports (ESP32 defaults) ----------------
static constexpr int I2C_SDA = 21;
static constexpr int I2C_SCL = 22;

static constexpr int GNSS_RX = 16; // UM980 TX -> ESP32 RX
static constexpr int GNSS_TX = 17; // UM980 RX <- ESP32 TX
static constexpr uint32_t GNSS_BAUD = 115200;

HardwareSerial SerialGNSS(2);

// ---------------- Simple IMU wrapper (replace) ----------------
struct ImuSample { float gx, gy, gz; float ax, ay, az; };

class MyIMU {
public:
  bool begin(TwoWire& bus) {
    (void)bus;
    // TODO init your IMU
    return true;
  }
  ImuSample read() {
    ImuSample s{}; // TODO fill with SI units (rad/s, m/s^2)
    return s;
  }
};

MyIMU imu;

// ---------------- ESKF + origin ----------------
ESKF ekf;
ESKFConfig cfg;

bool   originSet = false;
double lat0_deg = 0.0, lon0_deg = 0.0;
float  h0_m = 0.0f;
float  lat0_rad = 0.0f;
float  m_per_deg_lat = 111320.0f, m_per_deg_lon = 111320.0f;

bool   havePrevGnss = false;
uint32_t prevGnssMs = 0;
Vec3   prevPn = make3();

// timing
uint32_t lastPrintMs = 0;
uint32_t lastImuMicros = 0;

// ------------- Utils -------------
Vec3 llaToNED(float lat_deg, float lon_deg, float alt_m) {
  float dLat_m = (lat_deg - (float)lat0_deg) * m_per_deg_lat;
  float dLon_m = (lon_deg - (float)lon0_deg) * (m_per_deg_lon * cosf(lat0_rad));
  float dAlt_m = (alt_m - h0_m);
  return make3(dLat_m, dLon_m, -dAlt_m); // NED: down positive
}

bool pollGNSS(GNSSFix& out) {
  (void)out;
  // TODO: your UM980 parser that fills 'out' and returns true on new fix
  return false;
}

float posSigmaForFix(const GNSSFix& f) {
  switch (f.type) {
    case FIXTYPE::RTKFIX:   return 0.03f;
    case FIXTYPE::RTKFLOAT: return 0.10f;
    default:                return 0.25f;
  }
}
float velSigmaForFix(const GNSSFix& f) {
  switch (f.type) {
    case FIXTYPE::RTKFIX:
    case FIXTYPE::RTKFLOAT: return 0.10f;
    default:                return 0.25f;
  }
}

// ---- helpers (put in a small header if you want) ----
static inline float vdot(const Vec3& a, const Vec3& b){ return a.x*b.x + a.y*b.y + a.z*b.z; }
static inline Vec3  vcross(const Vec3& a, const Vec3& b){
  return make3(a.y*b.z - a.z*b.y, a.z*b.x - a.x*b.z, a.x*b.y - a.y*b.x);
}
static inline float vnorm(const Vec3& a){ return sqrtf(vdot(a,a)); }
static inline Vec3  vunit(const Vec3& a){ float n=vnorm(a); return (n>1e-6f)? make3(a.x/n,a.y/n,a.z/n) : make3(0,0,1); }

// Quaternion that rotates unit vector u -> v (both unit)
static inline Quat quatFromTwoUnitVectors(const Vec3& u, const Vec3& v){
  float d = vdot(u,v);
  if (d > 0.999999f) return {1,0,0,0};         // almost same
  if (d < -0.999999f){                          // opposite: choose any orthogonal axis
    Vec3 ortho = fabsf(u.x) < 0.9f ? make3(1,0,0) : make3(0,1,0);
    Vec3 axis = vunit(vcross(u, ortho));
    return {0, axis.x, axis.y, axis.z};        // 180° rotation
  }
  Vec3 axis = vcross(u,v);
  Quat q = { 1.0f + d, axis.x, axis.y, axis.z };
  ESKF::quatNormalize(q);
  return q;
}

// Rotate body vector to NED with Rnb(q)
static inline Vec3 rotateBodyToNED(const Quat& q, const Vec3& vb){
  float R[9]; ESKF::Rnb(q, R);
  return make3(
    R[0]*vb.x + R[1]*vb.y + R[2]*vb.z,
    R[3]*vb.x + R[4]*vb.y + R[5]*vb.z,
    R[6]*vb.x + R[7]*vb.y + R[8]*vb.z
  );
}

// ---- calibration result ----
struct CalibResult {
  Vec3 bg;     // gyro bias (rad/s)
  Vec3 ba;     // accel bias (m/s^2)
  Quat q0;     // initial attitude (body->NED) with yaw=0
  float g_est; // local gravity magnitude
};

// imu.read() must return SI: gyro rad/s, accel m/s^2
CalibResult calibrateStillAnyOrientation(MyIMU& imu, float seconds=6.0f, uint32_t rate_hz=400){
  const uint32_t N = (uint32_t)(seconds * rate_hz);
  const uint32_t us = 1000000UL / rate_hz;

  Vec3 sumG = make3(), sumA = make3();

  for (uint32_t k=0;k<N;k++){
    ImuSample s = imu.read();
    sumG.x += s.gx; sumG.y += s.gy; sumG.z += s.gz;
    sumA.x += s.ax; sumA.y += s.ay; sumA.z += s.az;
    delayMicroseconds(us);
  }

  Vec3 meanG = make3(sumG.x/N, sumG.y/N, sumG.z/N);
  Vec3 meanA = make3(sumA.x/N, sumA.y/N, sumA.z/N);

  // 1) Gyro bias
  Vec3 bg = meanG;

  // 2) Gravity magnitude and direction in body frame
  float g_est = vnorm(meanA);
  Vec3 a_hat  = (g_est > 1e-4f) ? make3(meanA.x/g_est, meanA.y/g_est, meanA.z/g_est) : make3(0,0,1);

  // 3) Initial attitude: rotate body a_hat to NED gravity dir [0,0,+1]
  Vec3 gdir_ned = make3(0,0,1);
  Quat q0 = quatFromTwoUnitVectors(a_hat, gdir_ned); // body->NED, yaw=0

  // 4) Accel bias: meanA = R^T * [0,0,+g_est] + ba  ->  ba = meanA - R^T*g
  // Compute R^T*g by rotating NED->[body] (inverse rotation): use q^{-1}
  Quat qi = { q0.w, -q0.x, -q0.y, -q0.z }; // unit inverse
  Vec3 g_ned = make3(0,0,g_est);
  // rotate NED vector into body frame with qi (NED->body):
  float Rnb[9]; ESKF::Rnb(qi, Rnb); // note: with qi this implements Rbn
  Vec3 g_body = make3(
    Rnb[0]*g_ned.x + Rnb[1]*g_ned.y + Rnb[2]*g_ned.z,
    Rnb[3]*g_ned.x + Rnb[4]*g_ned.y + Rnb[5]*g_ned.z,
    Rnb[6]*g_ned.x + Rnb[7]*g_ned.y + Rnb[8]*g_ned.z
  );
  Vec3 ba = make3(meanA.x - g_body.x, meanA.y - g_body.y, meanA.z - g_body.z);

  // (Optionally zero tiny components)
  if (fabsf(ba.x) < 1e-3f) ba.x = 0;
  if (fabsf(ba.y) < 1e-3f) ba.y = 0;
  if (fabsf(ba.z) < 1e-3f) ba.z = 0;

  return { bg, ba, q0, g_est };
}


// ------------- Setup -------------
void setup() {
  Serial.begin(115200);
  delay(300);
  Serial.println("\nEKF demo: IMU + GNSS (NED)");

  Wire.begin(I2C_SDA, I2C_SCL, 400000);
  if (!imu.begin(Wire)) Serial.println("IMU init failed!");

  SerialGNSS.begin(GNSS_BAUD, SERIAL_8N1, GNSS_RX, GNSS_TX);

  cfg.sigma_g   = 0.02f;
  cfg.sigma_a   = 0.25f;
  cfg.sigma_bg  = 0.0005f;
  cfg.sigma_ba  = 0.01f;
  cfg.sigma_gnss_pos = 0.20f;
  cfg.sigma_gnss_vel = 0.15f;
  cfg.sigma_yaw_cog  = 2.0f * (float)M_PI / 180.0f;

  ekf = ESKF(cfg);

CalibResult C = calibrateStillAnyOrientation(imu, 6.0f, 400);

// Save to NVS if you want (bg, ba, q0)
ekf.reset(
  /*p0*/ make3(0,0,0),
  /*v0*/ make3(0,0,0),
  /*q0*/ C.q0,           // roll/pitch from gravity, yaw=0
  /*bg*/ C.bg,
  /*ba*/ C.ba,
  /*Pdiag*/ 1.0f
);

  lastImuMicros = micros();
}

// ------------- Loop -------------
void loop() {
  // 1) IMU predict
  uint32_t nowUs = micros();
  float dt = (nowUs - lastImuMicros) * 1e-6f;
  if (dt <= 0) dt = 1e-4f;
  lastImuMicros = nowUs;

  ImuSample s = imu.read();
  ekf.predict(dt, make3(s.gx, s.gy, s.gz), make3(s.ax, s.ay, s.az));

  // 2) GNSS updates
  GNSSFix fix;
  if (pollGNSS(fix)) {
    if (!originSet && fix.type != FIXTYPE::NOFIX) {
      lat0_deg = fix.lat;
      lon0_deg = fix.lon;
      h0_m     = fix.alt;
      lat0_rad = (float)(lat0_deg * DEG_TO_RAD);
      ESKF::nedMetersPerDeg(lat0_rad, m_per_deg_lat, m_per_deg_lon);
      originSet = true;
      Serial.printf("Origin set: lat=%.7f lon=%.7f h=%.2f\n", lat0_deg, lon0_deg, h0_m);
    }

    if (originSet) {
      bool haveRelpos = (fabsf(fix.relNorth) > 0.001f || fabsf(fix.relEast) > 0.001f || fabsf(fix.relDown) > 0.001f);
      Vec3 p_ned;
      if (haveRelpos) {
        p_ned = make3(fix.relNorth + fix.adjNorth,
                      fix.relEast  + fix.adjEast,
                      fix.relDown  + fix.adjDown);
      } else {
        p_ned = llaToNED(fix.lat, fix.lon, fix.alt);
      }

      ekf.updatePositionNED(p_ned, posSigmaForFix(fix));

      uint32_t nowMs = millis();
      if (havePrevGnss) {
        float dtv = (nowMs - prevGnssMs) * 1e-3f;
        if (dtv > 0.02f && dtv < 0.5f) {
          Vec3 v_meas = make3(
            (p_ned.x - prevPn.x)/dtv,
            (p_ned.y - prevPn.y)/dtv,
            (p_ned.z - prevPn.z)/dtv
          );
          ekf.updateVelocityNED(v_meas, velSigmaForFix(fix));
          ekf.updateYawFromVelocity(v_meas, cfg.sigma_yaw_cog);
        }
      }
      prevPn = p_ned;
      prevGnssMs = nowMs;
      havePrevGnss = true;
    }
  }

  // 3) Debug @ ~10 Hz
  uint32_t nowMs = millis();
  if (nowMs - lastPrintMs > 100) {
    lastPrintMs = nowMs;
    const auto& st = ekf.state();

    // yaw from Rnb
    float R[9];
    {
      const float w=st.q.w,x=st.q.x,y=st.q.y,z=st.q.z;
      const float ww=w*w, xx=x*x, yy=y*y, zz=z*z;
      const float wx=w*x, wy=w*y, wz=w*z;
      const float xy=x*y, xz=x*z, yz=y*z;
      R[0]=ww+xx-yy-zz; R[1]=2*(xy-wz);   R[2]=2*(xz+wy);
      R[3]=2*(xy+wz);   R[4]=ww-xx+yy-zz;R[5]=2*(yz-wx);
      R[6]=2*(xz-wy);   R[7]=2*(yz+wx);  R[8]=ww-xx-yy+zz;
    }
    float yaw = atan2f(R[1], R[0]) * RAD_TO_DEG;

    Serial.printf("p[NED]=[%.2f %.2f %.2f] v=[%.2f %.2f %.2f] yaw=%.1f bg=[%.3f %.3f %.3f] ba=[%.2f %.2f %.2f]\n",
      st.p.x, st.p.y, st.p.z,
      st.v.x, st.v.y, st.v.z,
      yaw,
      st.bg.x, st.bg.y, st.bg.z,
      st.ba.x, st.ba.y, st.ba.z
    );
  }
}

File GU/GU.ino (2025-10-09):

// GU.ino
#include <Arduino.h>
#include <HardwareSerial.h>
#include "_macros.h"
#include <RFM69.h>
#include <RTKF3F.h>
#include "GU.h"

#include "Glider.h"
#include "Arena.h"

#include <WiFi.h>
#include <WebServer.h>
#include <ArduinoJson.h>
#include "src/UI.h"

#define APPNAME "GU 1.0"
#define THIS_NODE_ID NODEID_GU
#define COMMANDDELAY 1000  // ms to wait for GNSS command response

// Define your ESP model (uncomment the one you're using)
#define XIAO_ESP32C6
// #define ESP32S3

// Radio pins
#if defined(XIAO_ESP32C6)
inline constexpr int8_t RFM69_CSS  = 16; // Hvit
inline constexpr int8_t RFM69_SCK  = 19; // Grå
inline constexpr int8_t RFM69_MOSI = 18; // Magenta
inline constexpr int8_t RFM69_MISO = 20; // Blå
inline constexpr int8_t RFM69_IRQ  = 17; // Gul

// UART (GNSS)
#define UART_RX   4
#define UART_TX   5

#elif defined(ESP32S3)
inline constexpr int8_t RFM69_CSS  = 10;
inline constexpr int8_t RFM69_SCK  = 12;
inline constexpr int8_t RFM69_MOSI = 11;
inline constexpr int8_t RFM69_MISO = 13;
inline constexpr int8_t RFM69_IRQ  = 14;

// UART (GNSS)
#define UART_RX   17
#define UART_TX   18

#else
#error "No ESP model defined! Please define XIAO_ESP32C6, ESP32S3, or ESP32C3"
#endif

// Common definitions (apply to all models)
inline constexpr int8_t RFM69_IRQN = digitalPinToInterrupt(RFM69_IRQ);
inline constexpr int8_t RFM69_RST  = -1;

#define GNSS_BAUD 115200

HardwareSerial SerialGNSS(2);
GNSSModule gnss(SerialGNSS);

RadioModule radio(RFM69_CSS, RFM69_IRQ, true);
RadioModule::RTCM_Reassembler reassembler;

Arena  arena;
Glider glider;
GNSSFix fix;
bool showFix = false;
bool showRTKStatus = false;

// static unsigned long lastSpeakMs = 0;
#define SPEAK_INTERVAL_MS 30000

static inline void haltUnit(const String& msg1, const String& msg2) {
    Serial.print(msg1); Serial.print(": "); Serial.println(msg2);
    while (true);
}

void setup() {
    Serial.begin(115200);
    while (!Serial);
    delay(200);
    Serial.printf("%s starting\n", APPNAME);




    if (!radio.init(RFM69_MISO, RFM69_MOSI, RFM69_SCK, THIS_NODE_ID, NETWORK_ID, FREQUENCY_RTCM)) {
        while (true) delay(100);
    }

    radio.sendMessageCode(NODEID_CD, FREQUENCY_CD, FREQUENCY_RTCM, MSG_DEVICESTATE,
        static_cast<uint8_t>(DEVICE_STARTING));

    Serial.println("Radio started");

    // GNSS
    gnss.begin(GNSS_BAUD, UART_RX, UART_TX);
	gnss.setRadio(&radio);  
    
    //delay(1000);
    gnss.clearUARTBuffer();

    if (!gnss.sendWait("\r\nunlog", "response: OK", COMMANDDELAY)) {
        //haltUnit("GNSS", "- No [unlog] response");
    }

    if (!gnss.sendWait("config", "$CONFIG, COM3", 3000)) {
        Serial.println("- Show GPS config fail");
    }

    // Configure rover
    if (!gnss.sendWait("config pvtalg multi"       ,"response: OK", COMMANDDELAY) ||
        !gnss.sendWait("config rtk timeout 120"    ,"response: OK", COMMANDDELAY) ||
        !gnss.sendWait("config rtk reliability 3 1","response: OK", COMMANDDELAY) ||
        !gnss.sendWait("mode rover uav highdyn"    ,"response: OK", COMMANDDELAY) ||
        !gnss.sendWait("gpgga com2 0.05"            ,"response: OK", COMMANDDELAY)) {
            Serial.println("- GPS config fail");
    } else {
        radio.sendMessageCode(NODEID_CD, FREQUENCY_CD, FREQUENCY_RTCM, MSG_DEVICESTATE, DEVICE_STARTING);
        Serial.println(APPNAME " ready!");
        showMenu();
	} 

    setupWebServer();  // Add this line

}

void processGNSSData() {
    bool res = false;
    res = gnss.pumpGGA(fix);
    if (res && showFix) {
        Serial.printf("GGA OK: Time=%02d:%02d:%.2f" ANSI_GREEN " FIX = %u " ANSI_RESET "SIV = %d HDOP = %.2f lat = %.8f lon = %.8f elev = %.2f\n",
            fix.hour, fix.minute, fix.second, (unsigned)fix.type, fix.SIV, fix.HDOP, fix.lat, fix.lon, fix.elevation);
    }
    sendPeriodicUpdate();
}

void sendPeriodicUpdate() {
    static unsigned long lastSpeakMs = 0;
    if (millis() - lastSpeakMs >= SPEAK_INTERVAL_MS) {
        radio.sendMessageCode(NODEID_CD, FREQUENCY_CD, FREQUENCY_RTCM, MSG_SIV, fix.SIV);
        lastSpeakMs = millis();
    }
}

void processRadioPackets() {
    uint8_t buffer[255];
    size_t len = sizeof(buffer);

    if (radio.receive(buffer, len) && len > 0) {
        webStatus.lastRSSI = radio.getLastRSSI();
        webStatus.radioConnected = true;
        webStatus.lastUpdate = millis();
        handleRadioMessage(buffer, len);
    }
    else {
        // Check for radio timeout
        if (millis() - webStatus.lastUpdate > 10000) {
            webStatus.radioConnected = false;
        }
    }
}

void handleRadioMessage(const uint8_t* buffer, size_t len) {
    if (!buffer || len == 0) return;

    switch (buffer[0]) {
    case MSG_RTCM:
        handleFullRTCM(buffer, len);
        break;

    case MSG_RTCM_FRAGMENT:
        handleFragmentedRTCM(buffer, len);
        break;

    case MSG_ARENA_SETTINGS:
        handleArenaSettings(buffer, len);
        break;

    case MSG_REQ_POS:
        handlePositionRequest(buffer, len);
        break;

    case MSG_SIV:
        handleSIVMessage(buffer, len);
        break;

    default:
        handleUnknownMessage(buffer, len);
        break;
    }
}
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

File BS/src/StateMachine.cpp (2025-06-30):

// StateMachine.cpp
#include <Arduino.h>
#include <cmath>
#include <LiquidCrystal_I2C.h>
#include <RTKF3F.h>
#include "StateMachine.h"
#include "BSx.h"

extern LiquidCrystal_I2C lcd;
extern Slope slope;

void directionAndDistance(int n, int e, int d, int &angle, float &dist) {
    // Beregn horisontal avstand i N/E-plan
    dist = sqrt(n * n + e * e);

    // Beregn vinkel fra nord (0° = nord, 90° = øst, osv.)
    float angleRad = atan2(e, n);
    float angleDeg = angleRad * 180.0 / M_PI;

    // Normaliser til 0–359°
    if (angleDeg < 0) angleDeg += 360.0;

    angle = (int)(round(angleDeg));
}

String formatTimeMSS(unsigned long ms) {
    unsigned int minutes = (ms/1000)/ 60;
    unsigned int secs = (ms/1000) % 60;
    char buffer[12];  
    snprintf(buffer, sizeof(buffer), "%02u:%02u", minutes, secs);
    return String(buffer);
}

String formatTimeSSS(unsigned long ms) {
    unsigned seconds = ms / 1000;
    unsigned fraction = (ms % 1000) / 10;  // 2 desimaler
    char buffer[12];  
    snprintf(buffer, sizeof(buffer), "%03u.%02u", seconds, fraction);
    return String(buffer);
}

void padRight(char* buffer, size_t totalLength) {
    size_t len = strlen(buffer);
    if (len < totalLength) {
        memset(buffer + len, ' ', totalLength - len);  // fill with spaces
        buffer[totalLength] = '\0';                    // null-terminate
    }
    else if (len > totalLength) {
        buffer[totalLength] = '\0';  // truncate if too long (just in case)
    }
}

void StateMachine::begin() {
    bsState = BS_WAITING;
    bsTaskState = TASK_UNKNOWN;
    startTimestamp = 0;
    finishTimestamp = 0;
}

void StateMachine::handleEvent(EventCode event) {
    switch (bsTaskState) {
        case TASK_UNKNOWN:
            if (event == EVT_CROSS_A_OUT)
                bsTaskState = TASK_OUTSIDE_A;
            break;

        case TASK_OUTSIDE_A:
            if (event == EVT_CROSS_A_IN)
                bsTaskState = TASK_STARTED;
                startTimestamp = millis();
            break;

        case TASK_STARTED:
            if (event == EVT_CROSS_B_OUT)
                bsTaskState = TASK_TURN1;
            break;

        case TASK_TURN1:
            if (event == EVT_CROSS_A_OUT)
                bsTaskState = TASK_TURN2;
            break;

        case TASK_TURN2:
            if (event == EVT_CROSS_B_OUT)
                bsTaskState = TASK_TURN3;
            break;

        case TASK_TURN3:
            if (event == EVT_CROSS_A_OUT)
                bsTaskState = TASK_TURN4;
            break;

        case TASK_TURN4:
            if (event == EVT_CROSS_B_OUT)
                bsTaskState = TASK_TURN5;
            break;

        case TASK_TURN5:
            if (event == EVT_CROSS_A_OUT)
                bsTaskState = TASK_TURN6;
            break;

        case TASK_TURN6:
            if (event == EVT_CROSS_B_OUT)
                bsTaskState = TASK_TURN7;
            break;

        case TASK_TURN7:
            if (event == EVT_CROSS_A_OUT)
                bsTaskState = TASK_TURN8;
            break;

        case TASK_TURN8:
            if (event == EVT_CROSS_B_OUT)
                bsTaskState = TASK_TURN9;
            break;

        case TASK_TURN9:
            if (event == EVT_CROSS_A_OUT) {
                bsTaskState = TASK_FINISHED;
                finishTimestamp = millis();
            }
            break;

        case TASK_FINISHED:
            if (millis() - finishTimestamp > 5000) {
                bsTaskState = TASK_UNKNOWN;
            }
            break;

        default:
            break;
    }
}

void StateMachine::handleButton(int buttonId) {

    Serial.print("Handling button ");
    switch(buttonId) {
        case BTN_MNU: Serial.print("BTN_MNU"); break;
        case BTN_INC: Serial.print("BTN_INC"); break;
        case BTN_DEC: Serial.print("BTN_DEC"); break;
        case BTN_ESC: Serial.print("BTN_ESC"); break;
        default: Serial.print("???"); break;
    }
    Serial.print(", BS_STATE was ");
    Serial.print(bsState);

    switch (buttonId) {
        case BTN_ESC:
            bsState = BS_AIRBORNE;
            bsTaskState = TASK_UNKNOWN;
            sendFlightSettings(slope);
            break;

        case BTN_MNU:
            switch (bsState) {
                case BS_WAITING:        bsState = BS_SEL_GLIDER; break;
                case BS_AIRBORNE:       bsState = BS_SEL_GLIDER; break;
                case BS_ONGROUND:       bsState = BS_SEL_GLIDER; break;
                case BS_SEL_GLIDER:     bsState = BS_SEL_A_RIGHT; break;
                case BS_SEL_A_RIGHT:    bsState = BS_SEL_SLOPEANGLE; break;
                case BS_SEL_SLOPEANGLE: bsState = BS_SET_PLOC; break;
                case BS_SET_PLOC:       bsState = BS_SEL_GLIDER; break;
                default: break;
            }
            break;

        case BTN_INC:
            switch (bsState) {
                case BS_SEL_GLIDER:     slope.incrementGliderId(1); break;
                case BS_SEL_A_RIGHT:    slope.toggleABaseSide(); break;
                case BS_SEL_SLOPEANGLE: slope.incrementSlopeAngle(5); break;
                case BS_SET_PLOC:       sendPosRequest(slope); break;
                default: simTask(); break;
            }
            break;

        case BTN_DEC:
            switch (bsState) {
                case BS_SEL_GLIDER:     slope.incrementGliderId(-1); break;
                case BS_SEL_A_RIGHT:    slope.toggleABaseSide(); break;
                case BS_SEL_SLOPEANGLE: slope.incrementSlopeAngle(-5); break;
                case BS_SET_PLOC:       sendPosRequest(slope); break;
                default: simTask(); break;
            }
            break;
    }
    Serial.print(" now ");
    Serial.println(bsState);
}
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

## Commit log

2025-05-26 Kicad hardware design
    [Janus HW-B_Cu.gbr, Janus HW-B_Mask.gbr, Janus HW-B_Paste.gbr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]
2025-05-27 Fiddling in Kicad
    [Janus HW-B_Cu.gbr, Janus HW-B_Mask.gbr, Janus HW-B_Paste.gbr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]
2025-06-30 A lot of stuff
    [Janus BS unit.kicad_pcb, Janus BS unit.kicad_sch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]
2025-07-10 Status before swapping GNSS lib
    [RTKBase.ino, lytt.ino, send.ino]
2025-07-28 Understanding RFM69HCW boardcast
2025-08-03 Issues with large RTCMs
    [GU.ino, RTKBase.ino, RadioModule.cpp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]
2025-08-05 Playing information and errors
    [CD.ino, GU.ino, RTKBase.ino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]
2025-08-06 Fixed bug in RTCM segmenter
    [CD.ino, GU.ino]
2025-08-15 RFM bug was nullptr in init()
    [GU.ino, RTKBase.ino, RadioModule.cpp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]
2025-09-11 Moved away from tasks/queues
    [ESP32-S3-WROOM-1_devkit_2xUSBC.FCStd, Generic Li Ion 1850 cell.step, Kolíková lišta přímá krátká - 2,54mm.SLDPRT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]
2025-10-08 GU and BASE now working: Got FixType=5
    [GNSS.cpp, GU.ino, RTKBase.ino]
